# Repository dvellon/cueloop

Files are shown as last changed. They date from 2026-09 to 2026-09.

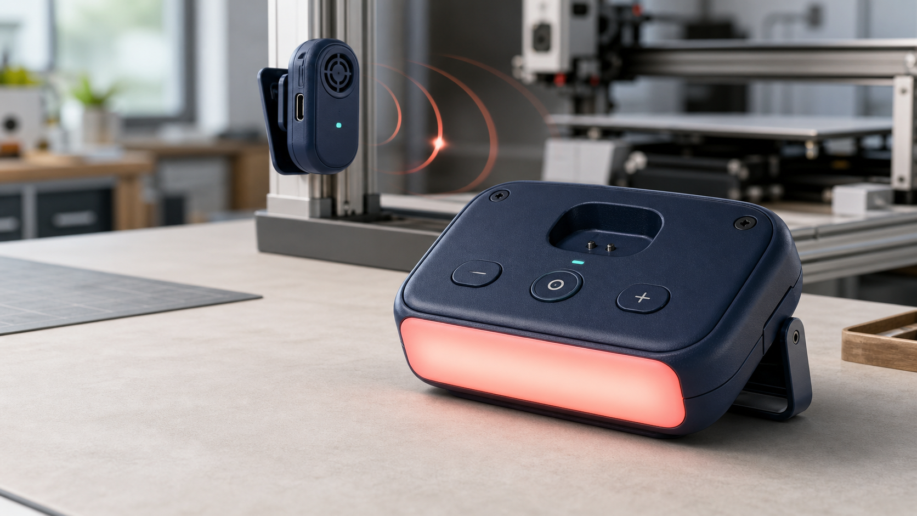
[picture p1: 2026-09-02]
assets/concepts/cueloop-bridge-cover-concept-v1.png

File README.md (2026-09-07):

# CueLoop

**Know what needs your attention without continuously listening, recording, or remaining in the same room.**

CueLoop is a private, local-first acoustic event bridge. A detachable Seeed Studio XIAO ESP32S3 Sense pod sends live microphone evidence over the local network to an Arduino UNO Q. The UNO Q performs edge inference, combines confidence across time, asks for more evidence when a result is ambiguous, and emits an accessible cue through its deterministic MCU and a local dashboard. Raw audio is discarded by default after inference.

This repository develops two related, deliberately distinct products:

- **CueLoop V1** — a reproducible social-impact prototype for the 2026 *Invent the Future with Arduino UNO Q and App Lab* competition.
- **CueLoop Bridge V2** — a portable, serviceable multi-space tool for Autodesk users, developed for *Build the Autodesk University 2027 Product*.

CueLoop is an awareness aid. It is not a safety-certified alarm, security system, or medical device, and it must not replace required alarms or supervision.

## Current state

Development began on September 1, 2026. Hardware-dependent results are intentionally separated from simulator and development-computer results. See [STATUS.md](STATUS.md), [PLAN.md](PLAN.md), [HARDWARE_TESTS.md](HARDWARE_TESTS.md), and [HARDWARE_RESULTS.md](HARDWARE_RESULTS.md) for the live record.

Both firmware targets and the exact isolated App Lab sketch profile compile on the documented Ubuntu toolchain. The complete CPython 3.13/Linux ARM64 LiteRT distribution set is version/hash audited without installation, including native AArch64 ELF inspection; target App Lab loading and inference remain physical gates. `./scripts/build_firmware.sh` performs clean, path-normalized, fixed-epoch builds; `./scripts/verify_clean_checkout.sh` reproduces the complete digital release path in a new local clone. The complete App Lab import archive can be generated locally with `python3 scripts/package_app_lab.py`; no claim is made that it has run on physical boards yet.

## Quick start

The simulator-first path runs without boards or third-party Python packages:

```bash
./scripts/demo.sh
```

The command starts a simulated CuePod, framed TCP receiver, bounded jitter/window buffer, uncertainty-aware event engine, metadata-only store, API, and accessible local dashboard at `http://127.0.0.1:8080`. Every synthetic result is visibly labeled `simulated`; it is pipeline evidence, not real sound-model evidence. Run `./scripts/test.sh` for the automated suite, `python3 scripts/audit_unoq_runtime.py --download` for the target-distribution audit, `./scripts/build_firmware.sh` for all three Arduino builds, and `./scripts/verify_clean_checkout.sh` for the release-grade fresh-checkout audit.

## Repository map

- `app_lab/` — Arduino App Lab package for the UNO Q Linux and MCU sides
- `firmware/` — standalone XIAO CuePod and UNO Q MCU firmware
- `linux/` — receiver, inference, decision engine, API, and dashboard
- `shared/` — protocol, event schema, and constants
- `simulator/` — synthetic sender, WAV replay, loss, jitter, and latency injection
- `models/` — model selection, preprocessing, conversion, provenance, and evaluation
- `experiments/` — predeclared experiment registry, schema, and result boundaries
- `benchmarks/` — evidence-labeled benchmark methods and curated summaries
- `tests/` — unit, protocol, integration, and evaluation tests
- `hardware/` — exact/estimated BOMs, wiring, schematics, power, and assembly
- `cad/` — native Fusion generator, OpenCascade reference exports/validation, parameters, DFM/provenance, and Windows evidence runbook
- `submissions/` — separate competition-ready packages and differentiation record
- `docs/` — product, architecture, privacy, safety, build, test, and demo guidance
- `user_checklists/` — short physical-action checklists and result capture locations

## Safety and privacy

- Never solder while a LiPo battery is connected.
- Never solder directly to a LiPo cell.
- Confirm polarity and continuity before first battery connection.
- Do not substitute a Qwiic cable for the battery pigtail.
- Keep Wi-Fi credentials in ignored local configuration only.
- Do not add private or copyrighted recordings to Git.

Read [docs/safety.md](docs/safety.md) before hardware work and [docs/privacy-model.md](docs/privacy-model.md) before changing audio retention behavior.

For physical work, begin with [the deadline-ordered next actions](user_checklists/NEXT_ACTIONS.md), then execute the authoritative [Windows flashing and hardware test record](HARDWARE_TESTS.md). The [short hardware bring-up checklist](user_checklists/HARDWARE_BRINGUP.md), [Windows quick guide](user_checklists/WINDOWS_FLASHING.md), and [physical validation matrix](user_checklists/PHYSICAL_VALIDATION.md) are compact views. The editable connectivity source and human schematic are under `hardware/schematics/`.

## License

Unless a file says otherwise, code, documentation, and original design source in this repository are licensed under the [MIT License](LICENSE). Third-party models, audio, code, and assets retain their own licenses and must be listed in the relevant provenance manifests.

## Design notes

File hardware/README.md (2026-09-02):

# CueLoop V1 hardware package

This folder is the source of truth for the physical V1 build. It deliberately separates confirmed manufacturer facts, development-computer build evidence, estimates, and observations that still require the received hardware.

- `BOM.md` defines the minimum working product, optional inventory-gated additions, tools, and the distinct V2 development BOM.
- `WIRING.md` defines every external V1 connection and pin assignment.
- `POWER.md` contains power paths, bandwidth arithmetic, runtime estimates, and the measurement plan.
- `ASSEMBLY.md` gives the battery-safe assembly sequence.
- `DIAGRAMS.md` contains the wireless/system, processor-responsibility, power, and protocol views.
- `schematics/cueloop_v1.netlist.json` is the machine-readable connectivity source.
- `schematics/cueloop_v1.svg` is the human-readable schematic export.

No Qwiic cable is used by the minimum CuePod. No wire connects the CuePod to the UNO Q during use. The only inter-device path is trusted-LAN Wi-Fi.

Official source facts checked September 2, 2026:

- [Arduino UNO Q 4 GB product page](https://store.arduino.cc/products/uno-q-4gb)
- [Arduino UNO Q datasheet](https://docs.arduino.cc/resources/datasheets/ABX00162-ABX00173-datasheet.pdf)
- [Seeed XIAO ESP32S3 Sense product page](https://www.seeedstudio.com/XIAO-ESP32S3-Sense-p-5639.html)
- [Seeed XIAO ESP32S3 getting-started and battery guide](https://wiki.seeedstudio.com/xiao_esp32s3_getting_started/)
- [Adafruit protected 500 mAh LiPo](https://www.adafruit.com/product/1578)
- [Adafruit JST-PH female pigtail](https://www.adafruit.com/product/261)

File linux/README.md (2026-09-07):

# UNO Q Linux application

`cueloop/` is the dependency-light core used by both the development-computer demo and the Arduino App Lab adapter. It contains strict framed-TCP packet decoding, a bounded jitter/window buffer, classifier interface, temporal event engine, metadata-only SQLite store, local API, dashboard, and simulator.

Run from the repository root with `./scripts/demo.sh`. The default classifier recognizes only synthetic test signatures and marks every result `simulated`; it is not evidence of real sound accuracy. A checksum-pinned YAMNet LiteRT adapter is available only through the explicit `--classifier yamnet --model ... --mapping ...` flags and the optional dependencies documented under `models/`.

The service has no cloud runtime dependency and no audio-file writer. V1 binds the dashboard to localhost for desktop development. The completed adapter under `app_lab/CueLoop` publishes declared TCP ports 8080 and 57321, receives length-framed CuePod audio on 57321, sends compact Bridge calls to the STM32, records MCU health notifications, and resynchronizes mute/current-cue state after an observed MCU restart. Its trusted-LAN limitation is explicit.

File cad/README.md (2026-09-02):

# CueLoop Bridge native CAD package

The contest-authoritative model is generated inside Autodesk Fusion by `fusion/CueLoopBridgeGenerator.py`. It creates native parametric components from sketches, dimensions, construction planes, extrudes, cuts, joins, fillets, named user parameters, occurrences, and captured timeline history. It does **not** import a completed mesh, STEP, BRep, or base feature.

The independent `reference/freecad_reference.py` implementation uses FreeCAD/OpenCascade on Ubuntu to generate and reopen real STEP solids. Its committed exports provide automated geometric evidence, but they are explicitly non-authoritative and must not be submitted in place of the Fusion `.f3d`.

## Source and evidence map

| Artifact | Purpose | Authority |
|---|---|---|
| `design_parameters.json` | Versioned millimeter dimensions, manufacturing values, placements, and hardware envelopes | Shared design source; measurement gates remain |
| `design_contract.json` | Required components, roles, provenance, minimum native counts, and output structure | Automated acceptance contract |
| `fusion/CueLoopBridgeGenerator.py` | Builds and exports native Fusion design | Authoritative contest generator |
| `reference/freecad_reference.py` | Independent OpenCascade solid implementation | Reference/validation only |
| `reference_exports/` | Editable FCStd reference, reopened STEP evidence, per-part STEP/STL, reports, and hashes | Development-computer CAD evidence only |
| `validate_cad.py` | Dependency-free parameter/output validator | Host acceptance tool |
| `FUSION_WINDOWS_RUNBOOK.md` | Exact Windows run, evidence, visual review, return, and hash workflow | Operator procedure |
| `PROVENANCE.md` | Original-versus-vendor/estimated geometry boundary | Submission claim control |
| `PCBWAY_DFM.md` | Production-process assumptions and outstanding DFM gates | Manufacturing handoff |
| `DIMENSION_VALIDATION.md` | Physical caliper, fit, cable, battery, and coupon checks | Required before manufacture |

## Native component hierarchy

The Fusion Browser should contain:

```text
CueLoop Bridge Native Parametric Assembly
├── CuePod_Microphone_Module
│   ├── CuePod_Bottom
│   ├── CuePod_Top                    (exploded upward)
│   ├── Reference_XIAO_Sense
│   ├── Reference_LiPo_500mAh
│   └── Reference_Microphone_Cartridge
└── Receiver_Assembly
    ├── Receiver_Bottom
    ├── Receiver_Top                  (exploded upward)
    ├── Receiver_Carry_Clip           (exploded behind)
    ├── Alert_Diffuser
    ├── Reference_UNO_Q
    ├── Reference_Support_Electronics
    └── Reference_Haptic_LED_Module
```

The six manufacturing components each finish as one closed solid. Their native feature histories include open-shell cavity cuts, M2 boss/pilot or clearance geometry, lid lips, an elevated battery-clearing XIAO bridge, UNO supports, dock tongue/pocket/rails, microphone ports, USB/power/cable/ventilation/LED/button openings, noncompressive battery restraint rails, and a connected carry clip.

## Automated Ubuntu reference run

The development run uses official FreeCAD 1.1.3 x86_64 AppImage release asset `FreeCAD_1.1.3-Linux-x86_64-py311.AppImage`:

```text
SHA-256: 3a853eb69ee595f779f2255dbf80a765926981d8ff68903cefee4dfb03a8f5ef
Source: https://github.com/FreeCAD/FreeCAD/releases/tag/1.1.3
```

The binary and extracted runtime live under ignored `.tools/`; they are not redistributed. A system `FreeCADCmd`, `freecadcmd`, or the extracted verified AppImage can run:

```bash
./scripts/run_cad_reference.sh
python3 cad/validate_cad.py --reference-output cad/reference_exports
```

The current reference run produced an editable `.FCStd`, 12 valid/closed/positive-volume solids, an assembly STEP that reopened as 12 solids, and zero overlap for all 12 forbidden enclosure/envelope and envelope/envelope pairs. The host validator verifies the parameter math, object set, exact bounds, vertical/electronics clearances, per-part STEP/STL structure, report boundary, and SHA-256 manifest. This proves CAD-program continuity and neutral-export integrity, not physical fit or Autodesk-native history.

## Fusion exports

On a successful Windows Fusion run, the script creates `exports/CueLoop_Bridge_Native_v2/` beside the script with:

```text
CueLoop_Bridge_Native.f3d
CueLoop_Bridge_Native.step
CueLoop_Bridge_parameters.json
CueLoop_Bridge_BOM.json
CueLoop_Bridge_BOM.csv
CueLoop_Bridge_validation.json
CueLoop_Bridge_source_manifest.json
README.txt
SHA256SUMS.txt
sources/
  CueLoopBridgeGenerator.py
  design_parameters.json
  design_contract.json
manufacturing/
  Alert_Diffuser.{step,stl,3mf}
  CuePod_Bottom.{step,stl,3mf}
  CuePod_Top.{step,stl,3mf}
  Receiver_Bottom.{step,stl,3mf}
  Receiver_Carry_Clip.{step,stl,3mf}
  Receiver_Top.{step,stl,3mf}
```

The `.f3d` and assembly STEP are self-contained exports through Fusion `ExportManager`. The six per-part STEP/STL/3MF sets are production candidates only after visual, dimensional, fit, material/process, and PCBWay DFM review.

## Official Fusion API basis

The implementation follows Autodesk's current APIs:

- [Fusion `Design.designType`](https://help.autodesk.com/cloudhelp/ENU/Fusion-360-API/files/Design_designType.htm) for parametric history;
- [`UserParameters.add`](https://help.autodesk.com/cloudhelp/ENU/Fusion-360-API/files/UserParameters_add.htm) and expression-backed `ValueInput` objects;
- [`DistanceExtentDefinition.create`](https://help.autodesk.com/cloudhelp/ENU/Fusion-360-API/files/DistanceExtentDefinition_create.htm) with `setOneSideExtent` rather than the retired `setDistanceExtent`;
- [`ExportManager`](https://help.autodesk.com/cloudhelp/ENU/Fusion-360-API/files/ExportManager.htm) and `execute` for F3D, STEP, STL, and 3MF;
- [`createFusionArchiveExportOptions`](https://help.autodesk.com/cloudhelp/ENU/Fusion-360-API/files/ExportManager_createFusionArchiveExportOptions.htm) for the self-contained archive;
- [`createC3MFExportOptions`](https://help.autodesk.com/cloudhelp/ENU/Fusion-360-API/files/ExportManager_createC3MFExportOptions.htm) for 3MF manufacturing output.

Proceed with [the exact Windows procedure](FUSION_WINDOWS_RUNBOOK.md). Do not manufacture from any output until [the dimension checklist](DIMENSION_VALIDATION.md) and [PCBWay DFM gates](PCBWAY_DFM.md) are complete.

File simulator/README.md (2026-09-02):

# CuePod simulator

The canonical simulator implementation is `linux/cueloop/simulator.py`; `cuepod_sim.py` is a source-tree wrapper. It uses the exact production packet encoder and supports:

- deterministic synthetic event signatures;
- mono PCM16 16 kHz WAV replay;
- random packet loss;
- bounded timing jitter and fixed initial latency;
- adjacent-packet reordering;
- periodic stream restart with sequence/sample-clock reset;
- finite runs for automated smoke tests.

Synthetic signatures are deliberately easy for the simulation classifier and are labeled `simulated`. They validate plumbing and uncertainty policy, not model accuracy.

```bash
PYTHONPATH=linux python3 simulator/cuepod_sim.py \
  --sequence 'background:2,door_knock:4,background:2,alarm_beep:4' \
  --loss 0.05 --jitter-ms 15 --reorder-rate 0.02
```

Recordings are ignored by Git. Only use self-recorded or legally reusable audio with a completed provenance manifest.

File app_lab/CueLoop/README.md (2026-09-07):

# CueLoop Arduino App

CueLoop turns selected nearby sounds into private, visible cues. A XIAO ESP32S3 Sense CuePod sends memory-only 16 kHz PCM over a trusted local network; the UNO Q Linux processor runs a checksum-pinned YAMNet baseline and a temporal confirmation engine; the UNO Q STM32 owns deterministic LED, optional haptic/buzzer, health, and acknowledgement timing.

## Before import

From the repository root, run `python3 scripts/sync_app_lab.py --include-model`. This copies the canonical tested Linux modules, dashboard, MCU sketch, class mapping, UNO Q runtime audit records, and the locally downloaded checksum-verified model into this self-contained folder. Model binaries are deliberately excluded from Git. The sync command fails if the source artifact is absent or its SHA-256 differs from the pinned manifest.

Import the `app_lab/CueLoop` folder in Arduino App Lab and deploy it to an UNO Q. App Lab installs the complete pinned Python dependency set and the pinned sketch profile. The Linux log begins with a runtime identity line containing Python, machine, libc, and resolved LiteRT version; retain it with the App Lab version. On the same trusted LAN, configure the CuePod receiver address to the UNO Q and TCP port 57321. Open port 8080 at the UNO Q address for the dashboard.

No Wi-Fi credentials or API keys belong in this App. Raw PCM remains in volatile memory and is discarded after inference; only bounded event/feedback metadata is stored under the visible `data` folder. V1 TCP and the dashboard are unencrypted and unauthenticated, so use an isolated or trusted LAN—not a public or hostile network.

The committed runtime audit proves that the required binary distributions exist for Arduino's documented CPython 3.13/Linux ARM64 runner tuple; it does not prove installation, dynamic loading, or inference on the received board. Compilation and host tests likewise do not prove physical Bridge transport, LED polarity/brightness, CuePod audio quality, model accuracy, Wi-Fi range, battery runtime, or end-to-end latency. Complete the repository hardware checklist before presenting any of those as measured results.

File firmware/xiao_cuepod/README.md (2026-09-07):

# XIAO ESP32S3 Sense CuePod firmware

This sketch captures the Sense expansion board's PDM microphone as 16 kHz mono PCM16, emits one checksummed 684-byte CueLoop packet every 20 ms over a persistent TCP connection, validates receiver heartbeats, reconnects Wi-Fi and the receiver with bounded backoff, and keeps diagnostic counters. It contains no filesystem or raw-audio recording path.

## Pinned build target

- Arduino CLI 1.5.1
- `esp32:esp32` 3.3.11
- FQBN `esp32:esp32:XIAO_ESP32S3`
- Core libraries only: `ESP_I2S`, `WiFi`, and `Preferences`
- Default board options shown by Arduino CLI; no PSRAM dependency

Build from the repository root:

```bash
./scripts/build_firmware.sh
```

The builder compiles both project targets and the App Lab profile so their shared release evidence cannot drift. For the ESP32 image it also cleans intermediates, fixes the reproducible build epoch, and normalizes checkout-root paths before hashing. Ad-hoc Arduino CLI builds remain valid compile checks but their embedded compile time/path digest may differ. The `build/` directory and binary products are ignored. No extra Arduino library install is required.

## Configure without source credentials

Flash over USB, open a 115200-baud serial terminal with line ending LF, and send tab-separated commands. Passwords are written directly to ESP32 NVS and never echoed. They do not enter this repository.

```text
SET_WIFI<TAB>your-ssid<TAB>your-password
SET_RECEIVER<TAB>192.168.1.50<TAB>57321
SET_POD_ID<TAB>0xC0E10001
POWER<TAB>USB
TEST<TAB>ON
STATUS
```

`<TAB>` means an actual tab character. `HELP` prints the command list. `STREAM OFF` pauses transmission without recording anything; `ERASE` removes all saved CuePod configuration and restarts. Switch `TEST OFF` before microphone evaluation. Set `POWER BATTERY` after disconnecting USB so packet metadata remains honest; the installed board variant cannot automatically distinguish USB from battery power.

The pod opens a persistent TCP connection to receiver port 57321. Each CueLoop protocol payload is preceded by a two-byte big-endian length, allowing complete packets and acknowledgements to be recovered from the TCP byte stream. The receiver returns a framed acknowledgement about once per second. Five seconds without a valid matching CRC heartbeat sets `reachable=no`, increments `receiver_timeouts`, reconnects with bounded backoff, and marks the next packets as a restarted stream. This is reachability diagnostics, not authentication or encryption.

`STREAM OFF` closes the receiver connection and suppresses reconnect attempts until streaming is enabled again. `STATUS` also reports the most recent 20 ms frame's integer RMS and peak plus a cumulative clipped-sample count. In test-tone mode RMS/peak should be approximately 8192 with zero clipping. In microphone mode, nonzero changing values confirm only that samples vary; they do not establish acoustic-model accuracy.

## Battery telemetry boundary

The installed `XIAO_ESP32S3` variant does not expose a verified battery ADC pin/divider for this exact hardware revision, so the default firmware sends battery voltage `0` with `BATTERY_VALID` clear. Do not manufacture a voltage from an unverified pin.

If the physical board schematic and multimeter confirm a battery divider, create ignored `cuepod_hardware.local.h`, override the ADC pin and rational scale, then compare reported millivolts against the meter at multiple voltages before accepting telemetry. Never connect or solder a LiPo while powered; follow the project safety checklist.

## Hardware test still required

Compilation proves APIs and types only. The real board must confirm microphone waveform/non-clipping, pin orientation, Wi-Fi association, TCP connection and heartbeat, receiver timeout/recovery, USB/battery metadata, and safe current/runtime. Append observations under the matching root `HARDWARE_TESTS.md` ID, then copy reviewed summaries to `HARDWARE_RESULTS.md`; do not reinterpret test-tone behavior as acoustic-model accuracy.

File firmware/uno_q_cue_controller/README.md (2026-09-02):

# UNO Q STM32 cue-controller firmware

This sketch gives the STM32U585 deterministic ownership of physical cue timing. Linux sends compact Bridge RPC commands; the MCU validates them, generates nonblocking LED/haptic/buzzer patterns, debounces an optional acknowledgement button, reports health, and stops outputs immediately on clear/mute.

## Pinned dependencies and compile

- Arduino CLI 1.5.1
- `arduino:zephyr` 0.90.0
- FQBN `arduino:zephyr:unoq`
- `Arduino_RouterBridge` 0.4.3
- `Arduino_RPClite` 0.3.0 (RouterBridge dependency)

```bash
./scripts/build_firmware.sh
```

The builder compiles this canonical sketch and the isolated App Lab profile from clean intermediates, then requires their `.bin` and `.bin-zsk.bin` files to be byte-identical. The ignored artifact folder is retained for later Windows flashing. Compilation does not prove LED polarity, brightness, button wiring, optional actuator current, or Bridge operation on a physical UNO Q.

## Bridge interface

| RPC / notification | Direction | Arguments / result |
|---|---|---|
| `cueloop/cue` | Linux → MCU call | `event_id`, class code 1–4, priority 1–3, confidence 0–1000; returns accepted boolean |
| `cueloop/clear` | Linux → MCU call | event ID (or empty for current); returns boolean |
| `cueloop/mute` | Linux → MCU call | boolean; returns actual muted state |
| `cueloop/heartbeat` | Linux → MCU call | Linux uptime milliseconds; returns MCU uptime milliseconds |
| `cueloop/status` | Linux → MCU call | no arguments; returns compact status string |
| `cueloop/ack` | MCU → Linux notification | acknowledged event ID |
| `cueloop/mcu_status` | MCU → Linux notification | uptime, health, active/muted state, counters |

Class codes are 1 door knock, 2 alarm/beep, 3 dog bark, and 4 attention call. LED3 carries event color and priority pulse cadence; LED4 is green for a healthy Linux heartbeat, blue when muted, and blinking red when Bridge/Linux health is unavailable. Both onboard MCU RGB LEDs are active low at the GPIO layer; the sketch follows Arduino's documented digital/PWM APIs.

## Optional hardware

The minimum build needs no external actuator: onboard LEDs provide the physical cue. A normally-open button from D4 to GND enables immediate acknowledgement; without it, the pull-up remains inactive and dashboard acknowledgement still works. Optional active-high haptic/buzzer pins can be set in ignored `cue_controller_hardware.local.h` only after the driver/transistor/current path is documented—do not drive a motor directly from an MCU GPIO.

Record physical Bridge, LED, debounce, cue-timing, and restart observations under H-005 through H-009/H-305 in root `HARDWARE_TESTS.md`, then copy reviewed summaries to `HARDWARE_RESULTS.md`.

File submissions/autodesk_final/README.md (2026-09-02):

# CueLoop Bridge Autodesk final-package workspace

This directory begins the December **Build the Autodesk University 2027 Product** package without conflating it with CueLoop V1 or destabilizing the September deadlines. It is a development contract, not a claim that the V2 product, PCBWay parts, Fusion Electronics, portability, or final evidence already exists.

## Artifact map

| Required V2 dimension | Working source | Evidence needed for completion |
|---|---|---|
| Shared V1 foundation | `../DIFFERENTIATION.md`, repository protocol/model/policy modules | exact shared commit/license attribution; no duplicate-winning-entry conflict |
| New hardware | `V2_DEVELOPMENT_PLAN.md`, future versioned BOM | received part identities, electrical verification, schematic/netlist, physical build |
| New interactions | `V2_DEVELOPMENT_PLAN.md` | tested portable visual/haptic/tactile cue language and user feedback |
| New CAD | `cad/` native Fusion generator and validated OpenCascade reference, future returned Fusion archive | measured parameters, genuine native `.f3d`, drawings, assembly, fit revisions |
| New manufacturing | `MANUFACTURING_PLAN.md` | PCBWay process/quote/order records, DFM revisions, inspection and assembly results |
| New testing | `EVIDENCE_MATRIX.md`, `HARDWARE_TESTS.md` | portable/dock/clip/drop/acoustic/thermal/runtime/recovery results |
| Autodesk-user workflow | `FINAL_ARTICLE_OUTLINE.md` | observed creator workflow with a machine/process and user-relevant outcome |
| Eligibility differentiation | `../DIFFERENTIATION.md`, final audit | visibly distinct story, enclosure, hardware, interaction, testing, and media |

## Current maturity

- Production-intent native Fusion automation, a 125-value design source, six manufacturing components, independent 12-solid OpenCascade validation/reference exports, DFM/provenance records, and an explicitly conceptual cover raster exist.
- The shared V1 protocol, receiver, model adapter, temporal engine, privacy boundary, and UNO Q split exist digitally.
- No V2 receiver portability subsystem, haptic hardware, dock/charge implementation, Fusion Electronics carrier, PCBWay part, manufactured enclosure, Fusion-generated `.f3d`, or physical V2 result has been observed. The reference STEP is not the authoritative contest model.
- The September Autodesk application still requires the entrant's public Hackster URL, truthful biography, Windows Fusion C-100 native run/inspection/export, and account submission.

## Package files

- `V2_DEVELOPMENT_PLAN.md` — scope, workstreams, milestones, decision gates, and schedule.
- `MANUFACTURING_PLAN.md` — process selection, DFM, assembly, quality, and approximately-750-unit thinking.
- `EVIDENCE_MATRIX.md` — claim-to-test traceability and evidence-tier rules.
- `FINAL_ARTICLE_OUTLINE.md` — polished final story structure and media assignments.
- `SUBMISSION_CHECKLIST.md` — December rubric/account preflight.

All future V2 artifacts must preserve the V1 safety/privacy claim boundaries and add a clear provenance/evidence label. A preliminary or rendered state never becomes a physical/manufacturing result by appearance alone.

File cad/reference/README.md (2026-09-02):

# Ubuntu OpenCascade reference pipeline

`freecad_reference.py` builds a second implementation of the CueLoop geometry from `cad/design_parameters.json` using FreeCAD's OpenCascade kernel. It saves and reopens an editable FCStd, exports and reopens the assembly STEP, exports per-part STEP/STL files, evaluates forbidden intersections, and records validity, closedness, solid count, volume, area, bounding boxes, provenance, and hashes.

This model is deliberately **not authoritative** for the Autodesk submission. It exists to detect parameter, boolean, solid, and export defects on Ubuntu before the native `adsk` script is run. The contest archive must be the `.f3d` created directly by `cad/fusion/CueLoopBridgeGenerator.py`, with a visible Fusion timeline, native sketches/features, named parameters, and component hierarchy.

The generator labels every vendor-derived or estimated hardware shape as a simple placement envelope. It neither contains nor claims original vendor board, connector, microphone-package, or battery geometry.

Run the pinned local tool path with:

```bash
./scripts/run_cad_reference.sh
python3 cad/validate_cad.py --reference-output cad/reference_exports
```

The runner expects the checksum-verified FreeCAD 1.1.3 AppImage in ignored `.tools/`, or a `FreeCADCmd`/`freecadcmd` command already installed. See `cad/README.md` for acquisition and checksum details.

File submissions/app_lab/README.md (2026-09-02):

# CueLoop App Lab submission package

This directory contains the judge-facing source copy for **Invent the Future with Arduino UNO Q and App Lab**. It is a publication workspace, not a record of results that have not happened.

## Publish from these files

| Hackster field or asset | Source |
|---|---|
| Title, subtitle, tags, category | `SUBMISSION_METADATA.md` |
| Full project story and build instructions | `PROJECT_ARTICLE.md` |
| Source-code orientation | `SOURCE_GUIDE.md` |
| Troubleshooting | `TROUBLESHOOTING.md` |
| Three-minute video and cutdowns | `VIDEO_PACKAGE.md` |
| Photos/screenshots to capture | `PHOTO_SHOT_LIST.md` |
| Truthful result table | `TEST_RESULTS.md` |
| Judging-criteria evidence audit | `RUBRIC_REVIEW.md` |
| Media/source credits | `LICENSES_AND_ATTRIBUTION.md` |
| Final account-controlled actions | `SUBMISSION_CHECKLIST.md` |

The authoritative detailed procedure/observation log is repository-root `HARDWARE_TESTS.md`; `HARDWARE_RESULTS.md` is its reviewed publication summary. Copy measured values into submission copy only after both preserve hardware revision, conditions, units, evidence tier, and pass/fail status.

## Release attachments

Attach these artifacts after checking their SHA-256 sidecars:

1. the self-contained Arduino App Lab import archive generated by `scripts/package_app_lab.py`;
2. the clean source release generated by `scripts/package_source_release.py`;
3. the readable SVG schematic from `hardware/schematics/cueloop_v1.svg`;
4. the final video or its stable public link.

Do not attach the downloaded model separately, raw evaluation audio, databases, credentials, build trees, or private working files. The App Lab archive contains the verified model only because it is required at runtime; its internal manifest records the digest and upstream license.

## Publication rule

Renderings, simulator screens, development-host measurements, UNO Q measurements, and physical CuePod measurements must remain explicitly labeled. If a physical gate fails before the deadline, publish the failure and narrow the claim or vocabulary; never replace it with a simulated success.

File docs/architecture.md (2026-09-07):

# System architecture

## Runtime view

```mermaid
flowchart LR
  MIC[PDM microphone<br/>16 kHz mono] --> POD[XIAO CuePod<br/>frame + CRC + telemetry]
  POD -->|framed TCP PCM<br/>local Wi-Fi| RX[UNO Q Linux<br/>receiver + bounded buffer]
  RX --> WIN[windowing + normalization]
  WIN --> MODEL[local model adapter]
  MODEL --> ENGINE[temporal evidence<br/>confirmation + cooldown]
  ENGINE --> STORE[(metadata + feedback<br/>no raw audio)]
  ENGINE --> API[local API + dashboard]
  ENGINE -->|Bridge RPC<br/>compact cue| MCU[STM32 cue controller]
  MCU --> OUT[LED / haptic / buzzer]
  MCU -->|acknowledge input| ENGINE
```

## Responsibility split

| Component | Owns | Must not own by default |
|---|---|---|
| XIAO ESP32S3 Sense | PDM capture, framing, CRC, pod identity, local configuration, Wi-Fi reconnect, basic telemetry, test tone | Classification, raw-audio files, cloud upload |
| UNO Q Linux MPU | TCP stream receive/framing, sequence-gap accounting, bounded audio buffer, preprocessing, model inference, temporal policy, metadata/feedback, API/dashboard | Unbounded raw audio, safety guarantees, precise actuator timing |
| UNO Q STM32 MCU | Buttons, acknowledgement, LED/haptic/buzzer patterns, health heartbeat/watchdog indication | Audio inference, history database, network configuration |
| Browser | Local presentation and user commands | Cloud analytics, raw-audio replay |

## Data lifecycle

1. The pod samples signed PCM and sends one 20 ms packet.
2. The receiver verifies magic/version/length/CRC, records arrival metadata, and orders frames in a bounded jitter buffer.
3. A missing frame becomes explicit zero fill plus a loss metric; it never blocks indefinitely.
4. Completed inference windows are converted to float32 in `[-1, 1]` and passed to the configured local model.
5. Broad model outputs map into the small CueLoop vocabulary.
6. The temporal engine updates state: `idle → observing → confirming → alerting → cooldown`, with class-specific evidence, hysteresis, and priority.
7. Only structured metadata is emitted and stored. The source samples are released once no active window needs them.
8. User feedback links to an event ID and policy context, never an audio blob.

## Failure behavior

- Bad magic/version/length/CRC: drop and count.
- Duplicate/late packet: drop and count.
- Gap: count missing sequence numbers, insert bounded silence, continue.
- Pod timeout: dashboard changes to disconnected; active unconfirmed evidence expires.
- Model failure: health becomes degraded; do not invent labels; physical cue switches to fault pattern only if configured.
- Bridge unavailable: Linux/dashboard remains operational and retries with a bounded backoff.
- Database unavailable: retain a bounded in-memory event list and flag degraded persistence.
- Process restart: reconstruct configuration and event metadata, never raw audio.

## Trust boundary

V1 TCP is designed for a trusted private LAN and provides ordered delivery plus corruption detection, not confidentiality or strong authentication. It must not be exposed to the public internet. Pairing uses an explicit locally configured receiver address and pod identifier. V2 should evaluate authenticated encryption after profiling and export review; V1 documentation makes the limitation prominent.

## Deployment shapes

- **Development computer:** same core pipeline, simulator sender, standard Python runtime, browser at localhost.
- **UNO Q standalone:** App Lab Python entry imports the core package, Bridge adapter is enabled, dashboard binds the declared local port, XIAO sends to the board's LAN address.
- **Fallback demo:** WAV replay or synthetic signatures, visibly labeled “SIMULATED INPUT”; never used as physical proof.

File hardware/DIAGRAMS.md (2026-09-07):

# System and protocol diagrams

## Wireless system block diagram

```mermaid
flowchart LR
  MIC[Integrated PDM mic] --> XIAO[XIAO ESP32S3 Sense\n16 kHz PCM + framing]
  BAT[Protected 1-cell LiPo] --> XIAO
  XIAO -->|Wi-Fi TCP 57321\ntrusted LAN| RX[UNO Q Linux receiver]
  RX --> MODEL[YAMNet + class map]
  MODEL --> POLICY[temporal confirmation\npriority + cooldown]
  POLICY --> UI[local dashboard :8080]
  POLICY -->|Bridge compact RPC| MCU[UNO Q STM32]
  MCU --> LED3[LED3 event cue]
  MCU --> LED4[LED4 health/mute]
  BTN[optional D4 button] --> MCU
  MCU -->|Bridge acknowledgement| POLICY
```

## Linux/MCU responsibility diagram

```mermaid
flowchart TB
  subgraph Linux[UNO Q Qualcomm / Debian]
    TCP[TCP stream framing\nsequence gaps + reconnects]
    AI[inference + temporal policy]
    DB[bounded event/feedback SQLite]
    WEB[REST + dashboard]
  end
  subgraph MCU[UNO Q STM32U585 / Zephyr]
    RPC[RPC validation + heartbeat]
    TIME[nonblocking cue timing]
    IO[LEDs + optional button/driver]
  end
  TCP --> AI
  AI --> DB
  AI --> WEB
  AI -->|cue / clear / mute / heartbeat| RPC
  RPC --> TIME --> IO
  IO -->|ack / status| AI
```

Linux owns uncertain/high-level work; the MCU owns bounded physical timing. If Bridge fails, inference/dashboard remain alive and report degradation. If the MCU restarts, a lower uptime status triggers mute/current-cue resynchronization.

## Power path diagram

```mermaid
flowchart LR
  USBX[XIAO USB-C 5 V\ndevelopment/charge] --> PMIC[XIAO onboard\npower management]
  LIPO[Adafruit 1578\n3.7 V protected LiPo] -->|JST-PH + verified pigtail\nBAT+ / BAT-| PMIC
  PMIC --> POD[XIAO + Sense microphone]

  USBQ[Approved UNO Q USB-C path\n5 V, supply capability up to 3 A] --> UNO[UNO Q MPU + MCU]

  POD -. Wi-Fi only; no shared power .-> UNO
```

## Battery connection diagram

```mermaid
flowchart LR
  B1P[B1 protected LiPo +] --> J1P[J1 measured + lead]
  J1P --> U1P[XIAO BAT+\nfarther from USB-C]
  B1N[B1 protected LiPo -] --> J1N[J1 measured - lead]
  J1N --> U1N[XIAO BAT-\nclosest to USB-C]
```

The battery is detached while J1 is soldered. Connector orientation and voltage—not red/black insulation—determine polarity.

## Network protocol sequence

```mermaid
sequenceDiagram
  participant Pod as XIAO CuePod TCP client
  participant Linux as UNO Q Linux :57321
  participant Model as Local model/policy
  participant MCU as UNO Q STM32
  participant UI as Browser :8080
  loop every 20 ms
    Pod->>Linux: 2-byte length + 684-byte PCM v1 packet
  end
  Linux-->>Pod: 2-byte length + 24-byte CRC ACK, at most once/s
  Linux->>Model: normalized bounded window
  Model-->>Linux: class scores + inference time
  Note over Linux: require temporal evidence; apply cooldown/mute
  Linux->>MCU: cueloop/cue(event, class, priority, permille)
  MCU-->>Linux: accepted boolean
  Linux-->>UI: event metadata/status JSON
  UI->>Linux: acknowledge / dismiss / mute
  Linux->>MCU: clear or mute
  MCU-->>Linux: button ack and periodic bounded status
```

CRC detects accidental corruption; it does not authenticate or encrypt. Do not deploy V1 on an untrusted network.

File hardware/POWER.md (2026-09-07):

# Power and bandwidth analysis

Every value below is labeled. Manufacturer figures are not measurements of CueLoop firmware.

## Power domains

CueLoop V1 has two independent power domains:

1. The UNO Q uses its documented USB-C power path. Arduino specifies a 5 V supply with up to 3 A capability; the exact ordered supply/hub must be inventoried before use. CueLoop does not power the CuePod or any actuator from the UNO Q.
2. The CuePod uses XIAO USB-C during development or one protected 3.7 V nominal LiPo on the XIAO battery pads. The XIAO's onboard management circuit owns power selection/charging. Never apply a battery to the 5 V pin.

The domains communicate only by Wi-Fi. There is no ground loop or cross-power cable.

## CuePod estimate

Known manufacturer data:

- Battery: 500 mAh at 3.7 V nominal, approximately 1.9 Wh; protected; 4.2 V full; Adafruit says CC/CV charge at 500 mA or less.
- Seeed's current XIAO ESP32S3 Series table reports representative Sense workloads around 64.5 mA average for microphone recording plus SD and 110 mA with Wi-Fi active on the expansion-board configuration. Those are separate manufacturer workloads, not additive CueLoop measurements.
- The implemented workload continuously captures PDM and transmits Wi-Fi; camera and SD are unused.

Planning range (**estimated**): 110–170 mA average. With an 80% usable-capacity planning factor:

| Assumed average current | Ideal `500 mAh / I` | 80%-capacity planning runtime |
|---:|---:|---:|
| 110 mA | 4.55 h | 3.64 h |
| 140 mA | 3.57 h | 2.86 h |
| 170 mA | 2.94 h | 2.35 h |

Use **about 2.4–3.6 hours estimated**, never “measured battery life,” until the physical CuePod runs a timed discharge test. Wi-Fi retries, cell age, protection cutoff, temperature, regulator efficiency, and signal strength can materially change it.

The current Seeed page clearly documents battery power management and pad polarity but its charge-current table formatting is ambiguous across the base, Sense, and Plus variants. Do not publish a CuePod charge-time claim until the received PCB revision is identified and charge current is measured or unambiguously traced from its matching schematic.

## Network bandwidth

Protocol v1 sends 50 framed audio packets per second over one persistent TCP connection:

| Layer | Arithmetic | Rate |
|---|---:|---:|
| PCM payload only | 640 B × 50 | 32,000 B/s = 256.0 kbit/s |
| CueLoop packet | 684 B × 50 | 34,200 B/s = 273.6 kbit/s |
| Two-byte stream framing | 2 B × 50 | 100 B/s = 0.8 kbit/s |
| IPv4 + TCP minimum | (686 + 20 + 20) B × 50 | 36,300 B/s = 290.4 kbit/s |
| Framed receiver ACK | 26 B once/s, plus TCP/IP acknowledgement traffic | negligible relative to audio |

TCP acknowledgements/segmentation, 802.11 framing, contention, retries, and link-layer security add overhead, so measured airtime and interface throughput will be higher. The application stays well below the nominal capacity of a healthy private 2.4 GHz Wi-Fi link, but physical reconnect, gap, and latency testing remains required.

## Measurement plan

### Safe first-pass power evidence

1. Run the XIAO from USB with the battery detached. Confirm test tone, microphone mode, Wi-Fi, and temperature before battery use.
2. For battery runtime, fully charge under supervision, disconnect USB, record start/end time and firmware counters, and stop at normal protected shutdown. This avoids opening the battery path with a meter.
3. If current is required, prefer a suitable inline USB power meter for USB mode. It is not in the confirmed inventory.

### Optional series-current test with the AstroAI meter

Only attempt this if the meter manual, fuse rating, and lead jacks are understood and a protected break-out/test harness exists. Do not improvise by holding loose probes against LiPo connector contacts.

1. Disconnect USB and battery first.
2. Put the black lead in COM and red lead in the meter's documented high-current jack; select DC current at the highest safe range.
3. Insert the meter **in series** in a protected positive-lead test harness: battery positive → meter → CuePod positive. Keep battery negative directly connected.
4. Check polarity and insulated connections before mating the battery, then power briefly and step down range only if the reading and fuse limit make that safe.
5. Disconnect battery before moving a lead or changing the circuit. Return the red lead to the voltage/ohms jack immediately afterward.

Never place an ammeter directly across battery positive and negative; that is a short circuit.

## Required result fields

Record average/peak method, meter/tool identity, cell voltage, firmware mode, Wi-Fi RSSI, duration, temperature observation, shutdown behavior, and evidence tier under H-307 through H-310 in root `HARDWARE_TESTS.md`; copy reviewed summaries to `HARDWARE_RESULTS.md`.

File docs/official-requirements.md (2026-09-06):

# Official requirements and source check

**Checked:** September 5, 2026 (America/New_York)
**Policy:** use primary organizer/manufacturer sources; recheck before submission because organizers reserve the right to change dates.

**September 5 recheck:** the live Hackster FAQ and organizer-authored application guide still show the September 7 hardware-application deadline and the same five application prompts. The visible rules-template placeholders remain.

## Competition 1: Invent the Future with Arduino UNO Q and App Lab

Official Hackster contest pages confirm:

- Submission closes **September 13, 2026 at 11:59 PM PDT**.
- The project must use Arduino UNO Q, address a real-world challenge with AI, be in English, and include a name, short description, cover image, BOM, complete instructions, images, and relevant source resources such as code, schematics, and CAD.
- Judging is documentation 30, BOM 20, schematics 15, code/contribution 15, creativity 20.
- Best Social Impact and Best in Show are active prize categories.
- The entry must be original and cannot already have been selected as a winner in another Hackster contest.
- Licensed third-party material must be properly permitted and attributed.

Primary sources:

- [Contest overview](https://www.hackster.io/contests/invent-the-future-with-arduino-uno-q-and-app-lab)
- [Specific rules](https://www.hackster.io/contests/invent-the-future-with-arduino-uno-q-and-app-lab/rules)
- [Official FAQ](https://www.hackster.io/contests/invent-the-future-with-arduino-uno-q-and-app-lab/faq)

## Competition 2: Build the Autodesk University 2027 Product

Official Hackster pages and the organizer-authored guide confirm:

- Hardware applications close **September 7, 2026 at 11:59 PM PDT**.
- Final entries close **December 20, 2026 at 11:59 PM PST**.
- The application must answer all five application prompts and link to a started Hackster project with a name, elevator pitch, cover render/image, beginning BOM, story, UNO Q, Autodesk Fusion, and a preliminary Fusion design/dataset `.f3d` attachment.
- The product must be a compact smart accessory that can be worn, attached, clipped, or carried; it should be handheld, legally carry-on safe, useful beyond the conference, and useful to Autodesk customers.
- The final entry must use UNO Q and Autodesk Fusion, include its `.f3d`, a PCBWay enclosure, video/photos of the prototype in action, BOM, schematics, code, and English documentation.
- Judging is creativity 30, documentation 20, BOM 20, schematics 10, Fusion 10, code/contribution 10.
- The Best AU 2027 Product Concept may be manufactured in approximately 750 units, making manufacturability and serviceability central.

Primary sources:

- [Contest overview](https://www.hackster.io/contests/autodesk-university-2027-product)
- [Specific rules](https://www.hackster.io/contests/autodesk-university-2027-product/rules)
- [Organizer project/application guide](https://www.hackster.io/jessalyn/project-guide-build-the-autodesk-university-2027-product-b9aa9f)

### Official-source discrepancy

The Autodesk specific-rules and FAQ pages contain visible, unfilled boilerplate such as `[sponsor name - platform]`, `[featured technology]`, and example categories unrelated to this contest. The dates, documentation requirements, and rubric are populated. CueLoop follows the more specific contest overview and organizer project guide: Arduino UNO Q, Autodesk Fusion, PCBWay, portable accessory, project link, preliminary `.f3d`, BOM, render, and full application answers. A screenshot/PDF of the live rules should be retained by the entrant near submission time if the placeholders remain.

## UNO Q and App Lab technical facts

Arduino's current product and App Lab documentation confirm:

- UNO Q combines a Qualcomm Dragonwing QRB2210 MPU running Debian Linux with an STM32U585 MCU running Arduino sketches over Zephyr OS.
- The specified 4 GB / 32 GB unit is SKU ABX00173; the brief's configuration is compatible with the 4 GB recommendation for SBC/App Lab workloads.
- App Lab Apps use a mandatory `app.yaml`, mandatory `python/main.py`, optional `python/requirements.txt`, and optional `sketch/sketch.ino` plus `sketch/sketch.yaml`.
- The official App Bricks Python source currently bases its runtime on Python 3.13 slim and publishes its application containers for Linux ARM64. App CLI documentation identifies `app-bricks/python-apps-base` as the runner image. CueLoop records the date-bounded package audit separately; the actual board image still must identify itself at run time.
- The official `arduino-app-cli` is designed to run on UNO Q and assumes its board user, groups, system directories, and services. It is not a valid hardware-free App Lab runner for this generic Ubuntu build machine; final App import/run validation remains a declared UNO Q gate.
- Optional Bricks run on Linux alongside the Python app.
- Linux and MCU communicate through Arduino Bridge RPC. Supported patterns include Python `Bridge.call()`/`Bridge.notify()` and MCU `Bridge.provide()`/`Bridge.provide_safe()` after `Bridge.begin()`.
- Arduino documents the advanced router socket as `/var/run/arduino-router.sock`; CueLoop uses the supported App Lab helper instead of binding directly for V1.

Primary sources:

- [UNO Q product documentation](https://docs.arduino.cc/hardware/uno-q)
- [Arduino App Lab documentation](https://docs.arduino.cc/software/app-lab/)
- [Official App specification](https://github.com/arduino/arduino-app-cli/blob/main/docs/app-specification.md)
- [Official App CLI user documentation](https://github.com/arduino/arduino-app-cli/blob/main/docs/user-documentation.md)
- [Official UNO Q user manual source](https://github.com/arduino/docs-content/blob/main/content/hardware/02.uno/boards/uno-q/tutorials/01.user-manual/content.md)
- [Official App Lab examples](https://github.com/arduino/app-bricks-examples)
- [Official App Bricks Python runtime source](https://github.com/arduino/app-bricks-py)

## XIAO microphone facts

Seeed's official microphone guide documents the Sense expansion board microphone as PDM input at 16 kHz mono/16-bit, with PDM clock on GPIO42 and data on GPIO41. For current Arduino-ESP32 3.x the documented API is `ESP_I2S.h`, `I2S.setPinsPdmRx(42, 41)`, and `I2S.begin(I2S_MODE_PDM_RX, 16000, I2S_DATA_BIT_WIDTH_16BIT, I2S_SLOT_MODE_MONO)`. This must still be compiled and verified on the received hardware.

Primary source: [Seeed XIAO ESP32S3 Sense microphone guide](https://wiki.seeedstudio.com/xiao_esp32s3_sense_mic/)

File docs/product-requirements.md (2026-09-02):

# Product requirements

## Shared user promise

CueLoop helps a person notice a user-selected acoustic event across an acoustically separated space without cloud microphones, default audio recording, or a continuously listening human. It is useful to people who are deaf or hard of hearing and also to headphone users, workers using hearing protection, caregivers, neurodivergent users, makers, and anyone moving between rooms.

The product is an awareness aid. It does not guarantee detection, is not safety-certified, and cannot replace smoke/CO alarms, machine guarding, supervision, or medical care.

## V1: CueLoop

### Primary demonstration

A detached CuePod sits behind a closed door and hears one controlled target event. The UNO Q in the other room receives live evidence, performs local inference, combines multiple windows, confirms the event, drives a physical cue through the STM32, and shows a large dashboard alert. A confusable/background sound is then suppressed or held for confirmation. The user acknowledges the alert. Diagnostics show loss and latency; the privacy indicator shows that no raw recording is retained.

### Functional requirements

| ID | Requirement | Acceptance evidence |
|---|---|---|
| V1-F01 | Capture 16 kHz mono audio from the XIAO Sense PDM microphone. | Target compile plus observed mic smoke test. |
| V1-F02 | Send versioned, sequence-numbered audio frames over local Wi-Fi and reconnect after receiver/network interruption. | Protocol tests, simulated recovery, physical recovery test. |
| V1-F03 | Bound all audio buffering and discard consumed audio by default. | Unit test and code review; memory observation on target. |
| V1-F04 | Normalize model windows and classify through a replaceable local model adapter. | Unit/integration tests and target inference benchmark. |
| V1-F05 | Combine temporal evidence with per-class threshold, confirmation, cooldown, priority, and mute policy. | Deterministic state-machine tests. |
| V1-F06 | Represent uncertain outcomes as `observing` or `confirming`, never an immediate definitive alert. | Engine/API tests and dashboard demo. |
| V1-F07 | Let the user acknowledge, dismiss, or mute; persist event metadata/feedback locally without raw audio. | API tests and database inspection. |
| V1-F08 | Show pod health, event, confidence, time, confirmation, priority, privacy, loss, jitter, and latency locally. | Accessible desktop and UNO Q browser review. |
| V1-F09 | Send compact cue commands to the STM32; STM32 owns physical timing and acknowledgement input. | Bridge integration plus physical cue test. |
| V1-F10 | Provide test-tone, synthetic, WAV replay, loss/jitter/latency, and restart paths without hardware. | One-command demo and automated tests. |

### Quality targets

Targets are goals, not results:

- Median end-to-end alert latency: at most 2.5 seconds for confirmed events; p95 at most 4 seconds.
- Packet loss: demonstration remains understandable at 5% random loss; diagnostics remain accurate at 20%.
- False alerts: fewer than 1 per hour in the defined quiet/background test mix.
- Selected-class precision: at least 0.80; selected-class recall: at least 0.75 on the documented evaluation set.
- Dashboard: WCAG-oriented color contrast, keyboard-operable controls, non-color-only cue language, primary alert legible in a 1080p competition video.
- Startup/recovery: services recover without unbounded files or manual database repair.

### Initial vocabulary

`door_knock`, `alarm_beep`, `dog_bark`, and `attention_call`; `background` and `unknown` are suppression outcomes. Safety-alarm sounds may be evaluated as acoustic patterns, but the UI always retains the awareness-aid limitation.

## V2: CueLoop Bridge

CueLoop Bridge is not V1 in a prettier box. It evolves the shared acoustic/uncertainty core into a manufacturable portable system for multi-space creative and technical work.

### V2-specific requirements

- Dockable, separately placeable CuePod with protected microphone labyrinth, USB access, charging/power-state affordance, battery service strategy, and repeatable orientation.
- Portable receiver with a purposeful belt/bag clip, desk stand, lanyard points, tactile controls, haptic motor, high-visibility cue, and dock/transport relationship.
- Compact, carry-on-safe construction with no loose exposed LiPo, sharp tools, high-power laser, prohibited radio, or hazardous material.
- Multi-context modes for printer/CNC/test-rig completion, door/collaborator attention, and travel/conference awareness.
- Multi-pod identity and location cues, while preserving local-only processing and raw-audio deletion.
- Fusion master assembly, named parameters, electronics clearances, acoustic path, fastening/service plan, PCBWay-ready DFM, and potential carrier PCB.
- A credible path to roughly 750 manufactured units: assembly time, fastener count, molded/printed alternatives, test points, labeling, firmware provisioning, and end-of-line test.
- New Autodesk-user testing, interactions, CAD, manufacturing work, and submission story tracked separately from V1.

## Non-goals for the September V1

- Certification, guaranteed emergency detection, speech transcription, speaker identification, cloud accounts, remote internet monitoring, long-term raw audio recording, multi-pod production management, or a custom PCB.
- Audio compression unless benchmarks show raw PCM fails the demonstration requirements.
- More event labels solely to increase a feature count.

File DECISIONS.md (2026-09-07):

# Engineering decisions

| ID | Date | Decision | Rationale | Revisit trigger |
|---|---|---|---|---|
| D-001 | 2026-09-01 | Name V1 **CueLoop** and Autodesk V2 **CueLoop Bridge**. | “Bridge” communicates detachable multi-space utility beyond studios while preserving the technical lineage. | Trademark/confusion check or application feedback. |
| D-002 | 2026-09-01 | Target Best Social Impact for V1; treat Best in Show as upside. | The private, accessible awareness use case maps directly to the official category while the uncertainty pipeline supports broad usefulness. | Official category/rules change. |
| D-003 | 2026-09-01 | Start with 16 kHz, mono, signed 16-bit PCM over UDP on a trusted local network. | It is simple, inspectable, about 256 kbit/s before overhead, and sufficient for the target demonstration. | Measured loss, latency, runtime, or network contention is unacceptable. |
| D-004 | 2026-09-01 | Version packets, include pod/sequence/sample-clock metadata and CRC32, and keep payload at 20 ms (320 samples/640 bytes). | Packets fit comfortably below common MTUs, make loss visible, and align with streaming audio cadence. | Hardware profiling shows a different frame size is materially better. |
| D-005 | 2026-09-01 | Keep raw audio memory-only and bounded; persist only event metadata and explicit user feedback. | This makes the privacy promise technically enforceable and limits impact of device compromise. | A user explicitly enables a documented diagnostic capture session. |
| D-006 | 2026-09-01 | Use a model adapter: deterministic simulation classifier for tests and optional TFLite/YAMNet-compatible inference for real evaluation. | The event engine remains fully testable before weights/hardware while simulated outputs cannot be confused with measured model quality. | A better-supported official App Lab audio model is benchmarked. |
| D-007 | 2026-09-01 | UNO Q Linux owns networking, inference, policy, API, and event history; STM32 owns button handling and physical cue timing. | It makes meaningful use of both processors and keeps timing/recovery deterministic. | Official APIs or target profiling contradict the split. |
| D-008 | 2026-09-01 | V1 supports a focused initial vocabulary: door knock, alarm/beep, dog bark, and attention call, plus unknown/background. | Four interpretable classes permit honest per-class testing and a clear demo. | Evaluation shows a class is unreliable or another is substantially stronger. |
| D-009 | 2026-09-01 | Treat CueLoop as an awareness aid, never a certified alarm, security, or medical device. | Avoids unsafe substitution and unsupported regulatory claims. | Never relax without formal certification work. |
| D-010 | 2026-09-01 | Use official App Lab folder structure and Bridge APIs; keep the core Python package runnable outside App Lab. | This supports official integration and fast desktop simulation with one code path. | App Lab packaging constraints require a thin adapter change. |
| D-011 | 2026-09-01 | Keep the simulator, service, API, dashboard server, and metadata store on the Python standard library. | The core demo works offline with no dependency install; target inference can remain an optional model adapter. | App Lab runtime profiling or required WebUI integration shows a material disadvantage. |
| D-012 | 2026-09-02 | Select checksum-pinned Google YAMNet classification LiteRT v1 as the first real-model baseline, with an explicit optional adapter and provenance-gated evaluation. | It is official, Apache-2.0, small, interpretable, and has direct AudioSet labels for the four V1 concepts; the fixed 0.975 s input matches the existing window pipeline. | Licensed held-out evaluation fails a class, UNO Q runtime is unsuitable, or the official App Lab audio Brick materially outperforms it on identical clips. |
| D-013 | 2026-09-02 | Use explicit receiver IP configuration and a rate-limited CRC heartbeat for V1 instead of discovery or bidirectional reliability. | It is deterministic, debuggable, and sufficient for one trusted-LAN demo while keeping audio delivery latency low; the heartbeat makes receiver loss visible without pretending UDP is reliable. | Physical setup friction or address churn makes a documented discovery method necessary. |
| D-014 | 2026-09-02 | Package the pinned model directly with the self-contained App Lab folder at export time and fail closed if it is missing or modified. | A physical app must never silently substitute synthetic inference, while Git should not carry a 4.1 MB downloaded binary whose authoritative source and checksum are already recorded. | App Lab provides a versioned official audio Brick/model with equal mapping control and measured superior target performance. |
| D-015 | 2026-09-02 | Make UNO Q onboard LED3/LED4 the complete V1 physical-output baseline; leave external button, haptic, buzzer, and Modulino parts optional and disabled. | The minimum build is already meaningful and compiled without assuming the unknown Arduino accessory packing list or unsafe direct actuator drive. | Inventory and measured accessibility testing identify a supported output that materially improves the demo without destabilizing it. |
| D-016 | 2026-09-02 | Produce two audited releases: a self-contained App Lab archive with the verified runtime model and an exact-commit source archive without model/audio/runtime data or the internal project brief. | Judges need both a deployable App and accessible reusable source, while a private development repository and ignored binary must not cause access or leakage failures. | The contest platform imposes a different archive/import structure or public repository policy. |
| D-017 | 2026-09-02 | Make root `HARDWARE_TESTS.md` the authoritative physical procedure and raw observation log; keep `HARDWARE_RESULTS.md` as the reviewed publication summary. | One canonical Windows/safety/test record prevents divergent checklists while preserving a concise claim boundary. | The physical operator needs a generated form/app that retains identical IDs and fields. |
| D-018 | 2026-09-02 | Report both production temporal policy and a one-window baseline, condition slices, and optional annotated audio-to-decision latency in evaluation schema v2. | The brief requires measured temporal benefit and condition effects; reporting both strategies on identical clips is more honest than asserting confirmation is better. | Event-stream datasets require multi-event matching/cooldown metrics beyond one interval per class/clip. |
| D-019 | 2026-09-02 | Begin the Autodesk final package as an evidence-gated product/manufacturing workspace now, without implementing speculative V2 hardware before inventory and measurements. | December scope must be concrete and differentiated, but optional power/haptic/carrier choices materially depend on received parts and physical evidence. | Hardware inventory, application selection, or organizer feedback closes those decision gates. |
| D-020 | 2026-09-02 | Make the native Autodesk Fusion API generator and its returned `.f3d` the authoritative mechanical model; use a separately implemented FreeCAD/OpenCascade assembly only for Ubuntu geometric validation. | The contest artifact must contain genuine editable Fusion sketches, parameters, components, features, and history, while an independent kernel can catch invalid solids, dimensional drift, and placement interference before Fusion Desktop is available. | A Fusion runtime incompatibility or visual/physical finding requires a reviewed source/parameter revision and regeneration, never substitution of the reference STEP. |
| D-021 | 2026-09-02 | Produce release firmware only through a clean-intermediate builder with fixed epoch and checkout-root path normalization, then verify it in a separate local clone. | ESP32 core compile-time strings and the image's embedded ELF digest otherwise vary with build time/path even when program behavior is unchanged; deterministic inputs make artifact hashes meaningful. | A platform/toolchain change makes the flags unsupported or introduces another documented nondeterministic field. |
| D-022 | 2026-09-02 | Pin and hash-audit the complete inference dependency set for Arduino's documented CPython 3.13/Linux ARM64 runner, while keeping actual App Lab import/loading/inference as a target gate. | A host-only package pin does not establish target architecture availability. Exact target wheels, metadata, hashes, and native ELF identity can be proven safely on Ubuntu; dynamic loader and board-image behavior cannot. | The received App Lab image reports a different Python/architecture/libc tuple, target loading fails, or Arduino changes its runner base. |
| D-023 | 2026-09-06 | Supersede D-003/D-013 transport details with two-byte length-framed PCM and ACK packets over persistent TCP 57321. | Physical App Lab 0.10.0 / app CLI 0.13.0 publishes declared ports as TCP-only; the original UDP listener remained reachable only inside its container. TCP uses the supported published-port path while preserving Protocol v1 packet CRCs, sequence metrics, bounded reconnect, and trusted-LAN limits. | App Lab adds an explicitly supported UDP mapping or physical TCP latency/reconnect evidence fails the V1 targets. |

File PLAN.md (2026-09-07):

# Master plan

This plan is deadline-driven. A task is complete only when its artifact exists, its claims are evidence-labeled, and proportionate verification has run.

## Critical path: September 1–7

1. **September 1 — foundations:** verify official requirements; create project controls, product requirements, architecture, privacy/safety policy, source log, decision log, and risk register.
2. **September 1–2 — Autodesk application:** finish polished responses, separate V2 story, starting BOM, system diagrams, feasibility/risk narrative, schedule, and Hackster opening copy.
3. **September 1–3 — native Fusion package:** complete the production-intent `adsk` generator, named parameter/component/output contracts, pod/receiver/clip/dock/electronics-envelope geometry, independent OpenCascade reference exports and interference validation, DFM/provenance records, original cover concept, and exact `.f3d` execution/evidence/return instructions. Only the Windows Fusion run and review remain external.
4. **September 3 — application freeze candidate:** adversarially review every required field and attachment. Leave only the user-controlled Hackster/Fusion submission actions.
5. **September 4–6 — buffer and evidence:** incorporate real inventory/dimensions if hardware arrives; otherwise improve CAD, code credibility, and render package without destabilizing the application.
6. **September 7 — user submission:** execute the short application checklist before 23:59 PDT.

## App Lab V1: September 1–13

1. Define and test the versioned length-framed TCP PCM protocol and typed event records.
2. Build a simulator with synthetic event signatures, WAV replay, jitter, latency, loss, and reconnect scenarios.
3. Implement a bounded receiver/jitter buffer, window normalization, model interface, temporal confirmation engine, priority/cooldown policy, local feedback log, and health metrics.
4. Implement a local REST/dashboard experience and one-command simulated demonstration.
5. Evaluate candidate lightweight audio models and commit scripts/provenance—not downloaded weights or audio.
6. Implement XIAO microphone/Wi-Fi firmware with sequence/timestamp packets, discovery/configuration, reconnect, battery telemetry capability, test tone, and diagnostic counters.
7. Implement UNO Q MCU cue ownership and compact Bridge RPC commands; package the Linux and sketch components as an official App Lab App.
8. Create BOMs, real reproducible schematics, wiring/power diagrams, assembly order, troubleshooting, and safe bring-up checklists.
9. Validate on hardware when available using root `HARDWARE_TESTS.md`; label every number by evidence tier and publish only reviewed summaries from `HARDWARE_RESULTS.md`.
10. Complete Hackster copy, build guide, source guide, privacy/limitations, demo storyboards, narration, shot list, on-screen text, and submission checklist.
11. Run an adversarial rubric review, verify a clean clone, archive a release candidate, and submit before the official deadline.

## Autodesk V2: protected development path

After the September application, preserve V1 stability while evolving CueLoop Bridge into a portable product: dockable CuePod, clip/stand/lanyard receiver, haptic/visual language, charging and battery architecture, acoustic path, serviceable DFM enclosure, Fusion Electronics design, optional carrier PCB, PCBWay process, multi-pod interactions, and Autodesk-workflow evaluation. Shared and V2-only work are tracked explicitly in `submissions/DIFFERENTIATION.md`; the evidence-gated execution/manufacturing/final-story workspace is under `submissions/autodesk_final/`.

## Completion gates

- **Digital gate:** all software, firmware, native Fusion CAD automation, independent reference geometry/exports, tests, docs, submission copy, and checklists that do not require hardware or Fusion Desktop are complete.
- **Hardware gate:** target builds, polarity/continuity, flash, microphone, network, cue, thermal, current, runtime, distance, door, noise, and recovery results are recorded.
- **Submission gate:** all official fields/assets are attached, public claims match evidence, links work without private-repository access where required, and the user performs the final account-controlled submission.

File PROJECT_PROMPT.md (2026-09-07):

You are the lead engineer, AI developer, embedded developer, product designer, test engineer, and competition-submission writer for CueLoop. Treat this as a long-running goal, not a one-turn consultation.

Create an active goal whose objective is:

“Design, implement, test, document, and package CueLoop as a highly competitive Arduino UNO Q project for the 2026 Invent the Future with Arduino UNO Q and App Lab competition, while creating a materially differentiated Autodesk University 2027 product application and development path based on the same technical foundation.”

Continue working until every task that can be completed digitally is complete. Do not stop after producing a plan or skeleton repository. Write the code, tests, documentation, diagrams, CAD automation, submission drafts, scripts, and user instructions. Make reasonable engineering decisions independently. Ask me questions only when a missing choice would materially change the product or when a physical action or observation is genuinely required.

## Dates and competitions

Current starting date is approximately September 1, 2026. Check the actual date when beginning.

Competition 1:

- Invent the Future with Arduino UNO Q and App Lab
- Final deadline: September 13, 2026 at 11:59 PM Pacific
- Target category: Best Social Impact, with Best in Show as secondary upside
- Judging emphasis:
  - Project documentation: 30
  - BOM: 20
  - Schematics: 15
  - Code and contribution: 15
  - Creativity: 20

Competition 2:

- Build the Autodesk University 2027 Product
- Hardware application deadline: September 7, 2026 at 11:59 PM Pacific
- Final project deadline: December 20, 2026 at 11:59 PM Pacific
- The September application requires a credible product concept, Hackster project beginning, preliminary Fusion design, starting BOM, cover image/render, and project story.
- The December product must be portable, wearable, attachable, clipped, or carried; useful beyond Autodesk University; and suitable for Autodesk customers.
- Judging emphasis:
  - Creativity: 30
  - Documentation: 20
  - BOM: 20
  - Schematics: 10
  - Fusion: 10
  - Code: 10

Before relying on these details, verify the latest official competition rules and official Arduino UNO Q/App Lab documentation. Use official primary sources. If current official information conflicts with this prompt, follow the official information and document the discrepancy.

## Confirmed hardware

The following hardware has been ordered:

- Arduino UNO Q 4 GB / 32 GB, SKU ABX00173
- The accompanying Arduino order and its Modulino/Qwiic accessories; inventory the exact modules when the packing list or hardware is available
- Seeed Studio XIAO ESP32S3 Sense, manufacturer part 113991115
- Adafruit protected 3.7 V 500 mAh LiPo battery, product 1578
- Adafruit JST-PH female pigtail, product 261
- YIHUA 926 III temperature-controlled soldering-station kit
- AstroAI AM33D multimeter
- Appropriate UNO Q power, USB-C connectivity, and Qwiic infrastructure from the Arduino order

Do not assume optional modules are essential. Build the minimum reliable product around the UNO Q, XIAO Sense, and available human-output hardware. Provide graceful software fallbacks when hardware is still in transit.

Never instruct me to solder with the battery connected. Require polarity and continuity checks before first battery connection. Never solder directly to a LiPo cell.

## Product thesis

CueLoop is a private, local-first acoustic event bridge.

A detachable, battery-powered wireless microphone pod can be placed in another room, workspace, doorway, machine area, studio, or other acoustically separated location. The pod streams or transmits acoustic evidence to the UNO Q. Edge AI recognizes important environmental events and converts them into discreet, understandable visual, audible, and/or haptic cues.

Examples include:

- Door knocks
- Timers and appliance beeps
- Smoke or safety alarms
- Running water
- Glass breaking
- A crying baby
- A dog barking
- Someone calling for attention
- A machine completing a cycle
- Workshop or fabrication alerts

The initial social-impact use case includes people who are deaf or hard of hearing, but the product must not be framed as exclusively for that population. Additional users include:

- People wearing headphones
- Workers wearing hearing protection
- Caregivers
- Neurodivergent users who want controlled rather than startling alerts
- People moving between rooms
- Makers monitoring a machine or process from another space
- People who want awareness without cloud microphones or constant audio recording

The central promise is:

“Know what needs your attention without continuously listening, recording, or remaining in the same room.”

Avoid claiming CueLoop is a safety-certified alarm or medical device.

## What makes this more than a sound classifier

A winning project cannot merely run an audio model and display a label.

Develop a confidence-aware event pipeline:

1. The remote pod observes audio.
2. The UNO Q estimates the likely event and confidence.
3. Temporal evidence is combined across multiple windows.
4. Ambiguous events trigger a deliberate confirmation window or adjusted measurement instead of an immediate false alert.
5. The system reports the event only when the evidence and user-configured importance justify it.
6. The user can confirm, dismiss, or mute the cue.
7. Feedback is stored locally as evaluation data and, if feasible, used for lightweight personalization.
8. Raw audio is discarded by default after inference.

This “uncertainty-aware acoustic bridge” is the technical and creative core.

## Two related but distinct products

Do not submit one identical project twice.

### App Lab V1: CueLoop

CueLoop V1 is a working, highly reproducible social-impact prototype completed by September 13.

It should demonstrate:

- A detachable XIAO Sense microphone
- Wireless room-to-room audio or acoustic-feature transmission
- UNO Q edge-AI event recognition
- Confidence and temporal confirmation
- Local-first privacy
- A clear App Lab workflow
- Meaningful use of both the UNO Q Linux/Qualcomm side and STM32 MCU side
- At least one physical output such as LEDs, haptics, buzzer, or another available Modulino
- A polished local dashboard
- Complete BOM, schematics, code, build instructions, and quantitative testing

Target one excellent, repeatable demonstration rather than many unreliable features.

### Autodesk V2: CueLoop Studio / CueLoop Bridge

Develop a materially evolved portable product for Autodesk users and multi-space work.

Possible use cases include:

- A designer wearing hearing protection while a printer, CNC machine, laser cutter, test rig, or curing process runs elsewhere
- A creator working in a studio while monitoring a door, timer, machine, or collaborator
- A portable conference or hotel-room awareness accessory
- A clip-on receiver paired with detachable acoustic pods
- A privacy-preserving alternative to placing smart speakers throughout a space

V2 must add product depth, not merely a prettier enclosure:

- A detachable or dockable CuePod
- A portable receiver or main unit
- Purposeful clip, stand, lanyard, magnetic dock, or attachment system
- Designed microphone port and acoustic path
- Haptic and visual cue language
- Serviceable enclosure
- Battery and charging strategy
- Improved controls and ergonomics
- Manufacturable Fusion design
- PCBWay-appropriate enclosure
- Potential custom PCB or carrier
- Clear Autodesk-workflow relevance
- Materially expanded reliability, portability, and interaction design

Maintain separate Hackster submission content and a clear shared-work/differentiation record.

## Required repository

Create and maintain a clean repository resembling:

- `README.md`
- `LICENSE`
- `CONTRIBUTING.md`
- `CHANGELOG.md`
- `docs/`
  - product requirements
  - architecture
  - privacy model
  - safety
  - build instructions
  - testing
  - troubleshooting
  - photo shot list
  - demo instructions
- `firmware/`
  - `xiao_cuepod/`
  - `uno_q_mcu/`
- `linux/`
  - audio receiver
  - inference service
  - event engine
  - API
  - local dashboard
- `app_lab/`
- `models/`
  - model-selection notes
  - class mappings
  - preprocessing
  - conversion scripts
  - evaluation tools
- `shared/`
  - protocol definitions
  - schemas
  - constants
- `simulator/`
  - simulated wireless microphone
  - prerecorded-event replay
  - packet-loss and latency injection
- `tests/`
  - unit
  - integration
  - protocol
  - recorded-audio evaluation
- `hardware/`
  - BOM
  - wiring tables
  - pin assignments
  - schematics
  - power calculations
- `cad/`
  - Fusion scripts
  - dimension parameters
  - generated reference exports
  - assembly instructions
- `submissions/`
  - `app_lab/`
  - `autodesk_application/`
  - `autodesk_final/`
- `experiments/`
- `benchmarks/`
- `scripts/`
- `assets/`
- `user_checklists/`

Use a structure appropriate to the actual tools and languages after examining the official UNO Q development workflow.

## Technical architecture to validate and implement

Treat this as a starting architecture, not unquestionable truth. Validate each assumption against official documentation and actual benchmarks.

### CuePod: XIAO ESP32S3 Sense

Implement firmware that:

- Captures the onboard digital microphone
- Begins with 16 kHz mono audio suitable for event classification
- Uses Wi-Fi for V1 unless testing proves another transport superior
- Sends sequence-numbered, timestamped packets
- Reports battery state when supported
- Supports a simple pairing/configuration mechanism
- Detects receiver loss and reconnects cleanly
- Exposes diagnostic counters
- Avoids persistent raw-audio storage
- Includes a USB-powered development mode
- Includes a simulated or test-tone mode
- Keeps credentials out of source control
- Documents exactly how to flash and configure the board

Use persistent length-framed TCP for raw PCM and ACK traffic because Arduino App Lab publishes declared ports as TCP. Add compression only if measurements justify the complexity.

Design and document:

- Packet format
- Discovery or receiver configuration
- Buffering
- Lost-packet behavior
- Clock/timestamp handling
- Reconnection
- Security and privacy limitations
- Expected bandwidth
- Expected battery runtime

### UNO Q Linux side

Implement services that:

- Receive the CuePod stream
- Maintain a bounded jitter/ring buffer
- Produce correctly normalized model windows
- Run a lightweight audio-event model locally
- Map broad model outputs into a small, understandable CueLoop vocabulary
- Combine evidence temporally
- Apply per-class thresholds, cooldowns, and user priorities
- Perform confirmation passes for uncertain events
- Generate structured event records
- Avoid saving raw audio by default
- Expose health, latency, packet-loss, and model-performance information
- Serve a polished local web interface
- Run through the official App Lab workflow where practical
- Include reproducible environment and dependency setup
- Recover after component restart

Investigate suitable pretrained models, beginning with lightweight TFLite audio-event models such as YAMNet or a better supported equivalent. Benchmark before committing. Do not claim the model works well merely because inference runs.

### UNO Q STM32 side

Use the MCU for responsibilities that genuinely benefit from deterministic hardware behavior, such as:

- Button/knob input
- Haptic patterns
- LED patterns
- Buzzer timing
- Watchdog/health indication
- Fast acknowledgement input
- Sensor sampling if an available Modulino adds meaningful value

Use the supported UNO Q Bridge/RPC mechanism. The Linux side should send compact event commands; the MCU should own reliable physical cue timing.

If the actual UNO Q/App Lab architecture differs, adapt cleanly and explain why.

### Local interface

Create a visually polished, accessible dashboard that shows:

- Connection state
- Current monitored location/pod
- Recognized event
- Confidence
- Time detected
- Confirmation state
- User priority
- Mute/acknowledge controls
- Recent event history without raw audio
- Packet loss and latency in a diagnostics view
- Privacy state
- Simple event-class configuration

Design for a competition video: important information must be legible immediately.

## Simulator-first requirement

Do not wait idly for hardware.

Before hardware arrives, implement:

- A simulated CuePod sender
- WAV-file replay
- Artificial packet loss
- Artificial jitter and latency
- Receiver reconnection tests
- Event-engine unit tests
- Dashboard mock data
- Model evaluation scripts
- A one-command local demonstration

Keep hardware-specific code behind clear interfaces so simulated and physical sources use the same processing pipeline.

Never present simulated results as physical validation.

## Model and data evaluation

Create an honest evaluation framework.

Use legally reusable or self-recorded test audio. Record provenance and licensing. Avoid committing copyrighted or sensitive recordings.

Measure:

- Per-class precision and recall
- Confusion matrix
- False alerts per hour
- Missed-event rate
- End-to-end latency
- Inference latency
- Packet-loss tolerance
- Effect of distance and closed doors
- Effect of background speech, television, music, and fans
- Confidence calibration
- Benefit of temporal confirmation versus a single-window classifier

Select a limited set of classes that can be demonstrated reliably. It is better to support four classes convincingly than twenty poorly.

Mark every number as one of:

- Simulated
- Benchmarked on development computer
- Measured on UNO Q
- Measured with physical CuePod
- Estimated

Never fabricate test results.

## Schematics and BOM

Create:

- Exact BOM with manufacturer numbers, quantities, purpose, source, and price
- Minimum V1 BOM
- Optional V1 parts
- V2 development BOM
- Wiring tables
- Power-path diagram
- Battery connection diagram
- Wireless/system block diagram
- MCU/Linux responsibility diagram
- Network protocol diagram
- A real schematic using an appropriate reproducible format where possible
- Human-readable SVG/PNG exports
- Pin assignments
- Assembly order
- Polarity checks
- Multimeter procedures
- Safe first-power checklist

Do not confuse Qwiic cables with the battery pigtail. The CuePod does not need a Qwiic cable unless a later sensor is deliberately added.

## Fusion and Autodesk work

Create a preliminary but credible Fusion 360 design workflow before the September 7 application deadline.

Because direct Fusion manipulation may require user interaction, do as much as possible through generated files and automation:

- Write a Fusion 360 Python script or add-in that generates the preliminary parametric parts
- Clearly document how I run the script inside Fusion
- Define all critical dimensions in one parameter section
- Create at least:
  - CuePod enclosure
  - Microphone acoustic opening
  - USB access
  - Battery cavity
  - Internal board supports
  - Lid/fastening strategy
  - Clip/dock/stand concept
  - Main receiver enclosure concept
  - Basic assembly
- Use realistic wall thicknesses, clearances, fillets, draft/printing constraints, fastener sizes, and service access
- Generate any reference renders or diagrams possible outside Fusion
- Give me exact instructions for saving the resulting design as `.f3d`
- Produce an application-ready cover render or a detailed render-generation workflow
- Maintain a dimensional validation checklist against the physical parts when they arrive

For December, evolve the CAD toward a manufacturable PCBWay enclosure and document DFM decisions.

## Competition deliverables

### Autodesk application package — first priority

Complete as early as possible:

- Final product name recommendation
- One-sentence pitch
- Short elevator pitch
- Long project story
- Problem and user definition
- Product differentiation
- Why UNO Q is necessary
- Why Fusion is necessary
- Why Autodesk users would carry it
- Starting BOM
- System architecture
- Preliminary CAD
- Cover image/render
- Hackster project opening
- Application responses
- Credible execution timeline
- Risk management
- Explicit explanation of how V2 differs from the App Lab prototype

Write polished, submission-ready copy—not bullet fragments.

### App Lab package

Create:

- Competition-ready title and subtitle
- Cover-image plan
- Complete Hackster project article
- Problem statement
- User stories
- Architecture explanation
- AI explanation
- App Lab explanation
- Linux/MCU split explanation
- Full BOM
- Complete schematics
- Reproducible build instructions
- Setup instructions
- Usage instructions
- Troubleshooting
- Privacy explanation
- Limitations
- Test results
- Source-code guide
- Contribution/reuse value
- Photo shot list
- Three-minute demo storyboard
- Short and long narration scripts
- On-screen text plan
- Final submission checklist

Optimize explicitly for the published judging rubric.

### Autodesk final package

Begin the structure now but do not let December work endanger the September deadlines. Track:

- V1 shared work
- V2-specific work
- New hardware
- New interactions
- New CAD
- New manufacturing work
- New testing
- New Autodesk-user workflow
- Eligibility differentiation

## Demo design

Design a demonstration that is understandable without explanation:

1. Place the CuePod in another room or behind a closed door.
2. Show the UNO Q receiver and dashboard in the primary room.
3. Trigger a selected sound event.
4. Show wireless reception, edge inference, confirmation, and a physical cue.
5. Show the event label and confidence.
6. Demonstrate acknowledgement or mute.
7. Trigger a confusing/background sound and show that the system avoids or delays a false alert.
8. Show that processing remains local and no raw recording is retained.
9. Show diagnostic latency and packet-loss measurements.

Create a fallback demo using recorded WAV files, but the final competition video should prioritize a real detached microphone.

## Milestones and ordering

Work in this order unless official requirements force a change:

1. Verify official rules and technical documentation.
2. Create the repository, goal, decision log, risk register, and master plan.
3. Draft the Autodesk application and product requirements.
4. Generate preliminary Fusion automation and cover-render assets.
5. Build the simulator and common protocol.
6. Implement the UNO Q receiver, event engine, API, and dashboard.
7. Implement model evaluation and select reliable event classes.
8. Implement XIAO firmware.
9. Implement UNO Q MCU physical cues and Bridge/RPC integration.
10. Integrate through App Lab.
11. Execute hardware bring-up using exact user checklists.
12. Measure performance and replace simulated results with physical results.
13. Finish App Lab documentation, schematics, BOM, and video package.
14. Perform a rubric-based adversarial review.
15. Package and archive the submission.
16. Continue the Autodesk V2 development plan without conflating the two entries.

## Working behavior

- Begin immediately; do not ask me to approve the plan.
- Maintain `STATUS.md`, `PLAN.md`, `DECISIONS.md`, `RISKS.md`, and `HARDWARE_RESULTS.md`.
- Provide concise progress updates during long work.
- Use version control carefully and make logical commits when appropriate.
- Preserve user changes.
- Run tests after meaningful changes.
- Prefer primary documentation and reproducible dependencies.
- Do not leave large placeholder sections when implementation is possible.
- Do not claim hardware behavior that has not been observed.
- Do not silently abandon a difficult component; investigate alternatives and document the decision.
- When blocked on hardware, continue all unrelated work.
- When my physical input is required, give me one short numbered checklist with expected observations and a precise place to record the results.
- Keep secrets and Wi-Fi credentials out of the repository.
- Avoid unnecessary cloud dependencies.
- Avoid adding hardware simply because it is available.
- Keep V1 small enough to finish reliably.
- Treat documentation, schematics, BOM, and the demo as first-class engineering outputs.

## Definition of done

Do not mark the long-running goal complete merely because a prototype skeleton exists.

The digitally complete project should contain:

- Buildable XIAO firmware
- Buildable UNO Q MCU code
- Runnable UNO Q Linux services
- App Lab integration
- Functional simulator
- Automated tests
- Model-selection and evaluation tools
- Local dashboard
- Protocol documentation
- Complete BOM
- Wiring and schematics
- Safe hardware bring-up instructions
- Fusion automation and preliminary product design
- Autodesk application copy
- App Lab Hackster submission copy
- Video scripts and shot lists
- Quantitative test framework
- Clear placeholders only for measurements or photos that require physical hardware
- A prioritized list of remaining user actions
- A rubric-by-rubric final review

At the start, report the verified deadlines, the first concrete files you will create, and any official-rule discrepancy. Then begin creating the project immediately.

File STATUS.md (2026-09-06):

# Project status

**Updated:** 2026-09-05 EDT
**Goal:** active
**Phase:** Autodesk application packaging; physical and account-controlled handoff

## Deadline clock

| Deliverable | Official deadline | Eastern equivalent | Status |
|---|---:|---:|---|
| Autodesk hardware application | 2026-09-07 23:59 PDT | 2026-09-08 02:59 EDT | Submission kit in progress; highest priority |
| App Lab final submission | 2026-09-13 23:59 PDT | 2026-09-14 02:59 EDT | In progress |
| Autodesk final submission | 2026-12-20 23:59 PST | 2026-12-21 02:59 EST | Structure started; protected from V1 schedule |

## Completed digitally

- Read the complete authoritative project brief and created the required active goal.
- Created and pushed the repository safety baseline before configuration or generated artifacts.
- Verified deadlines, rubrics, entry requirements, UNO Q architecture, App Lab structure, and Bridge RPC pattern from primary sources.
- Identified and documented the Autodesk official-rules template-placeholder defect.
- Fixed the product split: CueLoop V1 and materially evolved CueLoop Bridge V2.
- Wrote the Autodesk application responses, Hackster opening story, starting BOM, differentiation ledger, and submission checklist.
- Created the production-intent native Autodesk Fusion generator, 125-value parameter source, component/output contract, PCBWay DFM notes, provenance boundary, and exact Windows execution/evidence/return runbook for the CuePod/receiver/dock/clip assembly.
- Generated the independent editable FreeCAD/OpenCascade reference assembly and six manufacturing part sets on Ubuntu; 12 solids are valid and positive-volume, the assembly STEP reopens as 12 solids, all 12 forbidden placement intersections have zero overlap, and 17 exported files verify against SHA-256.
- Ran the reviewed native generator in Windows Fusion 2705.1.11, inspected the hierarchy, timeline, parameters, sections, measurements, manufacturing parts, hardware envelopes, and interference results, then reopened the genuine `.f3d` cleanly.
- Returned and verified the complete Fusion export, final screenshot/render sets, run record, manifests, and SHA-256 archives on Ubuntu; C-101 through C-109 are recorded as passed for the digital scope.
- Generated and provenance-labeled an original Autodesk cover concept; it is explicitly not physical evidence.
- Implemented and documented the 684-byte CueLoop Protocol v1 with strict CRC/length/flag validation and matching C++ constants.
- Implemented the simulated CuePod, WAV replay, loss/jitter/latency/reorder/restart injection, bounded receiver/windowing, simulation classifier, temporal confirmation engine, metadata-only SQLite store, local API, and accessible dashboard.
- Added a one-command local demo and broad protocol, buffering, model, engine, privacy, pipeline, API, and simulator coverage.
- Verified Arduino CLI 1.5.1, ESP32 core 3.3.11, UNO Q Zephyr core 0.90.0, and both target FQBNs.
- Selected and checksum-pinned the official YAMNet LiteRT v1 baseline; added an optional validated adapter, exact AudioSet class mapping, safe fetcher, locked inference dependencies, and provenance-gated evaluation tooling.
- Measured a clearly bounded development-computer/synthetic-workload inference baseline: 100 runs, 1.834 ms mean, 1.919 ms p95, 1.997 ms maximum. No accuracy or target-hardware claim is attached.
- Implemented the XIAO CuePod PDM/Wi-Fi firmware with NVS serial configuration, strict Protocol v1 packets, receiver heartbeats, bounded reconnect, test tone, and diagnostics.
- Implemented the UNO Q STM32 cue controller with validated Bridge RPC inputs, deterministic onboard RGB patterns, heartbeat health, optional acknowledgement button/actuators, and restart-safe Linux resynchronization.
- Added the official self-contained App Lab folder, checksum-verified sync tool, fail-closed YAMNet startup, LAN dashboard/receiver, Bridge adapter, metadata persistence, pinned dependencies, and package drift tests.
- Compiled XIAO firmware at 26% flash/14% RAM and both the canonical and isolated App Lab UNO Q sketches at 11% flash/12% RAM. These are build-machine results, not physical validation.
- Created the complete minimum/optional/V2 BOM split, machine-readable connectivity netlist, accessible SVG schematic, wiring/pin tables, power/bandwidth/runtime analysis, and battery-safe assembly procedure.
- Added Windows UNO Q App Lab/XIAO flashing instructions and predeclared physical test gates for transport, microphone, model quality, latency, recovery, battery, thermal, mechanical, accessibility, and video evidence.
- Added integer RMS/peak/clipping diagnostics to CuePod firmware and recompiled it at 26% flash/14% RAM.
- Added a deterministic, secret-resistant App Lab release packager that records the exact Git commit, refuses dirty packaging inputs, and emits a SHA-256 sidecar. Release archives are ignored and regenerated from the final committed checkpoint so status text cannot make their identity stale.
- Completed the App Lab title/metadata, full Hackster article, source guide, troubleshooting, three-minute/short video scripts, photo list, evidence table, media attribution, final checklist, and adversarial 30/20/15/15/20 rubric audit.
- Added a deterministic committed-tree source-release packager with a per-file manifest, exact commit identity, excluded internal brief, secret/audio/model/database guards, and SHA-256 sidecar.
- Added dependency-free Fusion/reference output validation for critical dimensions, positive walls/floors/webs, vertical/electronics/dock clearances, body/component/timeline/parameter minima, exact reference bounds, provenance, source snapshots, expected export structure, and hashes.
- Added one deadline-ordered operator sheet covering the Autodesk application, hardware bring-up, measurement/media, and App Lab submission.
- Consolidated all Windows flashing, safety, physical validation, expected observations, and append-only execution records in root `HARDWARE_TESTS.md`, while keeping `HARDWARE_RESULTS.md` as the reviewed publication boundary.
- Extended real-audio evaluation with per-class confusion matrices/support, environment/distance/door/background slices, interval-based audio-to-decision latency, and temporal-versus-single-window comparisons.
- Added and ran a 60-trial simulated transport benchmark across clean, 5% loss/moderate jitter, and 20% loss/severe jitter profiles; its results remain explicitly software-only.
- Added the predeclared experiment registry and complete Autodesk December workspace for V2 hardware, interaction, CAD, manufacturing, evidence, article, and submission planning.
- Added a requirement-by-requirement completion audit and automated checks for the authoritative hardware record, experiment contract, and Autodesk V2 structure.
- Added a clean-intermediate firmware builder with fixed epoch and checkout-root path normalization; independently reproduced the XIAO images across two local clones and retained byte-identical canonical/App-profile UNO Q containers.
- Added a release-grade fresh-checkout verifier covering the pinned model, tests, Python 3.11 static analysis, all firmware/profile builds, clean manifests, and both archives without mutating tracked source.
- Audited Arduino's documented Python 3.13/Linux ARM64 runner distribution tuple: the complete eight-wheel inference set is exact-version/SHA-256 locked, archive-checked, and the 16 LiteRT native objects verify as AArch64. The App logs target Python/machine/libc/package identity; actual App Lab loading/inference remains unobserved.
- Expanded the automated suite to 67 passing tests and retained zero Pyright errors.

## In progress

- Assemble the Autodesk hardware-application kit from the verified Fusion output, final render/evidence archives, application copy, starting BOM, and architecture material; entrant biography, public Hackster URL, account preview, and submission confirmation remain user-controlled.
- Hardware-dependent, media-capture, identity/account, logged-out publication, and final submission actions are listed in `user_checklists/NEXT_ACTIONS.md`.

## Not yet claimed

- No licensed real-audio accuracy, UNO Q inference, end-to-end, physical packet-loss/latency, distance, closed-door, or battery measurement has been made.
- No physical board, battery, microphone, physical output, or App Lab run has been observed. The native Fusion `.f3d` is digitally validated but has not been physically fit-tested.
- No simulated result may be described as physical validation.

## Next checkpoint

The Autodesk application kit is generated and reviewed, the entrant biography and public Hackster project URL are supplied, and the account-controlled application is previewed and submitted. Hardware inventory and bring-up follow as separate evidence gates.

## External gates

Hardware inventory, measurements, assembly, flash verification, wireless testing, physical cue verification, enclosure fit, photography, and final real-device video require user-accessible hardware. Entrant biography, Hackster project creation, logged-out review, and final submission require the user's account. The Windows Fusion digital gate is complete. Remaining physical methods, safe stops, expected observations, and result blocks are recorded in `HARDWARE_TESTS.md`.

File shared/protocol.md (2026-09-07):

# CueLoop Protocol v1

CueLoop V1 uses one length-framed packet per 20 ms of 16 kHz mono signed 16-bit PCM over a persistent TCP connection. At 320 samples/frame the PCM payload is 640 bytes, the CueLoop packet is 684 bytes, and the two-byte stream prefix makes each TCP application frame 686 bytes. The stream consumes approximately 274.4 kbit/s before TCP/IP/link overhead.

V1 is intended only for a trusted private LAN. TCP supplies ordered reliable bytes but no application identity or confidentiality. CRCs detect accidental corruption; they do not provide authentication or integrity against an attacker. Never expose TCP port 57321 to the internet or use the prototype on public Wi-Fi.

## Stream framing

Every CueLoop packet is prefixed by a two-byte unsigned big-endian payload length. The length excludes the prefix and must be from 1 through 1324 bytes. A normal audio frame has prefix value 684; a receiver acknowledgement has prefix value 24. Invalid lengths terminate the connection. The next connection begins at a new frame boundary.

## Header

All multi-byte header integers are unsigned network byte order unless noted. PCM payload samples are signed little-endian int16.

| Offset | Size | Field | Meaning |
|---:|---:|---|---|
| 0 | 4 | magic | ASCII `CLP1` |
| 4 | 1 | version | `1` |
| 5 | 1 | message type | `1` = PCM16 audio |
| 6 | 2 | flags | Bit field below |
| 8 | 4 | pod ID | Locally assigned stable identifier; not a MAC address |
| 12 | 4 | sequence | Increments per frame modulo 2^32 |
| 16 | 8 | sample clock | Count of captured samples since pod stream start |
| 24 | 4 | capture ms | Pod uptime milliseconds, modulo 2^32 |
| 28 | 2 | sample rate | V1 requires 16000 |
| 30 | 2 | sample count | Nominal 320; protocol maximum 640 |
| 32 | 2 | battery mV | Zero when unavailable; valid only with flag |
| 34 | 1 | RSSI dBm | Signed int8; zero when unavailable |
| 35 | 1 | reserved | Must be zero |
| 36 | 4 | payload CRC32 | IEEE/zlib CRC32 over PCM bytes |
| 40 | 4 | header CRC32 | CRC32 over bytes 0–39 |
| 44 | N | PCM payload | `sample_count × 2` bytes |

Flags: bit 0 simulated source, bit 1 test tone, bit 2 USB powered, bit 3 battery value valid, bit 4 stream restart. Unknown bits cause a strict decoder rejection.

## Receiver heartbeat acknowledgement

Once per second, after validating an audio packet, the receiver returns a framed 24-byte acknowledgement on the same TCP connection. This lets the pod distinguish “Wi-Fi associated” from “CueLoop receiver reachable” without cloud state.

| Offset | Size | Field | Meaning |
|---:|---:|---|---|
| 0 | 4 | magic | ASCII `CLP1` |
| 4 | 1 | version | `1` |
| 5 | 1 | message type | `2` = receiver acknowledgement |
| 6 | 2 | flags | Must be zero |
| 8 | 4 | pod ID | Must match the active pod |
| 12 | 4 | last sequence | Most recent audio sequence observed for this reply |
| 16 | 4 | receiver uptime ms | Receiver-process uptime modulo 2^32 |
| 20 | 4 | CRC32 | IEEE/zlib CRC32 over bytes 0–19 |

The pod treats a valid matching acknowledgement as reachability evidence. After five seconds of enabled streaming without one it raises a diagnostic receiver timeout, closes the connection, reconnects with bounded backoff, and marks the next successfully delivered stream as restarted. The acknowledgement does not prove identity and is not a cryptographic authentication tag.

## Ordering, restart, and clock behavior

- TCP preserves byte order within a connection. The receiver still keys state by pod ID and releases frames through a bounded sequence buffer so simulator-injected faults, sender-side drops, and reconnect boundaries remain explicit.
- Duplicates and packets older than the current release point are discarded and counted.
- A sequence gap is held only to the configured bounded depth, then emitted as the expected number of zero samples and counted. TCP retransmission can increase latency, so the pod uses bounded connect/write timeouts instead of waiting indefinitely at the application layer.
- The first packet after a firmware/network stream reset sets `STREAM_RESTART`; the receiver clears pending reorder/audio state and accepts the new sequence/sample clock.
- `capture_ms` is pod uptime, not synchronized wall time. V1 estimates interarrival jitter and decision-pipeline delay; it does not claim one-way network latency without a measured clock-offset exchange.
- A sample-rate or nominal-frame-size change resets the stream and reports a diagnostic mismatch in V1.

## Privacy consequence

The payload exists only in pod/receiver memory and on the trusted LAN. It has no filename, storage command, or replay endpoint in the production receiver. Structured event metadata is a separate schema.

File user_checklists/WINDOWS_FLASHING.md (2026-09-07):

# Windows flashing and App Lab deployment

This quick checklist uses source and package artifacts already validated on the Ubuntu builder. It does not assume either board is attached to Ubuntu. Root `HARDWARE_TESTS.md` is authoritative and contains the complete steps, expected observations, and append-only execution record; copy only reviewed summaries to `HARDWARE_RESULTS.md`.

## Prepare transfer artifacts on Ubuntu

From the repository root:

```bash
python3 scripts/sync_app_lab.py --include-model
python3 scripts/package_app_lab.py --version 0.1.0
```

Transfer these to Windows through a trusted method:

- `packages/CueLoop-App-Lab-v0.1.0.zip`
- `packages/CueLoop-App-Lab-v0.1.0.zip.sha256`
- the repository working tree or at least `firmware/xiao_cuepod/`
- optionally `firmware/xiao_cuepod/build/artifacts/` for comparison/recovery

On Windows PowerShell, verify the archive before import:

```powershell
Get-FileHash .\CueLoop-App-Lab-v0.1.0.zip -Algorithm SHA256
Get-Content .\CueLoop-App-Lab-v0.1.0.zip.sha256
```

The two digests must match. Do not put Wi-Fi credentials into the transferred source/archive.

## A. UNO Q first connection and App Lab smoke test

1. Install the current Arduino App Lab for Windows 10/11 64-bit from Arduino's official software page.
2. Keep the CuePod LiPo detached. Connect UNO Q using the known Arduino-order USB-C data/power path. Follow the exact product manual for PC-hosted vs powered-hub/SBC mode; do not assume a charge-only cable is sufficient.
3. Launch App Lab. If Windows Defender asks about `mdns-discovery.exe`, allow private-network access only as appropriate for the trusted LAN. Network mode discovery uses mDNS/UDP 5353; guest, corporate/IoT isolation, VPNs, and firewalls may block it.
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

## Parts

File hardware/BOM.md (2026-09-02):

# Bill of materials

**Price check:** September 2, 2026. Manufacturer list prices exclude shipping and may vary by region, tax, promotion, and the actual invoice. EUR and USD are intentionally not combined using a transient exchange rate.

## Minimum working V1

This is the complete electrical BOM for the implemented minimum demo. It uses the UNO Q's onboard MCU RGB LEDs as the physical cue and dashboard controls for acknowledge/mute, so it does not require a Modulino, external buzzer, motor, button, Qwiic cable, or custom PCB.

| Ref | Qty | Item | Manufacturer / part | Purpose | Status | Reference price |
|---|---:|---|---|---|---|---:|
| U1 | 1 | Arduino UNO Q 4 GB RAM / 32 GB eMMC | Arduino ABX00173 | Linux inference/dashboard plus STM32 deterministic visual output | Ordered; markings pending | €82.90 incl. VAT, Arduino EU store |
| U2/MIC1 | 1 | XIAO ESP32S3 Sense, unsoldered | Seeed Studio 113991115 | ESP32-S3, Sense expansion PDM microphone, antenna, USB-C, Wi-Fi, battery management | Ordered; revision pending | US$13.90 |
| B1 | 1 | Protected LiPo, 3.7 V nominal, 500 mAh, JST-PH lead | Adafruit product 1578 | Detachable CuePod power; 29 × 36 × 4.75 mm, 10.5 g | Ordered; inspect before use | US$7.95 |
| J1 | 1 | JST-PH 2-pin female pigtail, 100 mm, 26 AWG | Adafruit product 261 | Replaceable battery interconnect soldered only at the board end, with battery detached | Ordered; mating/polarity pending | US$0.75 |
| PS1 | 1 | USB-C power/data path for UNO Q | Exact Arduino-order cable/supply or PD hub: packing list pending | Development power, App Lab deployment, board connectivity | Ordered infrastructure; exact MPN/price pending invoice | Inventory gate |
| C1 | 1 | USB-C data cable for XIAO | Existing known-good data cable | Initial flash, serial configuration, USB development power | Existing infrastructure | Not costed |
| LAN1 | 1 | Private 2.4 GHz Wi-Fi LAN | Existing router/access point | Local CuePod-to-UNO Q transport; no internet runtime dependency | Existing infrastructure | Not costed |

Core electronics subtotal: **€82.90 plus US$22.60**, before the already ordered/inventory-pending power path, tax differences, and shipping.

The Sense kit normally includes its antenna and microphone expansion board; inventory them as separate line items if the received packaging does. The camera is not used. Do not add headers simply because they are available.

## Mechanical completion items

The preliminary CAD produces a CuePod and receiver enclosure, but exact printable material, fasteners, and quantities cannot truthfully be frozen until the physical boards are measured and the models are sliced. Record the selected spool manufacturer/material/color, sliced grams, support grams, fastener MPN, and actual cost here before the competition's final BOM is published.

| Ref | Planned item | Current specification | Freeze gate |
|---|---|---|---|
| M1 | CuePod base/lid | 2.0 mm nominal wall, protected mic opening, USB access, battery restraint | Caliper validation and fit print |
| M2 | UNO Q receiver base/lid | UNO outline plus measured connector/cable envelope and visible LED path | Accessory inventory and fit print |
| F1 | Service fasteners | M2 strategy, 2.4 mm clearance and 5.5 mm bosses in CAD | Choose thread-forming screw or insert after print-process test |
| I1 | Battery insulation/restraint | Nonconductive, noncompressive, removable; no adhesive on damaged cell | Select after cell/pigtail placement test |

These are not hidden omissions: the electrical bench prototype remains complete without an enclosure, but battery operation is allowed only when the cell and leads are safely restrained away from sharp or conductive parts.

## Optional V1 additions—not required by firmware

| Ref | Item | Connection | Selection rule |
|---|---|---|---|
| S1 | Normally-open momentary acknowledgement button | UNO Q D4 to GND; `INPUT_PULLUP` | Use only after inventory identifies a rated, mountable part; dashboard acknowledgement is the fallback |
| H1 | Haptic motor plus transistor/driver, flyback/suppression as required | Disabled by default in `cue_controller_hardware.local.h` | Never drive a motor from a GPIO; select from measured voltage/current and driver datasheet |
| BZ1 | Active buzzer plus appropriate driver | Disabled by default | Select only if accessible cue testing justifies sound; keep level conservative |
| MOD1 | Arduino Modulino output | Qwiic/I2C only if deliberately supported in a later firmware change | Inventory first; a Qwiic cable is never a battery cable |

## Tools and development infrastructure—not product BOM

| Qty | Item | Identity | Use |
|---:|---|---|---|
| 1 | Temperature-controlled soldering station kit | YIHUA 926 III | Pigtail-to-board work with USB and battery disconnected |
| 1 | Digital multimeter | AstroAI AM33D | Voltage, polarity, continuity/resistance, optional guarded current test |
| 1 | Windows 10/11 64-bit laptop | User equipment | Arduino App Lab, flashing, serial terminal, browser |
| 1 | Ubuntu build machine | User equipment | Reproducible host tests and Arduino CLI builds |

## V2 CueLoop Bridge development BOM

V2 is intentionally not an identical contest resubmission. Its BOM is a gated product-development set, not a claim that unselected parts were built.

| Subsystem | Required V2 selection | Gate/evidence before freezing |
|---|---|---|
| Portable receiver power | USB-PD battery/charge/power-path sized for UNO Q load | Measure UNO Q app idle/peak/current and thermal behavior first |
| Haptic output | Coin/LRA actuator, protected driver, connector | Measure cue detectability, current, mounting noise, and skin-contact comfort |
| Visual output | Diffused high-visibility RGB/light pipe | Test daylight visibility without color-only semantics |
| Tactile controls | Acknowledge, mute, priority controls | Glove/eyes-free usability and debounce testing |
| Dock | Mechanical latch or qualified magnets/keeper | Retention, interference, carry-on and assembly-cycle tests |
| Interconnect | Fusion Electronics carrier PCB if justified | Only after prototype wiring and assembly-time study |
| Enclosure | PCBWay-compatible serviceable process/material | Fit, thermal, drop, clip, dock, draft and fastening validation |
| Fasteners | Production-intent screws/inserts | Torque, boss, repeated-service, and supplier availability tests |

## Source notes

- Arduino lists ABX00173 at €82.90 on the checked regional store page and specifies USB-C 5 V up to 3 A / VIN 7–24 V in current UNO Q documentation.
- Seeed lists 113991115 at US$13.90 and documents the integrated digital microphone, Wi-Fi, battery management, and 21 × 17.8 × 15 mm Sense envelope.
- Adafruit lists product 1578 at US$7.95 and product 261 at US$0.75. Product 1578 is protected but still requires correct CC/CV charging, inspection, and supervision.
- The actual order invoice—not a web price—wins when the final submission cost table is frozen.

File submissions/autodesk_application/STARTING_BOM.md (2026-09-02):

# CueLoop Bridge starting BOM

Prices are manufacturer list prices rechecked September 2, 2026 and may differ by region, tax, shipping, or the entrant's invoice. “TBD after inventory/test” is deliberate; optional output hardware is not treated as essential until the Arduino packing list and power tests are available.

## Confirmed core and application items

| Qty | Item | Manufacturer / part | Purpose | Status | Reference price |
|---:|---|---|---|---|---:|
| 1 | Arduino UNO Q 4 GB / 32 GB | Arduino ABX00173 | Linux edge AI, local UI, STM32 physical control | Ordered | €82.90, Arduino EU store |
| 1 | XIAO ESP32S3 Sense | Seeed Studio 113991115 | Detachable Wi-Fi PDM microphone pod | Ordered | US$13.90, Seeed list price |
| 1 | Protected 3.7 V 500 mAh LiPo | Adafruit 1578 | CuePod battery; 29 × 36 × 4.75 mm | Ordered | US$7.95 |
| 1 | JST-PH 2-pin female pigtail, 100 mm | Adafruit 261 | Replaceable battery interconnect only after polarity checks | Ordered | US$0.75 |
| 1 | Autodesk Fusion | Autodesk | Mechanical assembly, Electronics, drawings, DFM | Application software | Competition license / trial |
| 1 | PCBWay rapid prototyping allocation | PCBWay | V2 enclosure and possible carrier fabrication | Application resource | Up to US$300 for selected recipients |

## Confirmed development infrastructure

| Qty | Item | Manufacturer / part | Purpose | Product BOM? |
|---:|---|---|---|---|
| 1 | Temperature-controlled soldering station kit | YIHUA 926 III | Assembly; never used with LiPo connected | No; tool |
| 1 | Digital multimeter | AstroAI AM33D | Polarity, continuity, voltage, and current procedures | No; tool |
| 1 | UNO Q USB-C power/connectivity | Exact item from Arduino order pending inventory | Development power, flashing, SBC use | No; infrastructure |
| TBD | Arduino Modulino/Qwiic accessories | Exact packing list pending | Evaluate available human output; none assumed essential | Optional |

## V2 development candidates—not yet purchased or frozen

| Item | Selection gate | Reason |
|---|---|---|
| Low-profile haptic motor plus protected driver | Select after voltage/current and cue testing | Eyes-free portable alerts |
| Diffused RGB light/light-pipe source | Prefer confirmed Arduino accessory if suitable | High-visibility, non-color-only cue language |
| Receiver portable power and charge/power-path subsystem | Select only after UNO Q load and form-factor measurement | Required for fully portable V2; must follow board power rules |
| M2 heat-set inserts/screws or thread-forming alternatives | Decide from PCBWay process and assembly-cycle test | Serviceable enclosure fastening |
| Magnet pair plus steel keeper, or mechanical latch | Confirm carry-on safety, retention, interference, and assembly | Pod dock retention; magnets are not assumed final |
| Custom interconnect/carrier PCB | Build only if wiring/integration test justifies it | Reduce assembly time and improve reliability |
| PCBWay printed enclosure | Material/process selected after fit prototype | Required final contest deliverable |

## Manufacturer geometry used for preliminary CAD

- UNO Q board outline: 68.85 × 53.34 mm; height/connector envelopes require physical confirmation.
- XIAO ESP32S3 Sense with expansion board: 21 × 17.8 × 15 mm; camera is not used and the received stack must be inspected.
- LiPo: 29 × 36 × 4.75 mm, 102 mm lead, 10.5 g; protection/cable placement needs physical confirmation.

Sources: official Arduino store/product documentation, Seeed product sheet 113991115, Adafruit product pages 1578 and 261, and the official Autodesk contest overview.

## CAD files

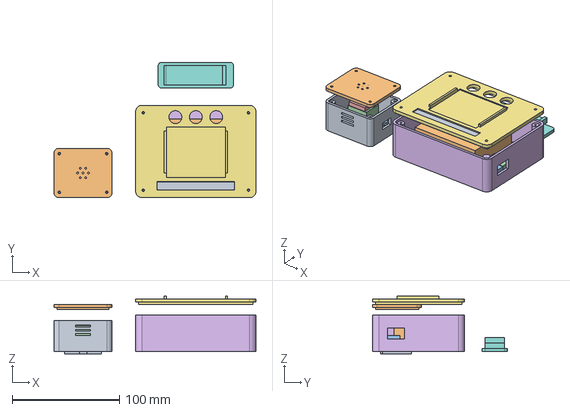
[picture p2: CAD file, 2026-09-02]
cad/reference_exports/CueLoop_Reference_Assembly.step
188.0 x 126.0 x 53.6 mm

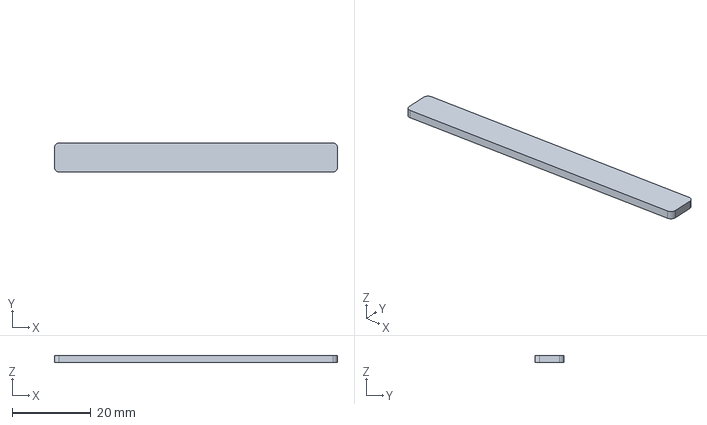
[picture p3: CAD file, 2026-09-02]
cad/reference_exports/manufacturing/Alert_Diffuser.step
72.0 x 7.40 x 1.80 mm

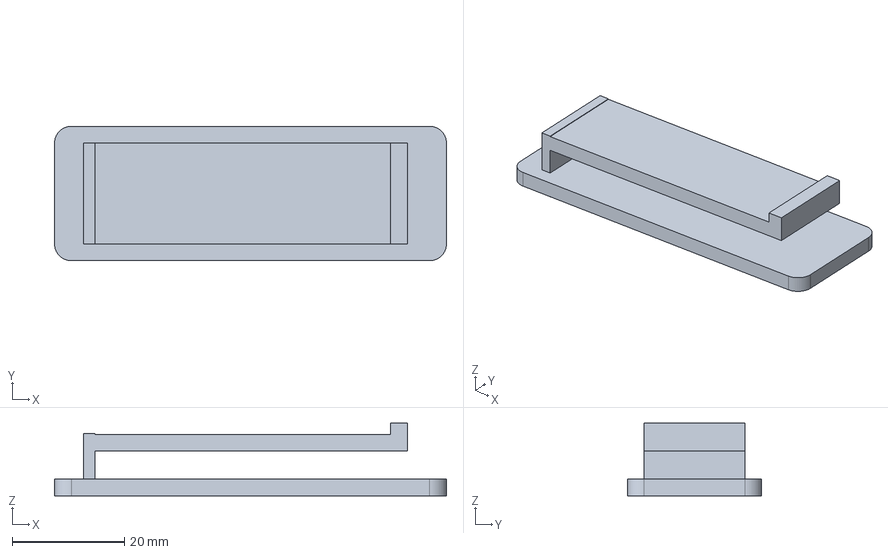
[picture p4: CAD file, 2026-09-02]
cad/reference_exports/manufacturing/Receiver_Carry_Clip.step
70.0 x 24.0 x 13.0 mm

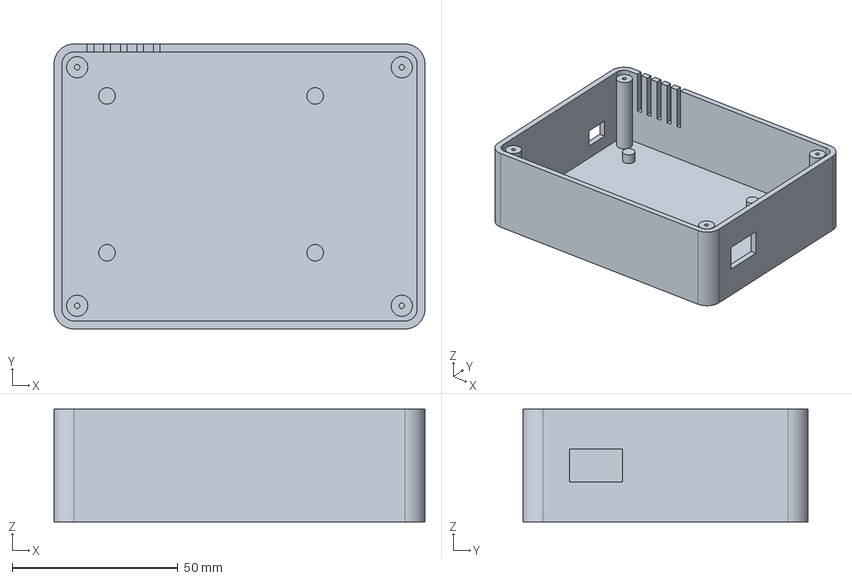
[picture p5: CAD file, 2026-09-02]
cad/reference_exports/manufacturing/Receiver_Bottom.step
112.0 x 86.0 x 34.0 mm

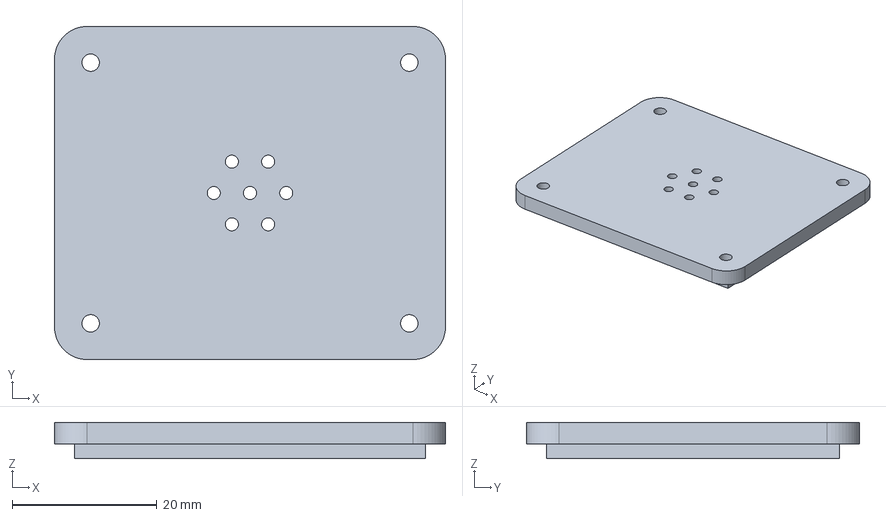
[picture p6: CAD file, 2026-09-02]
cad/reference_exports/manufacturing/CuePod_Top.step
54.0 x 46.0 x 5.00 mm

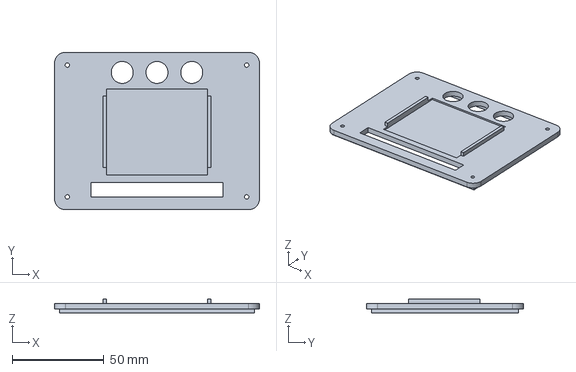
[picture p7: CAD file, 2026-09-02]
cad/reference_exports/manufacturing/Receiver_Top.step
112.0 x 86.0 x 7.80 mm

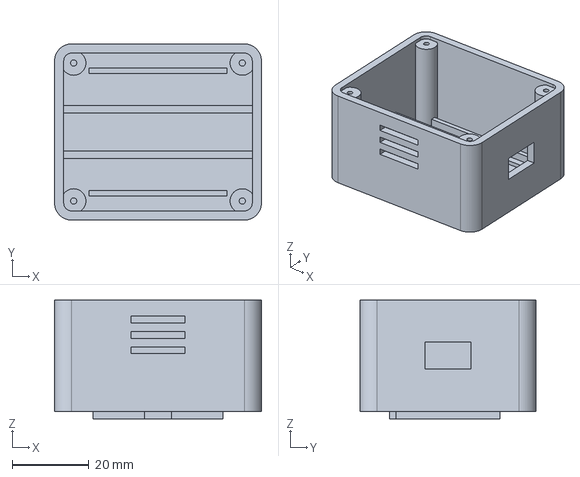
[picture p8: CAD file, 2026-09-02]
cad/reference_exports/manufacturing/CuePod_Bottom.step
54.0 x 46.0 x 31.0 mm

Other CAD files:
cad/reference_exports/CueLoop_Reference.FCStd
cad/reference_exports/manufacturing/Alert_Diffuser.stl
cad/reference_exports/manufacturing/CuePod_Bottom.stl
cad/reference_exports/manufacturing/CuePod_Top.stl
cad/reference_exports/manufacturing/Receiver_Bottom.stl
cad/reference_exports/manufacturing/Receiver_Carry_Clip.stl
cad/reference_exports/manufacturing/Receiver_Top.stl

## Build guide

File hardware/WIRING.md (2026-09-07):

# Wiring and pin assignments

## Minimum V1 external wiring

| From | To | Signal/purpose | Required verification |
|---|---|---|---|
| Adafruit 1578 battery JST-PH | Adafruit 261 mating pigtail | Detachable 1-cell LiPo connection | Connector mating and measured polarity; never trust wire color |
| Pigtail verified positive lead | XIAO `BAT+` pad | 3.7 V nominal battery positive | Seeed identifies the positive pad as the side farther from USB-C |
| Pigtail verified negative lead | XIAO `BAT-` pad | Battery return | Seeed identifies the negative pad as the side closest to USB-C |
| XIAO USB-C | Windows laptop USB-C data cable | Flash, serial configuration, USB development power/charge | Battery disconnected during soldering; known-good data cable |
| UNO Q USB-C | Approved Arduino-order supply/data/PD path | UNO Q power and App Lab connection | Exact accessory and mode confirmed from packing list/manual |
| CuePod Wi-Fi | UNO Q Wi-Fi on same trusted LAN | TCP 57321 length-framed PCM/ACK transport | 2.4 GHz support, IP address, firewall, no guest isolation |

There is no wired signal or shared ground between CuePod and UNO Q during normal use. There is no Qwiic cable in the minimum build.

## Integrated CuePod signals

These connections are already present on the Seeed Sense expansion board and must not be re-wired externally.

| Function | ESP32-S3 GPIO | Firmware API |
|---|---:|---|
| PDM microphone clock | GPIO42 | `I2S.setPinsPdmRx(42, 41)` clock argument |
| PDM microphone data | GPIO41 | `I2S.setPinsPdmRx(42, 41)` data argument |
| Audio format | — | 16 kHz, mono, signed 16-bit, 320 samples/20 ms |

The XIAO hardware does not expose a verified software battery-voltage divider for this build; battery telemetry remains invalid/zero by default.

## UNO Q minimum and optional connections

| Ref/function | UNO Q pin | Other terminal | Firmware state |
|---|---|---|---|
| Event RGB | MCU LED3 R/G/B (`PH10/PH11/PH12`) | Onboard | Required fallback; class color and priority cadence |
| Health RGB | MCU LED4 R/G/B (`PH13/PH14/PH15`) | Onboard | Green healthy, blue muted, blinking red unhealthy |
| Optional acknowledgement | D4 | Normally-open S1 to GND | `INPUT_PULLUP`; safely inactive when absent |
| Optional haptic | Unassigned | Qualified driver input only | `CUELOOP_HAPTIC_PIN=-1`; disabled |
| Optional buzzer | Unassigned | Qualified driver/input only | `CUELOOP_BUZZER_PIN=-1`; disabled |

All UNO Q MCU GPIO is 3.3 V logic. The current Arduino pinout states MCU GPIO is 5 V tolerant except A0/A1, but CueLoop V1 does not rely on 5 V signaling. Do not connect an actuator until its driver, supply, grounding, and suppression are documented.

## Battery pigtail solder mapping

The authoritative mapping is measured polarity, not insulation color:

```text
Battery positive connector contact ── measured pigtail lead ── XIAO BAT+
Battery negative connector contact ── measured pigtail lead ── XIAO BAT-
                                                             (closest to USB-C)
```

Record connector-face orientation, meter reading, and lead mapping under H-307 in root `HARDWARE_TESTS.md` before tinning. The battery stays physically unplugged for every soldering, inspection, and continuity step.

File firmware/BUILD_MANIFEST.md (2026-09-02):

# Firmware build manifest

**Build date:** 2026-09-02 EDT

**Evidence tier:** development-computer compilation only

**Arduino CLI:** 1.5.1 (`01f3d4f2b`)

**Reproducible builder:** `scripts/build_firmware.sh`; clean intermediates, fixed `SOURCE_DATE_EPOCH=1788307200`, and checkout-root prefix mapping for ESP32

Compilation validates preprocessing, C++ APIs, linking, board/core compatibility, and resource accounting. It does not validate flashing, microphone data, Wi-Fi, Bridge transport, LEDs, optional actuators, power, timing, or physical behavior.

## XIAO ESP32S3 Sense CuePod

- FQBN: `esp32:esp32:XIAO_ESP32S3`
- Platform: `esp32:esp32` 3.3.11
- Result: 888,480 bytes program reported (26% of 3,342,336); 47,632 bytes global RAM (14% of 327,680), 280,048 bytes remaining
- Flash image: `firmware/xiao_cuepod/build/artifacts/xiao_cuepod.ino.bin`
- Image size: 888,624 bytes
- Image SHA-256: `651efe0835a6a934b4dbe5615920a4094d8ee476581b43468fe5f7dea30fed10`
- Merged flash image SHA-256: `2d80291b2a8e362b93a662d0d24d9f8aff087787fdea9fb97f931bbcd93d68d3`

## UNO Q STM32U585 cue controller

- FQBN: `arduino:zephyr:unoq`
- Platform: `arduino:zephyr` 0.90.0
- Direct library: `Arduino_RouterBridge` 0.4.3; complete pinned dependency set is in the App Lab `sketch.yaml`
- Result: 93,304 bytes program reported (11% of 786,432); 34,018 bytes global RAM (12% of 262,144), 228,126 bytes remaining
- Binary: `firmware/uno_q_cue_controller/build/artifacts/uno_q_cue_controller.ino.bin`
- Binary size: 32,464 bytes
- Binary SHA-256: `06af97d5714d0fe2caa8ac5c4d37c55a7f5b2fe895c4ba1b18f597e0be30e459`
- Signed-container candidate: `uno_q_cue_controller.ino.bin-zsk.bin`, 32,480 bytes, SHA-256 `657c39742a0a9ebf512a1198bd30282f8501e24b80a17e98817a81d417b214c5`

## Exact App Lab sketch profile

The self-contained `app_lab/CueLoop/sketch` was also compiled using its isolated `uno_q` profile. It reported the same 93,304-byte program and 34,018-byte RAM use. Its `.bin` and `.bin-zsk.bin` hashes exactly match the canonical UNO Q outputs above, demonstrating that the synchronized App Lab MCU source and pinned profile reproduce the canonical binaries on this builder.

The XIAO application and merged images were independently rebuilt in a second local clone with the same relative work paths and matched byte-for-byte. Without the fixed epoch, ESP32 core compile-time strings change; without prefix mapping, the image's embedded ELF digest changes with the checkout path even when loadable program bytes are otherwise identical. Only artifacts produced by the documented builder should be compared to the hashes above.

Build products remain ignored but are retained in the working copy for later Windows flashing. Run the builder and compare hashes after any firmware, platform, library, or build-policy change.

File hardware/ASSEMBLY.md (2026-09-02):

# Battery-safe assembly order

This procedure stops at every point where a wrong assumption could damage the cell or boards. Keep the CuePod enclosure open and the LiPo outside it during first power and charging checks.

## 1. Inventory and inspect

1. Photograph both sides and record exact markings/revisions for UNO Q, XIAO main board, Sense expansion, battery, pigtail, cables, power supply/hub, and any Modulinos.
2. Reject/stop for a swollen, dented, punctured, hot, odorous, corroded, or abraded cell; damaged connector; loose component; cracked board; or exposed conductor.
3. Confirm the Sense expansion board and antenna are present and properly seated. The camera is unused; do not remove parts until the exact received stack is documented.
4. Confirm the USB cables carry data, not only power.

## 2. Bring up boards on USB before soldering

1. Leave the LiPo and pigtail disconnected.
2. Flash/test the XIAO from USB using the Windows checklist, first in `TEST ON`, then `TEST OFF` microphone mode.
3. Run Arduino's Blink/App Lab smoke test on UNO Q, then deploy CueLoop and verify LED3/LED4 behavior.
4. Stop for resets, unexpected heat, odor, unstable power, or damaged connectors.

## 3. Identify battery and pigtail polarity

1. Prove the multimeter on a known low-voltage source; black lead COM, red lead voltage/ohms jack, DC volts selected.
2. With pigtail **not attached to the board**, carefully measure the protected battery connector contacts without bridging them. A positive display means the red probe is on battery positive. Photograph/record the connector face orientation.
3. Mate battery and pigtail away from metal, measure at the stripped pigtail ends, and label the actual positive/negative leads. Disconnect the battery immediately afterward.
4. Seeed states XIAO BAT- is closest to USB-C and BAT+ is farther away. Verify the received board markings/revision before proceeding.

## 4. Solder only the detached pigtail

1. Confirm both USB and battery are physically disconnected. Move the LiPo away from the soldering area.
2. Trim only as needed, slide on insulation/strain-relief material before soldering, tin quickly, and solder measured pigtail positive to `BAT+` and negative to `BAT-`.
3. Never solder a battery lead while its cell is attached and never solder directly to the cell tabs/pouch.
4. Inspect under good light/magnification. Confirm no splash, whisker, cold joint, exposed conductor, or strain on the pads.

## 5. Unpowered electrical checks

1. With battery and USB still disconnected, continuity-check each connector contact to its intended BAT pad.
2. Check BAT+ to BAT-. A momentary changing resistance from capacitance can be normal; a persistent near-zero/continuity indication is a stop condition.
3. Confirm neither battery lead contacts shields, fasteners, antenna, microphone opening, or conductive enclosure features.

## 6. USB validation of the finished pigtail

1. Keep the LiPo detached; power XIAO by USB on a nonflammable surface.
2. Re-run firmware status/test tone. Inspect temperature and stability for at least five minutes.
3. If safely accessible, measure DC voltage/polarity at the empty battery connector. Stop for reverse polarity or any value inconsistent with a one-cell charging path; do not short the contacts.
4. Disconnect USB and wait before moving the assembly.

## 7. First battery power

1. Place the cell on a nonflammable surface outside the enclosure. Reconfirm there is no USB power.
2. Mate the verified connector while observing the board/cell. Do not force it.
3. Run `POWER BATTERY`, `TEST ON`, and `STATUS`; verify boot, Wi-Fi, packet counters, and no unexpected heat for five minutes.
4. Switch `TEST OFF` only after the deterministic transport test passes.
5. Disconnect the cell before installing/removing any enclosure, fastener, restraint, or wire routing.

## 8. Enclosure and strain relief

1. Complete CAD dimension/fit validation. Remove sharp support scars and debris.
2. Restrain the battery without bending, crushing, puncturing, or placing screw tips/board edges against the pouch. The lead must have strain relief and the connector must remain serviceable.
3. Keep microphone and antenna paths clear. Do not make a sealed heat trap.
4. Close the enclosure only after a powered open-air run passes. Initial charging remains supervised with the enclosure open.

Record every observation against the current Git commit in root `HARDWARE_TESTS.md`; copy only reviewed summaries to `HARDWARE_RESULTS.md`. The short execution order is in `user_checklists/HARDWARE_BRINGUP.md`.

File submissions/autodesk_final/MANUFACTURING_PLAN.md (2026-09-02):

# CueLoop Bridge manufacturing and DFM plan

The Autodesk competition describes a concept that could be produced in approximately 750 units. This plan does not claim that quantity has been quoted, manufactured, certified, or economically validated. It identifies the evidence needed to move from a PCBWay prototype to a repeatable product.

## Manufacturing inputs under revision control

- Native Fusion `.f3d` assembly and, if built, Electronics schematic/board linkage.
- Released STEP/3MF or process-specific geometry with units, orientation, material, finish, color, and quantity.
- Dimensioned drawings for critical interfaces, datums, tolerances, fasteners/inserts, diffuser/acoustic features, connector access, and inspection points.
- Versioned BOM with approved manufacturer parts, alternates policy, supply status, price/currency/date, and consumables.
- Assembly work instruction, torque/adhesive/ESD notes, firmware provisioning, serial/label policy, and end-of-line test.
- License/attribution and export/safety/regulatory review appropriate to the final design and markets; no certification is implied by this project.

## Process-selection matrix

| Attribute | SLS/MJF-style nylon candidate | Resin candidate | FDM prototype | Later molded split |
|---|---|---|---|---|
| Early complex geometry | strong candidate | fine detail but material/impact/UV questions | fast local iteration | tooling not justified before geometry freeze |
| Clip fatigue/impact | coupon and cycle test required | likely higher risk; datasheet/test required | anisotropy/orientation critical | material/flow/hinge redesign required |
| Surface/labels | finish/dye and text coupon | strong detail | limited without post-process | texture/marking built into tool |
| Dimensional control | supplier/process tolerance evidence | cure/shrink evidence | printer-specific | tolerance stack/tool qualification |
| Quantity ~750 | quote and nesting required | quote/post-cure labor required | assembly/finish labor likely high | compare tooling plus unit economics only after stable demand |

No process wins from this table alone. Select after coupon, supplier feedback, functional load, acoustic, thermal, finish, lead-time, cost, and repair evidence.

## DFM checklist

- Maintain consistent printable walls and intentional transitions; avoid unexplained thick heat/shrink masses.
- Use radii/fillets at clip, boss, latch, and dock stress concentrations; measure load/fatigue instead of relying on appearance.
- Define mating gaps with a process/material coupon, not a universal printer assumption.
- Keep fastener pilot/clearance/insert geometries process-specific and away from thin edges.
- Use accessible, nonhidden fasteners where possible; minimize unique screw types and assembly direction changes.
- Provide hard stops so screws or closures cannot compress a pouch cell, board, diffuser, or actuator.
- Isolate haptic energy from microphone/board where required and characterize self-noise/coupling.
- Keep microphone openings protected from direct contact while avoiding a water/debris claim without ingress testing.
- Keep antenna volumes free of metal, dense wiring, cells, magnets, and coatings until RF behavior is measured.
- Keep UNO Q connectors, recovery controls, indicators, and ventilation/thermal paths accessible.
- Make battery/power connectors keyed, strain-relieved, inspectable, and serviceable under a documented power-off order.
- Add physical orientation, privacy/local-processing, pod-location, and serial/revision marks that remain readable after finish.
- Check carry-on/product safety with actual cell documentation and destination rules; “portable” is not automatic regulatory approval.

## Prototype inspection plan

1. Quarantine and identify each received part by order/revision/process/material/finish.
2. Photograph all faces before assembly and record warp, cracks, uncured material, sharp edges, occluded holes, weak features, or finish defects.
3. Measure datums, overall envelopes, mating gaps, boss/hole/insert/test-coupon features, acoustic ports, diffuser, dock, and clip geometry using the declared instrument/resolution.
4. Dry-fit inert/uncharged parts first; never force the cell, board, connector, or fastener.
5. Record nonconformances against drawing requirements and disposition them as use-as-is for a named prototype, rework with method, or redesign/reorder. Do not silently sand/drill away traceability.

## Assembly concept

Target one-direction serviceable assembly: install protected/insulated power and any carrier/harness; install UNO Q on verified supports; install light/haptic/control components; route/strain-relieve cables; perform electrical baseline; install diffuser/controls; close lid with controlled fasteners; provision firmware; run end-of-line test; add traceable label. CuePod follows the battery-safe order in `hardware/ASSEMBLY.md` and `HARDWARE_TESTS.md`.

## End-of-line test concept

Each unit/revision record should cover:

1. visual identity/assembly/fastener/label inspection;
2. power-off continuity/short checks at designated test points;
3. current-limited first power and rail/current sanity;
4. board identity, firmware/App/model/protocol version and checksum;
5. self-test of LEDs, haptic, buttons, health/fault patterns, and dock/pod presence if implemented;
6. controlled network/audio signature path with event/acknowledge/mute;
7. privacy audit showing no raw-audio artifact and clearable metadata;
8. short thermal/current observation and charge/power-path function where present;
9. final enclosure, clip/stand/dock, connector, microphone, and antenna access inspection.

Pass limits must be frozen from measured engineering builds before they become production criteria. Store only nonpersonal unit metadata; never provision customer Wi-Fi credentials at manufacturing test.

## Approximately-750-unit review

Before claiming manufacturability at that scale, obtain process-specific quotes and analyze yield/scrap, setup/tooling, inspection labor, assembly time, programming fixture, packaging, logistics, spares/repair, component lifecycle, traceability, warranty, certifications, and regional tax/shipping. The contest prototype can demonstrate a credible path without pretending these commercial gates have passed.

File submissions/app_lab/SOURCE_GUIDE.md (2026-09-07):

# CueLoop source and reproduction guide

This map is written for a reviewer or contributor starting from a clean checkout. The authoritative runtime code lives once under `linux/cueloop`; `scripts/sync_app_lab.py` copies a controlled subset byte-for-byte into the self-contained App Lab folder and tests reject drift.

## Start here by role

| Goal | Entry point | Supporting contract/tests |
|---|---|---|
| See the system locally | `./scripts/demo.sh` | `linux/cueloop/simulator.py`, dashboard under `linux/cueloop/dashboard/` |
| Run all standard-library tests | `./scripts/test.sh` | `tests/` |
| Understand framed TCP bytes | `shared/protocol.md` | `linux/cueloop/protocol.py`, `shared/cueloop_protocol.h`, `tests/test_protocol.py` |
| Flash the CuePod | `firmware/xiao_cuepod/xiao_cuepod.ino` | local hardware/protocol headers and firmware README |
| Understand inference/policy | `linux/cueloop/yamnet.py`, `engine.py` | class mapping, model/evaluation tests |
| Deploy UNO Q App | `app_lab/CueLoop/python/main.py` | `app.yaml`, pinned `sketch/sketch.yaml`, App README |
| Understand physical cues | `firmware/uno_q_cue_controller/uno_q_cue_controller.ino` | `linux/cueloop/bridge.py`, Bridge tests |
| Reproduce the model | `scripts/fetch_yamnet.py` | `models/model_manifest.json`, `requirements-model.txt` |
| Audit UNO Q Python distributions | `scripts/audit_unoq_runtime.py` | target hash lock, runtime manifest, ELF/metadata tests |
| Evaluate licensed audio | `models/evaluate.py` | manifest/schema, `linux/cueloop/evaluation.py` |
| Build a release ZIP | `scripts/package_app_lab.py` | package tests and generated internal manifest |
| Build a source release | `scripts/package_source_release.py` | committed-tree manifest, privacy guards, deterministic ZIP |
| Verify a fresh checkout | `scripts/verify_clean_checkout.sh` | tests, Pyright, deterministic firmware, model gate, both release types |
| Build safely | `user_checklists/HARDWARE_BRINGUP.md` | `hardware/`, `docs/safety.md`, physical matrix |
| Generate authoritative CAD | `cad/fusion/CueLoopBridgeGenerator.py` | native Fusion contract/runbook; independent OpenCascade reference and host validator |

## Runtime modules

| Module | Responsibility | Boundary |
|---|---|---|
| `constants.py` | sample/frame/window dimensions and vocabulary | no board-specific state |
| `protocol.py` | strict encode/decode, flags, CRC, receiver ACK | rejects unknown flags and malformed lengths |
| `buffering.py` | bounded packet reorder/gap representation and overlapping windows | huge jumps do bounded work |
| `model.py` | classifier protocol and deterministic synthetic signatures | simulated outputs always labeled simulated |
| `yamnet.py` | checksum/tensor/embedded-label validation and LiteRT inference | optional third-party import; no fallback |
| `engine.py` | observe/confirm/alert/cooldown/mute policy | at least two qualifying windows |
| `storage.py` | bounded SQLite event/feedback records | fixed metadata schema; no audio column |
| `pipeline.py` | decode → buffer → model → policy → store/output orchestration | shares one path for simulated/physical packets |
| `bridge.py` | bounded compact Arduino Router Bridge calls and MCU status | exceptions become diagnostics, not receiver crashes |
| `api.py` | local REST/static dashboard server | trusted-LAN/localhost only; no authentication in V1 |
| `service.py` | CLI, framed TCP receive/ACK, HTTP lifecycle | real YAMNet selected explicitly |
| `simulator.py` | signatures/WAV replay and loss/jitter/reorder/restart injection | WAV provenance remains operator responsibility |
| `evaluation.py` | manifest gate and dataset-scoped metrics | refuses missing license/consent/checksum |

## Exact packet and event boundaries

The two-byte stream prefix, 684-byte audio packet, and 24-byte heartbeat are documented byte-for-byte in `shared/protocol.md`. Python is the host reference encoder/decoder; the XIAO manually builds network-order headers and little-endian PCM with the same CRC algorithm. The event database accepts only the fields in `shared/event.schema.json`/`EVENT_COLUMNS`. That explicit schema is the privacy control: an audio blob cannot be accidentally added as an extra dictionary key.

## App Lab synchronization

Run:

```bash
python3 scripts/sync_app_lab.py --include-model
python3 scripts/sync_app_lab.py --check --include-model
```

The first operation copies approved core files, dashboard assets, UNO Q sketch/header, mapping, model/runtime manifests, target dependency lock, and the ignored verified model. The second compares bytes and checksum without writing. Tests run the no-model drift check so clean clones remain testable.

`scripts/package_app_lab.py` repeats the model/source gate, refuses a release archive when any packaging input differs from `HEAD`, excludes build/cache/database/audio/secret-like files, writes an empty `data/` directory, adds a per-file `PACKAGE_MANIFEST.json` with the exact source commit and clean-tree result, fixes ZIP timestamps/permissions for deterministic output, and produces a SHA-256 sidecar. The release archive and model remain ignored. `--allow-dirty` exists only for development tests; never use it for a submission archive.

`scripts/package_source_release.py` packages blobs from exact committed `HEAD`, not arbitrary working-copy bytes. It omits the internal `PROJECT_PROMPT.md`, rejects credential/audio/model/database/build artifact paths, adds the commit plus per-file SHA-256 values to `SOURCE_MANIFEST.json`, and writes an ignored digest sidecar. It refuses a dirty tracked worktree by default; `--allow-dirty` exists for automated testing and still packages committed `HEAD` only.

## Reproducible dependency boundary

- Desktop simulator/service: Python 3.11+ standard library.
- Model path: the complete `ai-edge-litert==2.2.0` dependency set is pinned. `models/requirements-unoq-cp313.lock` and `unoq_runtime_manifest.json` hash-audit the documented CPython 3.13/Linux ARM64 distributions; actual App Lab resolution/import/inference remains a target record.
- XIAO: Arduino CLI 1.5.1, `esp32:esp32` 3.3.11, core libraries only.
- UNO Q: `arduino:zephyr` 0.90.0 plus every library/version in App Lab `sketch.yaml`.
- Downloaded YAMNet: exact URL, byte count, SHA-256, input/output contract, license, and limitations in `models/model_manifest.json`.

## Test organization

- `test_protocol.py`: round trip and corruption rejection for audio/ACK.
- `test_buffering.py`: reorder, loss fill, wraparound, restart, huge jump, bounds.
- `test_model_engine_storage.py`: synthetic mapping, temporal policy, cooldown/mute, storage privacy.
- `test_pipeline_api.py`: end-to-end simulated packets, malformed input, REST controls/dashboard.
- `test_bridge.py`: exact RPC translation, failure containment, status/restart logic.
- `test_yamnet_mapping.py` and `test_evaluation.py`: mapping labels/aggregation and provenance gates/metrics.
- `test_app_lab_package.py`: mandatory structure, pinned dependencies, source/model/archive integrity.
- `test_unoq_runtime_audit.py`: target lock/manifest/App-copy integrity and downloaded wheel metadata/hash/AArch64 ELF audit.
- `test_hardware_docs.py`: safe net connectivity and valid accessible schematic source.
- `test_cad_application.py`: native Fusion API/export/provenance contract, critical clearances, OpenCascade STEP/STL output integrity/interference, and Autodesk answer/evidence gates.
- `test_simulated_transport_benchmark.py`: deterministic clean/moderate/severe fault profiles and software-only claim boundary.
- `test_project_completion_docs.py`: canonical hardware workflow, V2 final structure, and experiment registry contract.
- `test_submission_release.py`: required publication assets, video evidence labels, and deterministic sanitized source release.
- `test_reproducibility.py`: fixed-time/path-normalized firmware builder, minimum-Python static-analysis target, and fresh-checkout release surface.

Compilation results are not tests of attached hardware. Physical observations enter through root `HARDWARE_TESTS.md`; only reviewed summaries enter `HARDWARE_RESULTS.md` and submission copy.

## Safe contribution rules

1. Run `./scripts/test.sh`, Pyright, and `./scripts/build_firmware.sh` in proportion to the changed surface; use `./scripts/verify_clean_checkout.sh` at release checkpoints.
2. Sync the App Lab vendor tree after changing an approved core or UNO Q sketch file.
3. Do not relax the model checksum, evidence-tier labeling, minimum temporal evidence, raw-audio boundary, or safety language merely to make a demo pass.
4. Add/modify packet fields only with a versioned shared protocol change and cross-language tests.
5. Store credentials in XIAO NVS through serial or ignored local configuration—not source.
6. Keep recordings, model weights, build products, databases, caches, and archives ignored.
7. Cite licenses/provenance for any reusable model, audio, code, UI, image, font, or video asset.
8. Report failed physical targets honestly and narrow the supported vocabulary when evidence demands it.

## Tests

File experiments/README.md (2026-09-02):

# CueLoop experiment registry

Use this directory for predeclared methods and curated, nonprivate summaries. Machine output belongs under ignored `experiments/results/`; audio belongs under ignored private data paths. Hardware observations are executed and logged in root `HARDWARE_TESTS.md`, then summarized in `HARDWARE_RESULTS.md`.

## Experiment lifecycle

1. Copy `experiment.example.json`, assign a stable `EXP-###` ID, and state the question before collecting data.
2. Declare independent/dependent variables, controls, sample/repetition plan, acceptance target, evidence tier, safety/privacy constraints, and artifact paths.
3. Freeze calibration/validation/test boundaries before evaluating a model; preserve seed/source groupings.
4. Run without changing the target after seeing results. Record deviations explicitly.
5. Keep raw/private/generated artifacts ignored. Commit only a curated summary with method, counts, units/distribution, commit, limitations, and the manifest/result digest.
6. A failure remains a result. A simulated run never closes a physical experiment.

## Planned registry

| ID | Question | Evidence tier required | Execution record | Status |
|---|---|---|---|---|
| EXP-001 | How does packet loss/jitter/reordering affect the complete software path? | simulated | `benchmarks/simulated-transport-2026-09-02.md` | Complete; software-only |
| EXP-101 | Which V1 classes meet held-out precision/recall/false-trigger targets? | licensed/self-recorded development-host then UNO Q | H-200 in `HARDWARE_TESTS.md` | Pending data/target |
| EXP-102 | What benefit/cost does temporal confirmation have versus one-window decisions? | same held-out records/policies | evaluator comparison + H-200 | Framework complete; data pending |
| EXP-103 | What is physical acoustic-to-cue latency? | physical CuePod + UNO Q | H-302 | Pending hardware |
| EXP-104 | How do distance, door, background, and LAN path change quality? | physical CuePod + UNO Q | H-101–H-108 | Pending hardware |
| EXP-105 | What are CuePod runtime, charge, and thermal behaviors? | physical CuePod | H-307–H-310 | Pending hardware |
| EXP-201 | Does the V2 acoustic labyrinth improve robustness without harmful attenuation? | physical V2 revisions | Autodesk `EVIDENCE_MATRIX.md` | Pending CAD/hardware |
| EXP-202 | Which portable cue/attachment design is understood and comfortable? | consented physical V2 evaluation | Autodesk `EVIDENCE_MATRIX.md` | Pending interaction hardware |

Do not create experiments merely to inflate a test count; every experiment must change a real product decision or substantiate a bounded claim.

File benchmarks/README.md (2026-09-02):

# Benchmark evidence

Committed summaries in this directory must state the execution host, workload provenance, model/artifact identity, measurement method, and claim boundary. Machine-readable run output goes under ignored `benchmarks/results/` so repeated runs do not pollute source control.

The deterministic transport benchmark exercises the encoded packet → bounded receiver → window → synthetic classifier → temporal-policy path across clean, 5% loss/moderate jitter, and 20% loss/severe jitter profiles:

```bash
PYTHONPATH=linux python3 benchmarks/simulated_transport.py \
  --output benchmarks/results/simulated-transport.json --quiet
```

Its synthetic signatures were authored to test plumbing. Detection rate from this benchmark is not a real-audio model metric or a wireless/RF result.

Evidence tiers are not interchangeable:

- **simulated workload / development computer:** software integration and host latency only;
- **licensed real audio / development computer:** dataset-scoped model metrics, not device performance;
- **UNO Q replay:** target inference performance from provenance-complete prerecorded clips;
- **physical CuePod end to end:** microphone, wireless, target, and cue measurements from the actual assembly.

Never promote a result to a stronger tier without running that setup and retaining its protocol in `HARDWARE_TESTS.md` plus its reviewed summary in `HARDWARE_RESULTS.md`.

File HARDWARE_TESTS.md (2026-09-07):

# CueLoop Windows flashing and hardware test record

This is the authoritative executable workflow for every board-dependent CueLoop V1 gate. It combines Windows deployment, safe electrical bring-up, model/network testing, and the observation log so hardware unavailability does not stop digital preparation. `HARDWARE_RESULTS.md` is the short publication boundary; measured summaries move there only after the corresponding record in this file is complete.

**Current state:** no physical board, cell, cable, accessory, App Lab run, or Fusion-generated file has been observed. Every hardware row below is pending.

## Evidence and record rules

Use exactly one evidence tier for every number:

- **simulated** — generated packets/audio/faults with no attached board;
- **development-computer** — measured on the Ubuntu or Windows build computer;
- **UNO Q** — measured on the identified physical UNO Q Linux/MCU target;
- **physical CuePod** — measured through the identified XIAO Sense microphone/transport;
- **estimated** — derived from a datasheet or arithmetic, not observed.

For each executed test, copy this block into the execution log at the end of this file:

```text
Test ID:
Date/time/timezone:
Git commit:
Operator:
Hardware identities/revisions/markings:
Windows version:
Arduino App Lab / IDE / CLI / core / library versions:
Firmware/App version and archive SHA-256:
Power source and connection path:
Network/AP/band/client-isolation conditions (no credentials):
Audio source/provenance/consent, distance, door, background, repetitions:
Expected observation or predeclared target:
Observed values with units/distribution:
Evidence tier:
Pass / fail / blocked / not run:
Error text and safe artifact paths:
Notes/limitations:
```

Never record Wi-Fi credentials, private audio, personal data, or an unredacted SSID/IP screenshot in Git. A failed target is evidence and must remain visible.

## Immediate stop conditions

Stop, disconnect external power if safe, and record the condition for heat, odor, swelling, puncture, damaged insulation, reverse/ambiguous polarity, a suspected battery short, smoke, unstable voltage, unexpected reset loops, or a board/cell marking that contradicts the procedure.

- Never solder with USB or the LiPo connected.
- Never solder directly to a LiPo cell.
- Never put an ammeter or resistance/continuity mode directly across a battery.
- Never trust wire color as polarity evidence.
- Never substitute a Qwiic cable for the JST-PH battery pigtail.
- Keep the LiPo detached for every flash and initial USB-only test.
- Do not drive a motor, haptic, buzzer, or other load directly from an MCU GPIO.

Read `docs/safety.md` and `hardware/ASSEMBLY.md` completely before tests H-300 through H-307.

## Release inputs to transfer to Windows

Generate from a clean tested commit on Ubuntu:

```bash
python3 scripts/sync_app_lab.py --include-model
python3 scripts/package_app_lab.py --version 0.1.0
python3 scripts/package_source_release.py --version 0.1.0
```

Transfer through a trusted path:

- `packages/CueLoop-App-Lab-v0.1.0.zip` and its `.sha256` sidecar;
- `packages/CueLoop-Source-v0.1.0.zip` and its `.sha256` sidecar;
- the XIAO sketch under `firmware/xiao_cuepod/`;
- optionally the ignored Ubuntu artifact folders for hash comparison, not guessed-address flashing.

Release ZIP identities are intentionally not hard-coded in this tracked file: the
source ZIP contains this file, so editing its digest here would immediately create
a different source archive. Generate both archives only from the final clean commit,
then retain their adjacent `.sha256` sidecars and verify the embedded commit fields:

| Artifact | SHA-256 / identity |
|---|---|
| App Lab ZIP | Adjacent `.sha256`; `PACKAGE_MANIFEST.json` must say `source_tree_clean: true` and its `source_commit` must equal `git rev-parse HEAD` |
| Source ZIP | Adjacent `.sha256`; `SOURCE_MANIFEST.json` `commit` must equal `git rev-parse HEAD` |
| YAMNet inside App | `10c95ea3eb9a7bb4cb8bddf6feb023250381008177ac162ce169694d05c317de` |
| XIAO platform/FQBN | `esp32:esp32` 3.3.11 / `esp32:esp32:XIAO_ESP32S3` |
| UNO Q platform/FQBN | `arduino:zephyr` 0.90.0 / `arduino:zephyr:unoq` |

In PowerShell, compare the calculated values to the sidecars:

```powershell
Get-FileHash .\CueLoop-App-Lab-v0.1.0.zip -Algorithm SHA256
Get-Content .\CueLoop-App-Lab-v0.1.0.zip.sha256
Get-FileHash .\CueLoop-Source-v0.1.0.zip -Algorithm SHA256
Get-Content .\CueLoop-Source-v0.1.0.zip.sha256
```

Do not proceed if either digest differs.

Also open both embedded manifests and compare their full 40-character commit to
the clean release commit. A matching sidecar alone does not prove that the archive
was generated from the intended source revision.

## Gate W-000 — inventory and Windows preparation

| ID | Action | Expected observation / record |
|---|---|---|
| W-001 | Photograph and record every delivered item/packing-list row. | UNO Q identity/configuration, XIAO/Sense/antenna, protected cell and pigtail, exact USB/power path, tools, accessories, markings, quantities, and visible condition are known. |
| W-002 | Install current official Arduino App Lab for 64-bit Windows 10/11. | App Lab version and installer source recorded; no unofficial package used. |
| W-003 | Install Arduino IDE 2 and Espressif Boards Manager URL `https://raw.githubusercontent.com/espressif/arduino-esp32/gh-pages/package_esp32_index.json`. | IDE version recorded; **esp32 by Espressif Systems 3.3.11** installed. |
| W-004 | Verify known USB-C cables/path carry data before connecting the product. | Cable/path identity recorded; Windows Device Manager changes on attach. |
| W-005 | Confirm a trusted 2.4 GHz-capable LAN permits client-to-client TCP. | No guest/IoT isolation; public/hostile Wi-Fi is not used; VPN/firewall constraints recorded without credentials. |

If Windows prompts for `mdns-discovery.exe`, allow private-network access only as appropriate for this trusted LAN. Network discovery uses mDNS/UDP 5353 and may fail on isolated networks even when internet access works.

## Gate W-100 — UNO Q baseline and App Lab deployment

Keep the CuePod cell detached throughout this gate.

| ID | Procedure | Expected observation / decision |
|---|---|---|
| W-101 | Connect UNO Q with the identified Arduino-order data/power path following the official host/SBC connection mode. | Board identity, 4 GB/32 GB configuration, connection mode, Linux image/update state, LAN address, and App Lab version recorded. |
| W-102 | Run Arduino App Lab’s built-in Blink example. | Documented MCU RGB LED blinks and App Lab reports success. Stop if this board baseline fails. |
| W-103 | Import the verified CueLoop ZIP, or extracted top-level `CueLoop` folder only if this App Lab version requests a directory. | `app.yaml`, `python/main.py`, requirements, sketch/profile, mapping, 4,126,810-byte model, and empty `data/` are present. |
| W-104 | Select UNO Q and press **Run**. | App Lab resolves the complete pinned runtime set, deploys Linux, compiles/flashes STM32, and starts both. Full resolver/monitor output and App Lab/image versions recorded. |
| W-105 | Observe health before and after Linux heartbeats. | LED4 may blink red while unhealthy, then becomes green; LED3 remains off until a confirmed cue. |
| W-106 | Inspect monitor/model startup. | Retain `CueLoop runtime: Python ...; machine=...; libc=...; ai-edge-litert=...`; expected audited family is Python 3.13, ARM64/AArch64, LiteRT 2.2.0. Dashboard and TCP startup appear; no native-import, checksum, tensor, embedded-label, database, socket, or Bridge error. |
| W-107 | Browse to `http://<UNO-Q-IP>:8080/` and `/api/status`. | Dashboard loads; local/no-recordings and model/input/connection states are visible; pod initially disconnected; Bridge status becomes connected. |
| W-108 | Inspect App `data/` before activity. | Empty except App-managed placeholders; no previous database or audio. |
| W-109 | Enable **Run at startup** only after the manual run and restart test pass. | Optional setting and resulting reboot behavior recorded. |

The Ubuntu distribution audit proves a complete exact-hash wheel set headed by `ai-edge-litert==2.2.0` exists for Arduino's documented CPython 3.13/Linux ARM64 runner and verifies 16 LiteRT shared objects as AArch64. It does not prove the received image's loader or model inference. If the set cannot resolve/import on the actual UNO Q image, preserve the complete Python/machine/libc/resolver/traceback output. Do not switch to synthetic inference or an unpinned runtime; that requires an evidence-backed implementation decision. Reflash the UNO Q Linux image only through the official recovery flow after diagnosing a corrupt/unresponsive OS and recording the erase impact.

## Gate W-200 — XIAO source flash and secret-safe configuration

1. Keep the LiPo detached and open `firmware\xiao_cuepod\xiao_cuepod.ino`; confirm both companion headers remain in that folder.
2. Select **XIAO_ESP32S3** and the newly appeared COM port. Keep default options; PSRAM is not required.
3. Click **Verify**, then **Upload**. Record IDE/core versions, COM port, memory report, and upload result.
4. If no port appears, use Seeed’s bootloader sequence: hold BOOT while connecting USB and release after enumeration, or hold BOOT and tap RESET. Do not press tools into nearby parts.
5. Open Serial Monitor at 115200 baud with LF endings. Expected: `CUELOOP_CUEPOD_READY`, a microphone-ready/error line, and a response to `STATUS`.

Optional PowerShell CLI path, after installing the pinned CLI/core on Windows:

```powershell
arduino-cli compile --fqbn esp32:esp32:XIAO_ESP32S3 firmware\xiao_cuepod
arduino-cli board list
arduino-cli upload --fqbn esp32:esp32:XIAO_ESP32S3 --port COM5 firmware\xiao_cuepod
```

Replace `COM5` with the observed port. Compile/upload source or use a complete tool-generated flash bundle. Never flash a standalone application `.bin` at a guessed ESP32 address.

Send these commands with actual Tab characters where `<TAB>` appears:

```text
SET_WIFI<TAB>private-ssid<TAB>password
SET_RECEIVER<TAB>UNO-Q-IP<TAB>57321
SET_POD_ID<TAB>0xC0E10001
POWER<TAB>USB
TEST<TAB>ON
STATUS
```

Expected: the password is never echoed; Wi-Fi connects; capture/sent counters increase; valid ACKs increase and `reachable=yes` after the receiver responds. Do not capture the credential command in evidence. Begin in `TEST ON`; do not claim acoustic accuracy from the generated tone.

## Gate C-100 — Windows Fusion native-model execution and return

All Ubuntu-executable CAD work is complete before this gate: the native `adsk` generator, shared parameter/contract sources, independent FreeCAD/OpenCascade implementation, committed neutral reference exports, and host validators. Read and execute `cad/FUSION_WINDOWS_RUNBOOK.md` exactly. The OpenCascade STEP is validation/reference geometry only and must never be imported as the authoritative contest model.

| ID | Procedure | Expected observation / required record |
|---|---|---|
| C-101 | Record Git commit, Windows/Fusion versions, operator/date/timezone, and SHA-256 of the Fusion script plus both JSON sources. | Inputs match the reviewed commit; any change is explained before execution. |
| C-102 | Install the three source files as one Fusion Python script and click **Run** once. | A new parametric design is created without requesting/importing STEP, mesh, BRep, or base geometry. |
| C-103 | Preserve the final message and `CueLoop_Bridge_validation.json`. | `Validation: PASS`; component/body/sketch/feature/timeline/parameter counts meet `design_contract.json`. |
| C-104 | Inspect Browser, timeline, Change Parameters, manufacturing bodies, and empty Mesh Bodies. | Hierarchy matches `cad/README.md`; six manufacturing components each finish as one solid; native sketches/features and at least 70 named parameters are visible. |
| C-105 | Change `pod_mic_hole_diameter` from 1.8 to 2.0 mm, observe all seven ports, then Undo to 1.8 mm. | Geometry updates without error, proving the native parameter/feature relationship; final retained output is restored to 1.8 mm. |
| C-106 | Complete section, measure, and interference review for shells, hardware envelopes, dock, clip, fasteners, openings, and service paths. | No unexplained collision, zero-thickness/sliver feature, floating body, blocked required opening, or impossible assembly; limitations/adjustments recorded. |
| C-107 | Close Fusion and reopen exported `CueLoop_Bridge_Native.f3d` in a clean session. | Component hierarchy, non-empty native timeline, parameters, six manufacturing solids, and reference-only names persist. |
| C-108 | Capture the ten screenshots and four native Fusion renders listed in the runbook. | Images prove native history/parameters/geometry and retain the caption `Fusion native concept render—physical enclosure and fit validation pending.` |
| C-109 | Return the complete export directory, CSV/ZIP hashes, screenshots/renders, and run record. | F3D, assembly STEP, six STEP/STL/3MF sets, exact source snapshots/manifest, BOM/parameters/validation, and checksums are non-empty and verify on Ubuntu with `cad/validate_cad.py --fusion-output`. |

If a visual defect requires adjustment, preserve the failure, update `design_parameters.json` or the generator in Git, rerun Ubuntu validation, then execute a fresh Fusion document. Do not repair a generated body manually and present it as script-generated. The completed record below closes only the Windows/Fusion digital gate; physical fit and hardware-performance claims remain pending under the applicable hardware gates.

### C-100 execution record — 2026-09-05 (PASS)

This record covers native Fusion generation and digital inspection only. It does not
claim physical enclosure fit, latch force, acoustic performance, thermal performance,
RF performance, or manufacturing readiness.

| ID | Result | Recorded observation / evidence |
|---|---|---|
| C-101 | PASS | Generation commit `bad2be99b5f221b4e65e5cc0efc6b8d50b988b4f`; validation commit `26544ed0f3f2343a16c5373ed0fb9854330304dd`; Fusion `2705.1.11 x86_64`; Windows 11 Home 25H2 (`26200.9168`). Operator, timestamp, timezone, and exact source hashes are preserved in `FUSION_RUN_RECORD.txt`. |
| C-102 | PASS | The Fusion Python generator created a new native parametric design without importing STEP, mesh, BRep, or base geometry. The immutable Fusion root-name condition was handled by the committed generator fix rather than by manually repairing generated geometry. |
| C-103 | PASS | `CueLoop_Bridge_validation.json` reports `status: pass`. The returned design contains 15 components including the root, 12 solid bodies, 269 timeline entries, and 125 user parameters; contract-required counts passed validation. |
| C-104 | PASS | Browser, timeline, parameters, manufacturing bodies, and reference components were inspected. Six manufacturing components finish as one solid each, native history is present, and the manufacturing-only view contains the expected six components. |
| C-105 | PASS | `pod_mic_hole_diameter` was changed from 1.8 mm to 2.0 mm; all seven microphone ports updated without warnings. Undo restored the retained design and all seven driven dimensions to 1.8 mm. |
| C-106 | PASS (digital scope) | CuePod and receiver sections were reviewed. Recorded dock pocket is 55 x 47 mm; CuePod outer size is 54 x 46 mm; dock tongue is 34 x 27 x 2 mm; latch depth is 1.8 mm. Manufacturing-component and hardware-envelope interference studies reported no interferences. Physical fit, latch force, acoustics, thermal/RF behavior, and DFM remain pending. |
| C-107 | PASS | The exported `CueLoop_Bridge_Native.f3d` was closed and reopened in a clean Fusion session. Compute All completed without warnings; hierarchy, timeline, parameters, manufacturing solids, and reference-only component names persisted. |
| C-108 | PASS | Final evidence contains 21 laptop PNG files plus 10 desktop images. It includes the required orthographic, hierarchy, parameter, section, measurement, interference, manufacturing, clip, reopen, render, and export/hash views. Five native Fusion concept renders carry the exact required caption. |
| C-109 | PASS | The complete Windows return archive was copied to Ubuntu and validated. The final laptop and desktop evidence archives were independently checked for byte counts, SHA-256 identities, internal file counts, manifest rows, and per-file hashes with zero issues. |

Authoritative returned-artifact identities:

- `CueLoop_Bridge_Native.f3d`: `AD85F87B2108F35DBF9DFC957B1D4231192909AE949B7276D2C08B920DEEABC2`
- `CueLoop_Bridge_Native.step`: `2F63338C7C9CB303AC1A6AED0C561A93881CA46C305807792AD561F79A2F6170`
- `CueLoop_Bridge_Native_v2_Windows_Return.zip`: 52,880,550 bytes; `D6643B17DAB3CC22308B39AC5BB0BEC495248554D7DB25B262AC4CFB3D4D2482`
- `CueLoop-Fusion-Evidence-Laptop-v3.zip`: 9,752,048 bytes; `6B37C517F26E5D7498FA5FC96043C2EEDD5F4B101C602613DA66F91781639676`
- `CueLoop-Fusion-Evidence-Desktop.zip`: 5,848,995 bytes; `80966830523A0D2C99FC632632EA2D9B33BFCAB30E4B6246208642BC57ECE605`
- Ubuntu evidence location: `cad/exports/fusion_return/2026-09-05-bad2be9/evidence/`

The validator continues to enforce the source manifest's exact raw hashes. Commit
`26544ed0f3f2343a16c5373ed0fb9854330304dd` permits only CRLF-versus-LF
normalization when comparing the Windows generator snapshot with the checked-out
Linux file.

## Gate H-000 — deterministic integrated bring-up

| ID | Test | Exact method | Expected observation / target |
|---|---|---|---|
| H-001 | XIAO USB boot | Reconnect on USB, capture serial banner/status. | Ready/mic status, no reset loop, stable/cool board. |
| H-002 | Test-tone framing | `TEST ON`; collect two `STATUS` samples at least 10 s apart. | About 50 captured/s; RMS and peak about 8192; clipped samples 0; counters rise. |
| H-003 | Wi-Fi/receiver ACK | Run CueLoop App and configured private-LAN destination. | Sent and valid ACK counters rise; `reachable=yes`; bad ACK/send-failure counters remain explainable. |
| H-004 | Receiver loss/recovery | Stop App for at least 7 s, observe, restart. | Within about 5 s reachability becomes false/timeout increments; valid ACKs resume; receiver restart visible without CuePod reboot. |
| H-005 | App/Bridge health | Observe LED4 and `/api/status` across startup. | Red unhealthy indication before heartbeat, green healthy after heartbeat; Bridge failures do not terminate Linux service. |
| H-006 | Cue language | Exercise one controlled confirmed path for each enabled class. | LED3 class family/priority cadence matches firmware; event/dashboard agree; clear/mute immediate. Test-tone/simulator paths stay labeled. |
| H-007 | Dashboard controls | Keyboard and pointer acknowledge, dismiss, mute/unmute. | Metadata action changes; MCU clears/mutes; LED4 blue while muted; no raw audio appears. |
| H-008 | Optional D4 button | Only if a normally-open D4-to-GND button is actually installed; press/release 20 times. | Exactly one acknowledgement per press, no idle phantom action. Otherwise mark not installed. |
| H-009 | MCU restart recovery | Restart/redeploy sketch during mute, then with an active pending cue. | Restart count rises; Linux stays alive and restores mute/current cue state. |
| H-010 | Privacy file audit | List App `data/` and inspect SQLite schema before/after a 15 min run. | Only bounded metadata/feedback database; no WAV/audio/blob column or audio file. |

Do not continue to battery testing or publish performance claims until H-001 through H-005 pass.

## Gate H-100 — microphone, network, and controlled loss

Use gentle, consented, provenance-recorded sources. Never strike the MEMS microphone or use a real emergency alarm at unsafe volume. Capture serial/dashboard counters before and after.

| ID | Condition | Repetitions / duration | Required measurements |
|---|---|---:|---|
| H-101 | Quiet room, `TEST OFF` microphone mode | 5 min | RMS/peak range, clipped samples, capture errors, packet loss, jitter, RSSI, disconnects |
| H-102 | Controlled event at 0.5 m line-of-sight | 10 per retained class | triggers, misses, confidence, evidence count, end-to-end latency |
| H-103 | Same source at 1 m and 3 m | 10/class/distance | precision/recall/confidence/latency by distance |
| H-104 | CuePod behind one closed interior door | 10/class | precision/recall/confidence/latency/loss and door description |
| H-105 | Background speech, television, music, fan | 15 min each | false triggers/audio-hour by condition/class; consent/source |
| H-106 | Confusable nontarget knocks, beeps, shouts | at least 10/type | suppression/confirmation behavior and false triggers |
| H-107 | Exact LAN path planned for video | 15 min | packet loss, duplicates/late, jitter, RSSI, disconnects |
| H-108 | Artificial 5% then 20% packet-loss replay | fixed licensed clips and same seed | output comparison and diagnostic accuracy; evidence remains simulated loss unless RF impairment itself is measured |

Nonconstant microphone values prove capture activity, not classifier accuracy.

## Gate H-200 — model evidence and temporal-policy comparison

1. Use self-recorded or legally reusable PCM16 mono 16 kHz WAV files under ignored storage and a complete manifest. Obtain consent for identifiable voices.
2. Keep calibration, validation, and held-out test sources separate. Never tune on the held-out test split.
3. Aim for at least 30 positive held-out examples per retained class across multiple sources/rooms and at least one hour of explicitly defined background. If unavailable, publish the actual smaller count and uncertainty.
4. Run `models/evaluate.py` and retain the generated JSON under an ignored path.
5. Report support, per-class TP/FP/FN/TN and confusion matrices, precision/recall/F1, missed-event rate, false triggers/audio-hour, calibration/Brier error, inference latency, annotated event latency where present, condition slices, and temporal versus single-window differences.
6. Retain a demo class only if held-out precision is at least 0.80 and recall at least 0.75, or disclose the miss and narrow/disable it.
7. Quiet/background goal: fewer than 1 false alert/hour on the specifically documented mixture. Never extrapolate beyond the recorded sources/environments.
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

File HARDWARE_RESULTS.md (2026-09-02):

# Hardware results

No physical results have been recorded. This file is the authoritative publication boundary between digitally verified work and reviewed observations made with real hardware.

Detailed procedures and raw observation blocks are authoritative in `HARDWARE_TESTS.md`. This file contains only reviewed inventory/result summaries suitable for publication.

## Evidence vocabulary

- **Simulated:** generated packet/audio conditions with no hardware in the loop.
- **Development-computer:** measured on the development host; record CPU/OS/version.
- **UNO Q:** measured on the physical UNO Q Linux/MCU system.
- **Physical CuePod:** measured with the XIAO Sense microphone and wireless transport.
- **Estimated:** derived from datasheets, arithmetic, or unverified assumptions.

## Inventory

| Item | Expected identity | Received / markings / quantity | Status |
|---|---|---|---|
| Arduino UNO Q | 4 GB / 32 GB, SKU ABX00173 | Not observed | Pending |
| Arduino order accessories | Exact packing list unknown | Not observed | Pending |
| Seeed XIAO ESP32S3 Sense | MPN 113991115 | Not observed | Pending |
| Protected LiPo | Adafruit 3.7 V 500 mAh, product 1578 | Not observed | Pending |
| JST-PH female pigtail | Adafruit product 261 | Not observed | Pending |
| Soldering station | YIHUA 926 III kit | Not observed | Pending |
| Multimeter | AstroAI AM33D | Not observed | Pending |

## Result records

Use one block per checklist run:

```text
Checklist ID:
Date/time/timezone:
Git commit:
Operator:
Hardware revisions/markings:
Firmware/App Lab versions:
Power source:
Test conditions:
Expected observation:
Observed value and unit:
Evidence tier:
Pass/fail/blocked:
Notes and artifact path:
```

Do not paste Wi-Fi credentials, personal data, or sensitive audio here.

## Prepared digital evidence (not a hardware result)

- Development-computer Arduino CLI compilation is recorded in `firmware/BUILD_MANIFEST.md`.
- Complete Windows flashing, bring-up, validation methods, expected observations, and the execution log are in root `HARDWARE_TESTS.md`.
- Short operator views remain in `user_checklists/WINDOWS_FLASHING.md`, `HARDWARE_BRINGUP.md`, and `PHYSICAL_VALIDATION.md`.
- No row above may change from “Not observed” until a physical operator records the observation using the result block.

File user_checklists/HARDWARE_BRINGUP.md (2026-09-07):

# Short hardware bring-up checklist

Perform this only when the hardware is present. Expected observations are explicit; stop at the first unsafe or contradictory result and append the full record to root `HARDWARE_TESTS.md`. Copy only reviewed summaries to `HARDWARE_RESULTS.md`.

1. **Inventory:** photograph and record all board/cell/accessory markings and quantities. Expected: UNO Q ABX00173 4 GB/32 GB, XIAO Sense 113991115 with antenna/Sense expansion, undamaged protected Adafruit 1578, product 261 pigtail, and exact power/data accessories.
2. **USB-only baseline:** with LiPo detached and no soldering, run UNO Q App Lab Blink and XIAO USB firmware/`TEST ON`. Expected: both enumerate, flash, remain cool/stable, and match the Windows checklist.
3. **Integrated USB test:** deploy CueLoop, configure private-LAN receiver, and run test tone. Expected: dashboard port 8080 loads; TCP frames/ACKs advance; LED4 becomes green; Bridge cue/mute/ack work; no raw-audio file appears.
4. **Microphone smoke test:** switch `TEST OFF` and inspect counters/response to quiet, close speech, and gentle tapping near—not on—the enclosure. Expected: capture continues and samples are nonconstant/nonclipped; no accuracy claim yet.
5. **Battery polarity:** with all power removed, measure battery contact polarity, mate pigtail away from the board, measure/label lead polarity, then disconnect battery. Expected: mapping agrees with XIAO `BAT+` farther from USB and `BAT-` closest to USB. Do not proceed on any ambiguity.
6. **Solder:** move LiPo away; with USB and battery detached, solder only the pigtail to verified BAT pads, insulate/strain-relieve, inspect, then continuity/resistance-check. Expected: correct end-to-end mapping and no persistent low-resistance BAT+↔BAT- short.
7. **First battery run:** after a final USB-only test, disconnect USB, place cell outside enclosure on a nonflammable surface, mate connector, set `POWER BATTERY`, and run test tone for five minutes. Expected: stable boot/network/ACKs and no heat, odor, swelling, resets, or lead movement.
8. **Mechanical fit:** disconnect battery before assembly. Validate CAD dimensions, mic/antenna/USB openings, cell restraint, screw clearance, and service access. Expected: no cell compression/sharp contact, no pinched wire, no blocked mic/antenna, and enclosure closes without force.
9. **Validation matrix:** run recovery, distance/door/noise, model, latency/loss, current/runtime, and accessibility gates H-100 through H-400 in root `HARDWARE_TESTS.md`; `PHYSICAL_VALIDATION.md` remains a compact matrix. Expected: every result has units, conditions, commit, and evidence tier; failures remain visible.

Record each stop/pass as:

```text
Checklist ID:
Date/time/timezone:
Git commit:
Operator:
Hardware revisions/markings:
Firmware/App Lab versions:
Power source:
Test conditions:
Expected observation:
Observed value and unit:
Evidence tier:
Pass/fail/blocked:
Notes and artifact path:
```

Never solder with the battery connected, never solder the LiPo cell, never put the ammeter across the battery, and never substitute a Qwiic cable for the battery pigtail.

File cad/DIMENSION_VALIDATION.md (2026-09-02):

# Physical dimension validation

Record caliper measurements in millimeters. Update `design_parameters.json`, rerun the generator, and preserve the original measurement record.

## CuePod

- [ ] XIAO main board length, width, and PCB thickness.
- [ ] Sense expansion board length, width, assembled height, microphone center, and any removable camera interference.
- [ ] USB-C plug shell and common cable overmold insertion envelope.
- [ ] Battery pouch length, width, thickness at center and protection end, taped cable exit, bend radius, and connector orientation.
- [ ] Clearance between microphone face and inner acoustic wall.
- [ ] Pigtail/connector strain-relief route with no pressure on cell pouch.
- [ ] Standoff positions do not contact components or antenna keepout.
- [ ] Elevated XIAO bridge clears the cell, supports the board without component contact, and leaves the declared 0.35 mm XIAO-to-microphone keepout in the measured stack.
- [ ] Lid closes without compressing the battery.

## Receiver

- [ ] UNO Q PCB length/width and maximum component/header/connector height.
- [ ] Mount-hole center coordinates and usable screw diameter.
- [ ] USB-C insertion/removal envelope and hub/power-cable overmolds.
- [ ] Wi-Fi antenna, LED matrix, status LED, user-button, Qwiic, and ventilation keepouts.
- [ ] Any selected haptic, diffuser/LED, buzzer, and accessory dimensions.
- [ ] Stand angle remains stable under cable load and button force.
- [ ] Clip gap/force works on the intended belt, pocket, and bag strap without sharp stress risers.
- [ ] Dock retains the pod under a carry/drop test without damaging connectors.

## Print/DFM coupon

- [ ] Measure 0.25/0.35/0.45/0.55 mm mating gaps in the chosen PCBWay process.
- [ ] Measure M2 clearance holes, boss pilot holes, and insert pockets.
- [ ] Check minimum readable embossed/debossed privacy and orientation marks.
- [ ] Inspect wall warp, diffuser fit, microphone openings, unsupported spans, and surface finish.

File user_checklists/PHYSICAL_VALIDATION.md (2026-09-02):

# CueLoop physical validation matrix

Run only completed rows; leave the rest pending. Root `HARDWARE_TESTS.md` is the authoritative complete method and execution log; this file is the compact matrix. Every result must identify Git commit, firmware/App Lab versions, board revisions, date/timezone, operator, power mode, network conditions, evidence tier, units, and artifact path. Targets are predeclared goals, not results.

## Gate 1 — deterministic bring-up

| ID | Test | Method | Target / expected observation | Current evidence |
|---|---|---|---|---|
| P-001 | XIAO USB flash/boot | Windows source upload, 115200 serial | Ready banner, mic-ready banner, no reset loop | Pending physical |
| P-002 | Test-tone framing | `TEST ON`; record two `STATUS` samples | 50 captured/s nominal; RMS/peak ≈8192; clipped=0 | Pending physical |
| P-003 | Wi-Fi/receiver ACK | Configure private LAN + UNO Q IP | sent and valid ACK counters increase; reachable=yes | Pending physical |
| P-004 | Receiver loss/recovery | Stop App for ≥7 s, then restart | timeout once; reachability false then true; stream restart observed | Pending physical |
| P-005 | App/Bridge health | Deploy exact App Lab package | LED4 red while unhealthy, green after heartbeat; dashboard cue output connected | Pending physical |
| P-006 | Cue language | Trigger one confirmed test path per class through controlled replay/test harness | LED3 class color and priority cadence match firmware; clear/mute immediate | Pending physical |
| P-007 | Dashboard controls | Keyboard and pointer acknowledge/dismiss/mute | metadata changes; MCU clears/mutes; LED4 blue while muted | Pending physical |
| P-008 | Optional D4 button | Only if S1 is actually installed; press/release 20 times | exactly one ack per press, no idle phantom ack | Pending inventory/physical |
| P-009 | MCU restart recovery | Restart/redeploy sketch during mute and active pending cue | restart count rises; Linux restores mute/current pending cue | Pending physical |
| P-010 | Privacy file audit | Before/after 15-min run, list App `data/` and inspect DB schema | only bounded metadata/feedback database; no audio files | Pending physical |

Do not continue to battery or claims testing until P-001 through P-005 pass.

## Gate 2 — microphone and network characterization

For each test capture serial/dashboard counters before and after. Use gentle, consented sources; never strike the board or use a real emergency alarm at unsafe volume.

| ID | Condition | Repetitions/duration | Measurements |
|---|---|---:|---|
| P-101 | Quiet room, microphone mode | 5 min | audio RMS/peak range, clipped samples, capture errors, packet loss, RSSI |
| P-102 | Controlled event at 0.5 m line-of-sight | 10/class | detections, misses, confidence, latency |
| P-103 | Same event at 1 m and 3 m | 10/class/distance | recall/confidence vs distance |
| P-104 | CuePod behind one closed interior door | 10/class | recall/confidence/latency/loss |
| P-105 | Background speech/TV/music/fan | 15 min each | false alerts/hour by condition and class |
| P-106 | Confusable nontarget knocks/beeps/shouts | ≥10/type | suppression/confirmation behavior and false alerts |
| P-107 | LAN distance path used in video | 15 min | packet loss, duplicates/late, jitter, RSSI, disconnects |
| P-108 | 5% and 20% artificial packet loss replay | fixed licensed clips, same seed | understandable demo at 5%; diagnostics accurate at 20% |

P-108 is a target-integrated controlled fault test but remains “simulated loss” unless the loss occurs in a documented physical network impairment. Do not relabel it physical RF performance.

## Gate 3 — model evidence

Use owned or permissively licensed PCM16 mono WAV files and a complete ignored manifest. Obtain consent for any identifiable recording. Keep calibration, validation, and held-out test splits separate.

1. Aim for at least 30 positive test examples per retained class across multiple sources/rooms and at least one hour total defined background audio. If the deadline forces a smaller set, publish the actual count and wide uncertainty—not the target.
2. Tune only on calibration, choose policies on validation once, and publish the held-out test output from `models/evaluate.py`.
3. Report per-class precision, recall, F1, support, confusion matrix, missed-event rate, false alerts/audio-hour, Brier/calibration error, model inference latency, and temporal-confirmation comparison.
4. Retain a class for the polished demo only if held-out precision ≥0.80 and recall ≥0.75 **or** clearly disclose that the target was missed and narrow the claim/demo.
5. The quiet/background target is fewer than 1 false alert/hour on the explicitly defined mix. Never extrapolate beyond it.

The checked-in evaluator accepts one onset/end interval per labeled class and reports onset-to-first-temporally-qualifying-window latency plus explicit temporal-versus-single-window metrics. This remains an audio-file decision metric, not full CuePod-to-physical-cue latency; use synchronized H-302 measurement for the latter.

## Gate 4 — latency and resilience

| ID | Measurement | Method | Goal |
|---|---|---|---|
| P-201 | Warm model inference | ≥100 UNO Q invocations after 10 warmups | report mean/median/p95/max and memory; no fixed pass gate until observed |
| P-202 | End-to-end alert latency | 20 events; 60/120 fps video showing source action and LED3 or synchronized electronic marker | median ≤2.5 s, p95 ≤4.0 s |
| P-203 | App restart | 10 restarts | receiver/dashboard recover without DB repair or audio files |
| P-204 | Wi-Fi interruption | 10 AP/client interruptions | bounded reconnect, no reboot required, counters explain gaps |
| P-205 | Bridge interruption/MCU reset | 10 trials | Linux remains alive; visible degraded health; state resynchronizes |
| P-206 | 30-minute soak | physical microphone + normal LAN | no crash/unbounded growth; capture and packet counters plausible |

Video-frame latency includes uncertainty of ±1 frame plus ambiguity in source onset; record frame rate and exact frame indices. Dashboard `pipeline_latency_ms` is processing delay after a complete window, not full acoustic-to-human latency.
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

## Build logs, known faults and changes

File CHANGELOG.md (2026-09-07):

# Changelog

All notable changes are recorded here. This project uses semantic versioning once the first integrated release is tagged.

## Unreleased

### Added

- Authoritative competition project brief.
- Safe ignore policy for secrets, private audio, datasets, models, build products, local databases, and generated CAD/media.
- Project control, requirements, architecture, privacy, safety, and official-requirements documentation.
- Submission-ready Autodesk application copy apart from account URL and truthful entrant biography.
- Production-intent native Autodesk Fusion API generator with 125 named parameters, constrained sketches, native features/components/history, six manufacturing components, six explicit reference envelopes, exploded placement, and F3D/STEP/STL/3MF/BOM/source-provenance exports.
- Independent FreeCAD/OpenCascade reference generator with committed editable FCStd and assembly/per-part STEP/STL files, STEP-reopen validation, exact-bounds checks, 12 zero-volume interference checks, and SHA-256 manifests.
- Dependency-free CAD source/output validator, PCBWay DFM gates, complete design provenance, and exact Windows Fusion native-history/visual-review/render/return runbook.
- Parametric CAD dimension/physical-validation checklist and provenance-labeled cover concept.
- CueLoop Protocol v1, bounded receiver/windowing, simulated CuePod with fault injection, temporal confirmation engine, metadata-only storage, local REST API, accessible dashboard, and one-command demo.
- Automated tests for protocol integrity, loss/reordering/restart, buffer bounds, simulated signatures, uncertainty policy, privacy, API controls, and end-to-end event generation.
- Checksum-pinned optional YAMNet LiteRT v1 adapter with explicit service selection, exact class mappings, a size/digest-verifying fetcher, and pinned inference dependencies.
- Provenance-gated evaluation manifests and dataset-scoped precision, recall, false-trigger, missed-event, calibration, and latency reporting.
- Honestly bounded development-computer latency baseline on a synthetic workload; no accuracy or UNO Q claim is attached.
- XIAO ESP32S3 Sense CuePod firmware with PDM capture, memory-only length-framed TCP streaming, serial/NVS configuration, bounded reconnect, test tone, receiver heartbeat, and diagnostics.
- UNO Q STM32 cue-controller firmware with compact Bridge RPCs, deterministic LED/optional actuator patterns, health indication, and acknowledgement input.
- Receiver ACK extension to CueLoop Protocol v1 and matching strict Python/C++ validation.
- Fault-contained Linux Bridge adapter with diagnostics and MCU-restart cue resynchronization.
- Official App Lab package structure, pinned Python/sketch dependencies, checksum-enforced source/model synchronizer, commit-bound clean-tree release archives, and package integrity tests.
- Clean-intermediate, fixed-epoch, checkout-path-normalized firmware builder with byte-identical cross-checkout XIAO images and canonical/App-profile UNO Q containers.
- Objective CuePod per-frame RMS, peak, and cumulative clipping diagnostics for physical microphone bring-up.
- Complete minimum/optional/V2 BOM, machine-readable netlist, accessible SVG schematic, wiring/pin tables, power and bandwidth analysis, and battery-safe assembly guide.
- Windows App Lab/XIAO deployment instructions and a predeclared physical validation matrix with evidence gates.
- Deterministic App Lab ZIP packager that verifies model/source drift and rejects private/runtime artifacts.
- Complete App Lab submission copy: metadata, full project article, source/reproduction map, troubleshooting, primary and short video scripts, photo plan, evidence table, attribution ledger, final checklist, and rubric review.
- Deterministic exact-commit source ZIP packager with per-file checksums and guards against secrets, raw audio, downloaded models, databases, and build artifacts.
- Automated release tests for required submission material, video disclosure/timeline, and repeatable sanitized source archives.
- Automated native Fusion/source-provenance/reference-solid/output and Autodesk-application completeness checks, plus one deadline-ordered physical/account handoff sheet.
- Authoritative root `HARDWARE_TESTS.md` combining Windows deployment, battery-safe bring-up, quantitative physical gates, expected observations, and append-only records.
- Evaluation result schema v2 with explicit confusion matrices/support, condition slices, event-interval decision latency, and temporal-versus-single-window comparison.
- Deterministic 60-trial simulated transport fault benchmark, curated evidence summary, and claim-boundary tests.
- Predeclared experiment registry/schema and complete Autodesk final-package structure for V2 development, DFM, evidence, article, and submission review.
- Requirement-by-requirement `PROJECT_PROMPT` completion audit and automated structural/safety checks.
- Release-grade fresh-checkout verifier covering the pinned model, tests, minimum-Python static analysis, all Arduino builds, and deterministic App/source archives.
- Hash-locked CPython 3.13/Linux ARM64 inference dependency audit with exact wheel sizes/digests, LiteRT metadata/license/dependency checks, AArch64 ELF validation, synchronized App evidence, and target runtime identity logging.

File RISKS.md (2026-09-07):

# Risk register

| ID | Risk | Likelihood / impact | Early signal | Mitigation and fallback | Status |
|---|---|---|---|---|---|
| R-001 | Hardware arrives too late for full validation. | High / critical | No delivery or inventory by Sept. 5. | Finish all simulator/software/docs first; prepare exact bring-up checklists; use recorded replay only as a clearly labeled fallback. | Open |
| R-002 | Broad pretrained audio model performs poorly on selected real events. | High / high | Weak precision/recall or calibration in licensed desktop evaluation. | Limit vocabulary, tune class mappings/thresholds, temporal confirmation, and demonstrate one excellent repeatable scenario. | Open |
| R-003 | TCP retransmission, reconnects, or Wi-Fi contention create audio gaps or high latency. | Medium / high | Sequence gaps, connection churn, underflows, or p95 latency above target. | 20 ms framed packets, bounded connection/write timeouts, reconnect backoff, sequence-gap handling, health metrics; consider compression only after measurements. | Open |
| R-004 | XIAO microphone or ESP32 core API differs from documentation. | Medium / high | Constant samples, compile failure, or distorted capture. | Pin Arduino-ESP32 3.x, use `ESP_I2S` PDM pins GPIO42/GPIO41, retain official 2.x alternative notes, and run mic smoke test first. | Open |
| R-005 | Battery pigtail polarity is reversed relative to board/cell expectations. | Medium / critical | Red/black or connector polarity mismatch. | Never connect by color alone; require disconnected continuity/polarity checks with multimeter; no battery during soldering. | Open |
| R-006 | 500 mAh runtime is inadequate under continuous Wi-Fi/audio. | Medium / medium | Measured current implies short demo runtime or voltage sag. | USB development mode, duty-cycle experiments, lower Wi-Fi power only after reliability; V2 battery redesign. | Open |
| R-007 | App Lab/Bridge versions change or are unstable. | Medium / high | Official examples or app manifest fail on installed version. | Pin/document tested versions, keep standalone core, use thin App Lab adapter, preserve Arduino CLI MCU build path. | Open |
| R-008 | Autodesk rules page placeholders cause ambiguous eligibility. | High / medium | Official rules retain generic template fields. | Follow specific overview and organizer guide; save checked URLs/dates; include UNO Q, Fusion `.f3d`, BOM, PCBWay plan, project story, and all application questions. | Mitigated |
| R-009 | Two contest entries appear identical or reuse a winning entry. | Medium / critical | Shared story/CAD/interactions dominate V2. | Separate names, stories, CAD, interactions, portability, manufacturing, testing, and shared-work ledger; never submit an already-winning identical entry. | Open |
| R-010 | Private/copyrighted audio or third-party assets enter the submission. | Medium / critical | Missing provenance or accidental recording in Git. | Ignore recordings/datasets; use manifests and owned/compatible assets; deterministic package guards; per-file manifests; owned/compatible media ledger and final inspection. | Mitigated digitally; final media audit pending |
| R-011 | Dashboard looks polished but is not immediately legible on video. | Medium / medium | Small text, poor contrast, unclear active event. | High-contrast accessible tokens, dominant cue card, responsive layout, mock video capture review. | Open |
| R-012 | CAD dimensions do not match shipped parts. | High / high | Enclosure interference on first fit. | Central parameter table, conservative clearance, serviceable fasteners, and physical dimension validation before manufacturing. | Open |
| R-013 | Product is mistaken for a certified smoke/baby/security monitor. | Medium / critical | Copy implies guaranteed detection. | Persistent awareness-aid limitation in UI, docs, narration, and submissions; test but do not guarantee safety classes. | Mitigated |
| R-014 | Private GitHub link is inaccessible to judges. | Medium / high | Hackster preview logged out cannot open source. | Attach the deterministic sanitized source archive and optionally publish a release repository; verify every link/download from a logged-out browser. | Mitigated digitally; account check pending |
| R-015 | XIAO battery telemetry or charge assumptions are wrong for the received revision. | Medium / high | Reported voltage is absent, meter disagrees, or official charge-current table does not map cleanly to the revision. | Default `BATTERY_VALID` off; publish no charge-time claim; enable an ignored local hardware override only after schematic/revision and multi-point meter validation. | Mitigated in firmware/docs; physical validation pending |
| R-016 | Trusted-LAN TCP/dashboard traffic is observed or modified by another LAN client. | Medium / high | Deployment requires guest/public Wi-Fi or an untrusted shared network. | No cloud, explicit limitation, isolated/trusted demo LAN, no credentials in packets; V2 must add authenticated/encrypted transport before hostile-network use. | Open; accepted V1 limitation |
| R-017 | Clip-level evaluation or synthetic loss is mistaken for event-stream, RF, or end-to-end physical performance. | Medium / high | A metric is quoted without interval method, condition slice, injector/receiver distinction, or evidence tier. | Evaluation schema v2 separates inference/audio-decision latency and single/temporal policy; benchmark claim boundary is explicit; full target/network/cue methods remain H-100–H-302 in `HARDWARE_TESTS.md`. | Mitigated digitally; physical evidence pending |
| R-018 | The statically reviewed Fusion API generator exposes a current-runtime or kernel-specific failure on Windows Fusion. | Medium / high | Script traceback, failed join/cut/export, count below contract, invalid body, or visual/interference defect during C-100. | Current Autodesk APIs only; no retired extent/import path; preflight parameter math; independently generated/reopened OpenCascade solids; exact source snapshots/hashes; fail-closed count/output checks; preserve the failure and revise source rather than hand-editing the result. | Mitigated digitally; Windows Fusion execution pending |
| R-019 | Firmware hashes appear to drift across clean checkouts even when source and tool versions match. | Medium / medium | XIAO image differs only in compile-time strings, embedded ELF digest, or final image digest. | Use `scripts/build_firmware.sh`: clean intermediates, fixed project epoch, root prefix maps, identical relative paths, and canonical/App-profile comparisons; treat ad-hoc compile hashes as non-release evidence. | Mitigated and reproduced across two local checkouts |
| R-020 | The received UNO Q App Lab image cannot resolve or dynamically load the pinned LiteRT runtime despite compatible published ARM64 wheels. | Medium / high | Resolver failure, runtime identity outside the audited Python 3.13/Linux ARM64 tuple, native import traceback, or model startup failure. | Exact-version/hash-lock all eight target wheels; verify metadata/archive/native AArch64 ELF identity on Ubuntu; print Python/machine/libc/package identity before model load; preserve W-104–W-106 logs and make any runtime change an evidence-backed decision. | Distribution risk mitigated; target loader/inference pending |

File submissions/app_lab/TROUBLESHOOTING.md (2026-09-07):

# CueLoop troubleshooting

Diagnose from the outside inward: power/USB, board baseline, App Lab, model, Bridge, LAN, CuePod transport, microphone, then policy. Preserve error text and counters before erasing or reflashing anything. Never paste passwords into a bug report.

## UNO Q is absent from App Lab

1. Confirm Windows 10/11 64-bit and current official App Lab.
2. Confirm the cable carries data and the board is powered using the mode documented for the actual Arduino-order USB-C path/hub.
3. Run the built-in Blink baseline before CueLoop.
4. For network mode, put Windows and UNO Q on the same client-visible LAN, disable VPN temporarily if policy permits, and allow private-network mDNS/UDP 5353 when Windows prompts for `mdns-discovery.exe`.
5. Guest/corporate/IoT Wi-Fi may isolate clients even when browser/SSH access works. Move to a private test LAN rather than weakening a public firewall.
6. Use official App Lab Settings/connection diagnostics. Reflash the Linux OS only for a diagnosed corrupt/unresponsive image, with a backup/erase decision recorded.

## App Lab import rejects the archive

- Verify ZIP SHA-256 against its `.sha256` sidecar.
- Confirm the archive has one top-level `CueLoop/` folder containing `app.yaml`, `python/main.py`, and `sketch/sketch.ino` plus `sketch/sketch.yaml`.
- If the installed App Lab Import dialog requests a folder rather than ZIP, extract once and select the top-level `CueLoop` folder.
- Rebuild with `python3 scripts/package_app_lab.py --version 0.1.0`; do not hand-edit the vendor copy.
- Record App Lab version and full message. App format changes are a versioned packaging issue, not a reason to remove mandatory files.

## Python requirement or model startup fails

| Message/symptom | Meaning | Correct action |
|---|---|---|
| model not found | `.tflite` absent from App `models/` | rebuild transfer archive with `--include-model` |
| SHA-256 mismatch | model modified, truncated, or wrong release | remove only that known artifact, re-fetch through the verifier, rebuild archive |
| unexpected input/output tensor | incompatible model/runtime | retain error; compare pinned model/runtime; do not bypass validation |
| cannot install `ai-edge-litert==2.2.0` | target Python/aarch64 resolver mismatch or unavailable network | record Python/OS/architecture/resolver output; evaluate a supported pinned runtime as a material decision |
| `CueLoop runtime` differs from Python 3.13, ARM64/AArch64, or LiteRT 2.2.0 | received App Lab image differs from the audited distribution tuple | retain the full identity line and App Lab/image versions; do not force-install or relabel the audit as a target pass |
| package installs but native import fails | libc/libstdc++/loader or image mismatch not covered by wheel-tag inspection | retain traceback and identity line; diagnose against the exact image before changing pins |
| process exits instead of showing synthetic events | expected fail-closed behavior | fix the physical model path; never enable a synthetic fallback for a physical claim |

## Dashboard does not load

- Confirm App console printed the port 8080 startup line and did not exit on model/database/socket error.
- Use `http://<UNO-Q-IP>:8080/`, not localhost on the Windows laptop.
- Confirm `app.yaml` declares port 8080 and the LAN/firewall permits local TCP 8080.
- Try the status endpoint directly: `http://<UNO-Q-IP>:8080/api/status`.
- Port conflict: stop the other user app or change CueLoop's descriptor and constant together; do not expose the port through a public router.

## LED4 remains blinking red

This means Bridge is unavailable or the Linux heartbeat is stale.

1. Check App Lab monitor for sketch compilation/flash success and Python Bridge registration/call errors.
2. Confirm the imported sketch is the synchronized CueLoop sketch and `Arduino_RouterBridge` versions match `sketch.yaml`.
3. Wait one heartbeat period, then inspect `/api/status` → `cue_output` calls/failures/last error.
4. Restart the CueLoop App once, not unrelated processes. Run official Blink again if the MCU baseline is uncertain.
5. Record MCU/App restarts and status. Do not hide the red fault state in firmware.

## CuePod has no COM port or upload fails

- Use a data-capable USB-C cable and compare Device Manager before/after reconnecting.
- Keep LiPo detached during flashing.
- Select `XIAO_ESP32S3` with Espressif core 3.3.11.
- Enter Seeed's documented bootloader mode: hold BOOT while connecting USB and release after connection; or hold BOOT and tap RESET.
- Try a known Blink example. If Blink fails, CueLoop is not yet the problem.
- Do not flash the application `.bin` at a guessed address. Compile/upload from source or use an exact complete artifact directory/tool invocation.

## CuePod reports `WIFI_NOT_CONFIGURED` or never connects

- `SET_WIFI` arguments require actual Tab characters and LF. SSID is limited to 32 bytes and password to 64.
- XIAO supports 2.4 GHz Wi-Fi; ensure the SSID makes 2.4 GHz available.
- Re-enter the credential through serial; the password is never printed. Do not add it to a header.
- `wifi_attempts` should rise with bounded backoff. If it does, check SSID/security/signal without logging the password.
- `ERASE` deletes all CuePod NVS configuration and reboots. Use it only when intentionally reprovisioning, then enter every setting again.

## Wi-Fi connects, but `reachable=no`

1. Verify UNO Q's current IPv4 address and send `SET_RECEIVER<TAB>address<TAB>57321`.
2. Confirm CueLoop App is running and `app.yaml` declares TCP 57321 as well as 8080.
3. Confirm client isolation/firewall policy permits client-to-client TCP 57321. Internet access alone does not prove local reachability.
4. Inspect `receiver_connect_attempts`, `receiver_reconnects`, `sent`, `send_failures`, `valid_acks`, `bad_acks`, `receiver_timeouts`, and RSSI.
5. A valid ACK must return on the configured receiver connection with matching pod ID and CRC. Do not accept arbitrary data to make the indicator green.

## Dashboard says disconnected while valid ACKs rise

- The ACK says the receiver socket is alive; dashboard connection requires recently accepted audio frames.
- Confirm `STREAM ON`, sample/frame format, destination port, and increasing frames-received.
- A packet can pass CRC but still be rejected for unsupported sample/frame size; compare Protocol v1 constants.
- Check dashboard diagnostics for bad packets, format mismatches, gaps, and last error.

## Microphone values are zero, constant, or clipped

1. Switch `TEST ON`. Expected RMS/peak ≈8192 and clipping zero. If that fails, diagnose firmware timing/build first.
2. Switch `TEST OFF`. Quiet-room RMS/peak should vary; exact values require the received hardware and room. Rising `capture_errors` suggests I2S/expansion trouble.
3. Confirm Sense expansion seating and exact board revision. Firmware uses Seeed's current `ESP_I2S` PDM RX path with clock GPIO42 and data GPIO41.
4. Do not tap/strike the MEMS microphone or use a loud alarm to force movement. Stop and record persistent near-32768 peaks/clipping.
5. Variable samples prove capture activity, not class accuracy. Use the licensed held-out evaluation path.

## Packets arrive but no event alerts

- Check input-mode labeling. Test tone was designed for transport and the synthetic classifier, not for YAMNet accuracy.
- Confirm class is enabled, scores cross observe/alert thresholds, at least two evidence windows occur inside the confirmation interval, mute is expired, and cooldown has ended.
- Inspect background/unknown and model identity. Do not lower thresholds based on one anecdote or test split.
- Evaluate real licensed/self-recorded clips on calibration/validation splits, then publish held-out results. Drop unreliable classes.

## Too many false alerts

- Record the environment, class, score, temporal evidence, and event action without saving private audio by default.
- Confirm generic speech is not mapped to attention call.
- Reproduce with consented/provenance-complete audio. Tune on calibration only, validate once, keep test held out.
- Increase class threshold/hits, shorten evidence lifetime, lengthen cooldown, disable the class, or narrow mapping. Report the changed policy and comparison.
- Never market a false-alert reduction from simulator signatures as physical performance.

## Battery/charge behavior is unexpected

Disconnect power and stop for heat, odor, swelling, puncture, reverse polarity, damaged insulation, resets, or unstable voltage. Do not troubleshoot a cell with soldering, loose probes, or an ammeter across it. Return to `hardware/ASSEMBLY.md`; record PCB/cell markings and measured connector orientation. The default firmware intentionally reports battery voltage unavailable because no verified divider is assigned.

## Database/history issue

The App stores at most 500 event rows plus linked feedback and no audio. Use the dashboard's confirmed clear action for normal reset. If the database is corrupt, stop the App, preserve a copy only if it contains no sensitive metadata you cannot retain, then remove the specifically identified App `data/cueloop.sqlite3` through App Lab/file management. Do not delete broad directories. Restart and confirm schema recreation.

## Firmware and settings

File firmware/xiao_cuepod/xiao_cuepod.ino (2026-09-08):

// CueLoop CuePod firmware for Seeed Studio XIAO ESP32S3 Sense.
// Raw microphone samples are packetized in RAM and never written to storage.

#include <Arduino.h>
#include <errno.h>
#include <ESP_I2S.h>
#include <Preferences.h>
#include <WiFi.h>
#include <lwip/sockets.h>

#include "cuepod_hardware.h"
#include "cuepod_protocol.h"

namespace {

constexpr uint16_t kDefaultReceiverPort = 57321;
constexpr uint32_t kFrameDurationUs = 20000;
constexpr uint32_t kReceiverTimeoutMs = 5000;
constexpr uint32_t kDiagnosticsIntervalMs = 5000;
constexpr uint32_t kMinimumWifiRetryMs = 1000;
constexpr uint32_t kMaximumWifiRetryMs = 30000;
constexpr uint32_t kMinimumReceiverRetryMs = 500;
constexpr uint32_t kMaximumReceiverRetryMs = 5000;
constexpr int32_t kReceiverConnectTimeoutMs = 250;
constexpr uint32_t kTcpWriteTimeoutMs = 250;
constexpr size_t kStreamPrefixBytes = 2;
constexpr size_t kAckFrameBytes = kStreamPrefixBytes + cueloop::kAckBytes;
constexpr size_t kMaximumSerialCommand = 196;
constexpr int32_t kMicrophoneGain = 4;

struct Counters {
  uint32_t captured_frames = 0;
  uint32_t sent_frames = 0;
  uint32_t send_failures = 0;
  uint32_t capture_errors = 0;
  uint32_t wifi_attempts = 0;
  uint32_t wifi_reconnects = 0;
  uint32_t receiver_connect_attempts = 0;
  uint32_t receiver_reconnects = 0;
  uint32_t valid_acks = 0;
  uint32_t bad_acks = 0;
  uint32_t receiver_timeouts = 0;
  uint32_t clipped_samples = 0;
};

Preferences preferences;
I2SClass i2s;
WiFiClient receiver_client;
Counters counters;
String wifi_ssid;
String wifi_password;
IPAddress receiver_ip(192, 168, 1, 2);
uint16_t receiver_port = kDefaultReceiverPort;
uint32_t pod_id = 1;
bool usb_powered_mode = true;
bool streaming_enabled = true;
bool test_tone_enabled = false;
bool microphone_ready = false;
bool receiver_connection_active = false;
bool had_receiver_connection = false;
bool receiver_reachable = false;
bool receiver_timeout_reported = false;
bool was_wifi_connected = false;
uint8_t restart_frames_remaining = 3;
uint32_t sequence_number = 0;
uint64_t sample_clock = 0;
uint32_t last_wifi_attempt_ms = 0;
uint32_t wifi_retry_ms = kMinimumWifiRetryMs;
uint32_t last_receiver_attempt_ms = 0;
uint32_t receiver_retry_ms = kMinimumReceiverRetryMs;
uint32_t last_ack_ms = 0;
uint32_t last_diagnostics_ms = 0;
uint32_t next_test_frame_us = 0;
uint16_t last_audio_rms = 0;
uint16_t last_audio_peak = 0;
String serial_line;
int16_t samples[cueloop::kSamplesPerFrame];
uint8_t datagram[cueloop::kDatagramBytes];
uint8_t ack_frame[kAckFrameBytes];
size_t ack_frame_used = 0;

uint32_t defaultPodId() {
  const uint64_t efuse = ESP.getEfuseMac();
  uint32_t folded = static_cast<uint32_t>(efuse) ^ static_cast<uint32_t>(efuse >> 32);
  folded ^= 0xC0E10000u;
  return folded == 0 ? 1 : folded;
}

void beginNewStream() {
  sequence_number = 0;
  sample_clock = 0;
  restart_frames_remaining = 3;
}

void closeReceiverConnection(bool announce) {
  if (receiver_connection_active && announce) {
    Serial.println("RECEIVER_DISCONNECTED");
  }
  receiver_client.stop();
  receiver_connection_active = false;
  receiver_reachable = false;
  ack_frame_used = 0;
  beginNewStream();
}

void loadConfiguration() {
  preferences.begin("cueloop", false);
  wifi_ssid = preferences.getString("ssid", "");
  wifi_password = preferences.getString("password", "");
  String ip_text = preferences.getString("receiver_ip", "192.168.1.2");
  if (!receiver_ip.fromString(ip_text)) {
    receiver_ip.fromString("192.168.1.2");
  }
  receiver_port = preferences.getUShort("receiver_port", kDefaultReceiverPort);
  if (receiver_port == 0) {
    receiver_port = kDefaultReceiverPort;
  }
  pod_id = preferences.getULong("pod_id", defaultPodId());
  if (pod_id == 0) {
    pod_id = defaultPodId();
  }
  usb_powered_mode = preferences.getBool("usb_mode", true);
  streaming_enabled = preferences.getBool("streaming", true);
  test_tone_enabled = preferences.getBool("test_tone", false);
}

void startWifiAttempt() {
  if (wifi_ssid.isEmpty()) {
    return;
  }
  closeReceiverConnection(false);
  WiFi.disconnect();
  WiFi.mode(WIFI_STA);
  WiFi.setSleep(false);
  WiFi.begin(wifi_ssid.c_str(), wifi_password.c_str());
  last_wifi_attempt_ms = millis();
  counters.wifi_attempts++;
}

void onWifiConnected() {
  wifi_retry_ms = kMinimumWifiRetryMs;
  receiver_retry_ms = kMinimumReceiverRetryMs;
  last_receiver_attempt_ms = millis() - receiver_retry_ms;
  last_ack_ms = millis();
  receiver_reachable = false;
  receiver_timeout_reported = false;
  beginNewStream();
  if (was_wifi_connected) {
    counters.wifi_reconnects++;
  }
  was_wifi_connected = true;
  Serial.print("WIFI_CONNECTED ip=");
  Serial.println(WiFi.localIP());
}

void maintainWifi() {
  static wl_status_t previous_status = WL_NO_SHIELD;
  const wl_status_t status = WiFi.status();
  if (status == WL_CONNECTED) {
    if (previous_status != WL_CONNECTED) {
      onWifiConnected();
    }
  } else {
    if (previous_status == WL_CONNECTED) {
      closeReceiverConnection(false);
      Serial.println("WIFI_DISCONNECTED");
    }
    const uint32_t now = millis();
    if (!wifi_ssid.isEmpty() && now - last_wifi_attempt_ms >= wifi_retry_ms) {
      startWifiAttempt();
      wifi_retry_ms = min(kMaximumWifiRetryMs, wifi_retry_ms * 2u);
    }
  }
  previous_status = status;
}

void maintainReceiverConnection() {
  if (!streaming_enabled || WiFi.status() != WL_CONNECTED) {
    return;
  }
  if (receiver_connection_active && receiver_client.connected()) {
    return;
  }
  if (receiver_connection_active) {
    closeReceiverConnection(true);
  }
  const uint32_t now = millis();
  if (now - last_receiver_attempt_ms < receiver_retry_ms) {
    return;
  }
  last_receiver_attempt_ms = now;
  counters.receiver_connect_attempts++;
  receiver_client.stop();
  if (receiver_client.connect(
          receiver_ip, receiver_port, kReceiverConnectTimeoutMs) == 1) {
    receiver_client.setNoDelay(true);
    receiver_connection_active = true;
    receiver_reachable = false;
    receiver_timeout_reported = false;
    ack_frame_used = 0;
    last_ack_ms = now;
    receiver_retry_ms = kMinimumReceiverRetryMs;
    beginNewStream();
    if (had_receiver_connection) {
      counters.receiver_reconnects++;
    }
    had_receiver_connection = true;
    Serial.println("RECEIVER_CONNECTED transport=tcp");
  } else {
    receiver_retry_ms = min(kMaximumReceiverRetryMs, receiver_retry_ms * 2u);
  }
}

uint16_t readBatteryMillivolts() {
#if CUELOOP_BATTERY_ADC_PIN >= 0
  uint32_t sum_mv = 0;
  for (uint8_t index = 0; index < 8; ++index) {
    sum_mv += analogReadMilliVolts(CUELOOP_BATTERY_ADC_PIN);
    delay(2);
  }
  const uint32_t pin_mv = sum_mv / 8;
  const uint32_t battery_mv =
      pin_mv * CUELOOP_BATTERY_SCALE_NUMERATOR / CUELOOP_BATTERY_SCALE_DENOMINATOR;
  return static_cast<uint16_t>(min<uint32_t>(battery_mv, 65535));
#else
  return 0;
#endif
}

void fillTestTone() {
  // 1 kHz transport tone. It validates capture framing/transport only and is
  // not designed to imitate any real CueLoop event class.
  for (uint16_t index = 0; index < cueloop::kSamplesPerFrame; ++index) {
    const uint64_t absolute_sample = sample_clock + index;
    const uint16_t phase = absolute_sample % 16;
    samples[index] = phase < 8 ? 8192 : -8192;
  }
}

void updateAudioDiagnostics() {
  uint64_t sum_squares = 0;
  uint32_t peak = 0;
  for (uint16_t index = 0; index < cueloop::kSamplesPerFrame; ++index) {
    const int32_t value = samples[index];
    const uint32_t magnitude = static_cast<uint32_t>(value < 0 ? -value : value);
    peak = max(peak, magnitude);
    sum_squares += static_cast<uint64_t>(magnitude) * magnitude;
    if (magnitude >= 32760) {
      counters.clipped_samples++;
    }
  }
  last_audio_peak = static_cast<uint16_t>(min<uint32_t>(peak, 32768));
  last_audio_rms = static_cast<uint16_t>(sqrt(
      static_cast<double>(sum_squares) / cueloop::kSamplesPerFrame));
}

void applyMicrophoneGain() {
  // The Sense PDM microphone has modest raw output. Apply fixed gain before
  // transport while saturating cleanly instead of allowing signed wraparound.
  for (uint16_t index = 0; index < cueloop::kSamplesPerFrame; ++index) {
    int32_t amplified = static_cast<int32_t>(samples[index]) * kMicrophoneGain;
    if (amplified > 32767) {
      amplified = 32767;
    } else if (amplified < -32768) {
      amplified = -32768;
    }
    samples[index] = static_cast<int16_t>(amplified);
  }
}

bool captureFrame() {
  if (test_tone_enabled) {
    const uint32_t now_us = micros();
    if (static_cast<int32_t>(now_us - next_test_frame_us) < 0) {
      return false;
    }
    if (now_us - next_test_frame_us > kFrameDurationUs * 4u) {
      next_test_frame_us = now_us;
    }
    next_test_frame_us += kFrameDurationUs;
    fillTestTone();
    updateAudioDiagnostics();
    counters.captured_frames++;
    return true;
  }
  if (!microphone_ready) {
    delay(10);
    return false;
  }
  const size_t bytes_read =
      i2s.readBytes(reinterpret_cast<char*>(samples), sizeof(samples));
  if (bytes_read != sizeof(samples)) {
    counters.capture_errors++;
    return false;
  }
  applyMicrophoneGain();
  updateAudioDiagnostics();
  counters.captured_frames++;
  return true;
}

uint16_t packetFlags(uint16_t battery_mv) {
  uint16_t flags = 0;
  if (test_tone_enabled) {
    flags |= cueloop::kFlagTestTone;
  }
  if (usb_powered_mode) {
    flags |= cueloop::kFlagUsbPowered;
  }
  if (battery_mv > 0) {
    flags |= cueloop::kFlagBatteryValid;
  }
  if (restart_frames_remaining > 0) {
    flags |= cueloop::kFlagStreamRestart;
  }
  return flags;
}

void buildDatagram(uint16_t battery_mv) {
  memcpy(datagram, cueloop::kMagic, sizeof(cueloop::kMagic));
  datagram[4] = cueloop::kVersion;
  datagram[5] = cueloop::kAudioPcm16;
  cueloop::putBe16(datagram + 6, packetFlags(battery_mv));
  cueloop::putBe32(datagram + 8, pod_id);
  cueloop::putBe32(datagram + 12, sequence_number);
  cueloop::putBe64(datagram + 16, sample_clock);
  cueloop::putBe32(datagram + 24, millis());
  cueloop::putBe16(datagram + 28, cueloop::kSampleRateHz);
  cueloop::putBe16(datagram + 30, cueloop::kSamplesPerFrame);
  cueloop::putBe16(datagram + 32, battery_mv);
  const int rssi = WiFi.status() == WL_CONNECTED ? WiFi.RSSI() : 0;
  datagram[34] = static_cast<uint8_t>(constrain(rssi, -128, 127));
  datagram[35] = 0;
  for (uint16_t index = 0; index < cueloop::kSamplesPerFrame; ++index) {
    const uint16_t encoded = static_cast<uint16_t>(samples[index]);
    datagram[cueloop::kHeaderBytes + index * 2] = static_cast<uint8_t>(encoded);
    datagram[cueloop::kHeaderBytes + index * 2 + 1] =
        static_cast<uint8_t>(encoded >> 8);
  }
  cueloop::putBe32(
      datagram + 36,
      cueloop::crc32(datagram + cueloop::kHeaderBytes, cueloop::kPayloadBytes));
  cueloop::putBe32(datagram + 40, cueloop::crc32(datagram, 40));
}

bool writeAll(const uint8_t* data, size_t length) {
  size_t offset = 0;
  const uint32_t started_ms = millis();
  const int socket_fd = receiver_client.fd();
  if (socket_fd < 0) {
    return false;
  }
  while (offset < length && receiver_client.connected()) {
    const int written = send(
        socket_fd,
        data + offset,
        length - offset,
        MSG_DONTWAIT);
    if (written > 0) {
      offset += static_cast<size_t>(written);
      continue;
    }
    if (written < 0 && errno != EAGAIN && errno != EWOULDBLOCK) {
      break;
    }
    if (millis() - started_ms >= kTcpWriteTimeoutMs) {
      break;
    }
    delay(1);
  }
  return offset == length;
}

void sendFrame() {
  const uint16_t battery_mv = readBatteryMillivolts();
  buildDatagram(battery_mv);
  bool sent = false;
  if (streaming_enabled && receiver_connection_active &&
      receiver_client.connected() && WiFi.status() == WL_CONNECTED) {
    uint8_t prefix[kStreamPrefixBytes];
    cueloop::putBe16(prefix, static_cast<uint16_t>(sizeof(datagram)));
    sent = writeAll(prefix, sizeof(prefix)) &&
           writeAll(datagram, sizeof(datagram));
    if (sent) {
      counters.sent_frames++;
      if (restart_frames_remaining > 0) {
        restart_frames_remaining--;
      }
    } else {
      counters.send_failures++;
      closeReceiverConnection(true);
    }
  }
  sequence_number++;
  sample_clock += cueloop::kSamplesPerFrame;
}

bool validateAck(const uint8_t* ack, size_t length) {
  if (length != cueloop::kAckBytes || memcmp(ack, cueloop::kMagic, 4) != 0) {
    return false;
  }
  if (ack[4] != cueloop::kVersion || ack[5] != cueloop::kReceiverAck ||
      cueloop::getBe16(ack + 6) != 0 || cueloop::getBe32(ack + 8) != pod_id) {
    return false;
  }
  return cueloop::getBe32(ack + 20) == cueloop::crc32(ack, 20);
}

void pollAcknowledgements() {
  if (!receiver_connection_active || !receiver_client.connected()) {
    return;
  }
  while (receiver_client.available() > 0) {
    const int value = receiver_client.read();
    if (value < 0) {
      break;
    }
    if (ack_frame_used >= sizeof(ack_frame)) {
      counters.bad_acks++;
      closeReceiverConnection(true);
      return;
    }
    ack_frame[ack_frame_used++] = static_cast<uint8_t>(value);
    if (ack_frame_used == kStreamPrefixBytes &&
        cueloop::getBe16(ack_frame) != cueloop::kAckBytes) {
      counters.bad_acks++;
      closeReceiverConnection(true);
      return;
    }
    if (ack_frame_used == sizeof(ack_frame)) {
      if (validateAck(ack_frame + kStreamPrefixBytes, cueloop::kAckBytes)) {
        counters.valid_acks++;
        last_ack_ms = millis();
        receiver_reachable = true;
        receiver_timeout_reported = false;
      } else {
        counters.bad_acks++;
      }
      ack_frame_used = 0;
    }
  }

  if (streaming_enabled && millis() - last_ack_ms > kReceiverTimeoutMs) {
    receiver_reachable = false;
    if (!receiver_timeout_reported) {
      counters.receiver_timeouts++;
      receiver_timeout_reported = true;
      restart_frames_remaining = 3;
      Serial.println("RECEIVER_TIMEOUT");
      closeReceiverConnection(false);
    }
  }
}

void printStatus() {
  Serial.print("STATUS pod_id=0x");
  Serial.print(pod_id, HEX);
  Serial.print(" wifi_configured=");
  Serial.print(wifi_ssid.isEmpty() ? "no" : "yes");
  Serial.print(" wifi_connected=");
  Serial.print(WiFi.status() == WL_CONNECTED ? "yes" : "no");
  Serial.print(" receiver=");
  Serial.print(receiver_ip);
  Serial.print(':');
  Serial.print(receiver_port);
  Serial.print(" transport=tcp");
  Serial.print(" reachable=");
  Serial.print(receiver_reachable ? "yes" : "no");
  Serial.print(" source=");
  Serial.print(test_tone_enabled ? "test-tone" : "microphone");
  Serial.print(" power_mode=");
  Serial.print(usb_powered_mode ? "usb" : "battery");
  Serial.print(" stream=");
  Serial.println(streaming_enabled ? "on" : "off");
  Serial.print("COUNTERS captured=");
  Serial.print(counters.captured_frames);
  Serial.print(" sent=");
  Serial.print(counters.sent_frames);
  Serial.print(" send_failures=");
  Serial.print(counters.send_failures);
  Serial.print(" capture_errors=");
  Serial.print(counters.capture_errors);
  Serial.print(" wifi_attempts=");
  Serial.print(counters.wifi_attempts);
  Serial.print(" wifi_reconnects=");
  Serial.print(counters.wifi_reconnects);
  Serial.print(" receiver_connect_attempts=");
  Serial.print(counters.receiver_connect_attempts);
  Serial.print(" receiver_reconnects=");
  Serial.print(counters.receiver_reconnects);
  Serial.print(" valid_acks=");
  Serial.print(counters.valid_acks);
  Serial.print(" bad_acks=");
  Serial.print(counters.bad_acks);
  Serial.print(" receiver_timeouts=");
  Serial.print(counters.receiver_timeouts);
  Serial.print(" clipped_samples=");
  Serial.print(counters.clipped_samples);
  Serial.print(" audio_rms=");
  Serial.print(last_audio_rms);
  Serial.print(" audio_peak=");
  Serial.print(last_audio_peak);
  Serial.print(" rssi_dbm=");
  Serial.print(WiFi.status() == WL_CONNECTED ? WiFi.RSSI() : 0);
  Serial.print(" free_heap=");
  Serial.println(ESP.getFreeHeap());
}

bool parseOnOff(const String& value, bool& output) {
  if (value.equalsIgnoreCase("ON")) {
    output = true;
    return true;
  }
  if (value.equalsIgnoreCase("OFF")) {
    output = false;
    return true;
  }
  return false;
}

void handleCommand(const String& command) {
  if (command == "HELP") {
    Serial.println(
        "COMMANDS: STATUS | SET_WIFI<TAB>ssid<TAB>password | "
        "SET_RECEIVER<TAB>ipv4<TAB>port | SET_POD_ID<TAB>id | "
        "TEST<TAB>ON|OFF | STREAM<TAB>ON|OFF | POWER<TAB>USB|BATTERY | ERASE");
    return;
  }
  if (command == "STATUS") {
    printStatus();
    return;
  }
  if (command == "ERASE") {
    preferences.clear();
    Serial.println("CONFIG_ERASED restarting");
    delay(100);
    ESP.restart();
  }
  if (command.startsWith("SET_WIFI\t")) {
    const int separator = command.indexOf('\t', 9);
    if (separator < 0) {
      Serial.println("ERROR SET_WIFI requires SSID and password separated by tabs");
      return;
    }
    const String new_ssid = command.substring(9, separator);
    const String new_password = command.substring(separator + 1);
    if (new_ssid.isEmpty() || new_ssid.length() > 32 || new_password.length() > 64) {
      Serial.println("ERROR invalid SSID/password length");
      return;
    }
    preferences.putString("ssid", new_ssid);
    preferences.putString("password", new_password);
    wifi_ssid = new_ssid;
    wifi_password = new_password;
    wifi_retry_ms = kMinimumWifiRetryMs;
    last_wifi_attempt_ms = millis() - wifi_retry_ms;
    Serial.println("WIFI_SAVED password_not_echoed");
    return;
  }
  if (command.startsWith("SET_RECEIVER\t")) {
    const int separator = command.indexOf('\t', 13);
    if (separator < 0) {
      Serial.println("ERROR SET_RECEIVER requires IPv4 and port");
      return;
    }
    IPAddress candidate;
    const String ip_text = command.substring(13, separator);
    const long port = command.substring(separator + 1).toInt();
    if (!candidate.fromString(ip_text) || port < 1 || port > 65535) {
      Serial.println("ERROR invalid receiver IPv4/port");
      return;
    }
    receiver_ip = candidate;
    receiver_port = static_cast<uint16_t>(port);
    preferences.putString("receiver_ip", ip_text);
    preferences.putUShort("receiver_port", receiver_port);
    closeReceiverConnection(false);
    receiver_retry_ms = kMinimumReceiverRetryMs;
    last_receiver_attempt_ms = millis() - receiver_retry_ms;
    Serial.println("RECEIVER_SAVED");
    return;
  }
  if (command.startsWith("SET_POD_ID\t")) {
    char* end = nullptr;
    const uint32_t candidate = strtoul(command.substring(11).c_str(), &end, 0);
    if (candidate == 0 || end == nullptr || *end != '\0') {
      Serial.println("ERROR invalid pod ID");
      return;
    }
    pod_id = candidate;
    preferences.putULong("pod_id", pod_id);
    beginNewStream();
    Serial.println("POD_ID_SAVED");
    return;
  }
  if (command.startsWith("TEST\t")) {
    bool value = false;
    if (!parseOnOff(command.substring(5), value)) {
      Serial.println("ERROR TEST expects ON or OFF");
      return;
    }
    test_tone_enabled = value;
    preferences.putBool("test_tone", value);
    next_test_frame_us = micros();
    beginNewStream();
    Serial.println(value ? "TEST_TONE_ON" : "TEST_TONE_OFF");
    return;
  }
  if (command.startsWith("STREAM\t")) {
    bool value = false;
    if (!parseOnOff(command.substring(7), value)) {
      Serial.println("ERROR STREAM expects ON or OFF");
      return;
    }
    streaming_enabled = value;
    preferences.putBool("streaming", value);
    beginNewStream();
    if (value) {
      last_ack_ms = millis();
      receiver_timeout_reported = false;
      receiver_retry_ms = kMinimumReceiverRetryMs;
      last_receiver_attempt_ms = millis() - receiver_retry_ms;
    } else {
      closeReceiverConnection(false);
    }
    Serial.println(value ? "STREAM_ON" : "STREAM_OFF");
    return;
  }
  if (command.startsWith("POWER\t")) {
    const String value = command.substring(6);
    if (value.equalsIgnoreCase("USB")) {
      usb_powered_mode = true;
    } else if (value.equalsIgnoreCase("BATTERY")) {
      usb_powered_mode = false;
    } else {
      Serial.println("ERROR POWER expects USB or BATTERY");
      return;
    }
    preferences.putBool("usb_mode", usb_powered_mode);
    Serial.println(usb_powered_mode ? "POWER_MODE_USB" : "POWER_MODE_BATTERY");
    return;
  }
  Serial.println("ERROR unknown command; send HELP");
}

void pollSerial() {
  while (Serial.available()) {
    const char character = static_cast<char>(Serial.read());
    if (character == '\r') {
      continue;
    }
    if (character == '\n') {
      if (!serial_line.isEmpty()) {
        handleCommand(serial_line);
        serial_line = "";
      }
      continue;
    }
    if (serial_line.length() >= kMaximumSerialCommand) {
      serial_line = "";
      Serial.println("ERROR command too long");
      continue;
    }
    serial_line += character;
  }
}

}  // namespace
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
void loop() {
  pollSerial();
  maintainWifi();
  maintainReceiverConnection();
  pollAcknowledgements();

  if (captureFrame()) {
    if (streaming_enabled) {
      sendFrame();
    } else {
      sequence_number++;
      sample_clock += cueloop::kSamplesPerFrame;
    }
  }

  const uint32_t now = millis();
  if (now - last_diagnostics_ms >= kDiagnosticsIntervalMs) {
    last_diagnostics_ms = now;
    printStatus();
  }
}

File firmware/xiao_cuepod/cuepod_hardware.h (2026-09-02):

#pragma once

#if __has_include("cuepod_hardware.local.h")
#include "cuepod_hardware.local.h"
#endif

#ifndef CUELOOP_PDM_CLOCK_PIN
// Seeed Studio's Arduino-ESP32 3.x documentation for the XIAO ESP32S3 Sense
// expansion board specifies GPIO42 as PDM clock and GPIO41 as PDM data.
#define CUELOOP_PDM_CLOCK_PIN 42
#endif
#ifndef CUELOOP_PDM_DATA_PIN
#define CUELOOP_PDM_DATA_PIN 41
#endif

// The installed XIAO_ESP32S3 board variant does not expose a verified battery
// ADC definition. Leave telemetry invalid rather than invent a voltage. A
// physical revision with a measured divider may override all three values in
// a local ignored cuepod_hardware.local.h file.
#ifndef CUELOOP_BATTERY_ADC_PIN
#define CUELOOP_BATTERY_ADC_PIN -1
#endif
#ifndef CUELOOP_BATTERY_SCALE_NUMERATOR
#define CUELOOP_BATTERY_SCALE_NUMERATOR 1
#endif
#ifndef CUELOOP_BATTERY_SCALE_DENOMINATOR
#define CUELOOP_BATTERY_SCALE_DENOMINATOR 1
#endif

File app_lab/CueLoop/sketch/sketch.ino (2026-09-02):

// CueLoop deterministic physical-cue controller for the UNO Q STM32U585.

#include <Arduino.h>
#include <Arduino_RouterBridge.h>

#include "cue_controller_hardware.h"

namespace {

constexpr uint32_t kLinuxHeartbeatTimeoutMs = 6000;
constexpr uint32_t kStatusNotifyIntervalMs = 5000;
constexpr uint32_t kDebounceMs = 35;
constexpr size_t kMaximumEventIdLength = 64;

enum EventClass : int {
  kDoorKnock = 1,
  kAlarmBeep = 2,
  kDogBark = 3,
  kAttentionCall = 4,
};

struct CueState {
  String event_id;
  int class_code = 0;
  int priority = 0;
  int confidence_permille = 0;
  bool active = false;
  bool muted = false;
  uint32_t started_ms = 0;
};

CueState cue;
bool bridge_ready = false;
bool linux_healthy = false;
uint32_t last_linux_heartbeat_ms = 0;
uint32_t last_status_notify_ms = 0;
uint32_t accepted_cues = 0;
uint32_t rejected_cues = 0;
uint32_t button_acknowledgements = 0;
bool last_button_reading = HIGH;
bool stable_button_state = HIGH;
uint32_t last_button_change_ms = 0;

void setLed3(uint8_t red, uint8_t green, uint8_t blue) {
  // UNO Q LED3 PWM polarity is declared inverted by the official board core;
  // the documented API accepts 0=off, 255=full for each color.
  analogWrite(LED3_R, red);
  analogWrite(LED3_G, green);
  analogWrite(LED3_B, blue);
}

void setLed4(bool red, bool green, bool blue) {
  // LED4 is active low.
  digitalWrite(LED4_R, red ? LOW : HIGH);
  digitalWrite(LED4_G, green ? LOW : HIGH);
  digitalWrite(LED4_B, blue ? LOW : HIGH);
}

bool validClassCode(int class_code) {
  return class_code >= kDoorKnock && class_code <= kAttentionCall;
}

bool startCue(String event_id, int class_code, int priority, int confidence_permille) {
  if (event_id.isEmpty() || event_id.length() > kMaximumEventIdLength ||
      !validClassCode(class_code) || priority < 1 || priority > 3 ||
      confidence_permille < 0 || confidence_permille > 1000) {
    rejected_cues++;
    return false;
  }
  cue.event_id = event_id;
  cue.class_code = class_code;
  cue.priority = priority;
  cue.confidence_permille = confidence_permille;
  cue.active = true;
  cue.started_ms = millis();
  accepted_cues++;
  return true;
}

bool clearCue(String event_id) {
  if (!cue.active) {
    return true;
  }
  if (!event_id.isEmpty() && event_id != cue.event_id) {
    return false;
  }
  cue.active = false;
  cue.event_id = "";
  setLed3(0, 0, 0);
#if CUELOOP_HAPTIC_PIN >= 0
  digitalWrite(CUELOOP_HAPTIC_PIN, LOW);
#endif
#if CUELOOP_BUZZER_PIN >= 0
  noTone(CUELOOP_BUZZER_PIN);
#endif
  return true;
}

bool setMuted(bool muted) {
  cue.muted = muted;
  if (muted) {
    setLed3(0, 0, 0);
  }
  return cue.muted;
}

uint32_t linuxHeartbeat(uint32_t /* linux_uptime_ms */) {
  last_linux_heartbeat_ms = millis();
  linux_healthy = true;
  return millis();
}

String controllerStatus() {
  String result = "v1;bridge=";
  result += bridge_ready ? "ready" : "down";
  result += ";linux=";
  result += linux_healthy ? "healthy" : "timeout";
  result += ";active=";
  result += cue.active ? "yes" : "no";
  result += ";muted=";
  result += cue.muted ? "yes" : "no";
  result += ";accepted=";
  result += accepted_cues;
  result += ";rejected=";
  result += rejected_cues;
  result += ";button_acks=";
  result += button_acknowledgements;
  return result;
}

bool cuePulseOn(uint32_t elapsed_ms, int priority) {
  if (priority == 3) {
    const uint32_t phase = elapsed_ms % 1400;
    return phase < 180 || (phase >= 300 && phase < 480) ||
           (phase >= 600 && phase < 780);
  }
  if (priority == 2) {
    const uint32_t phase = elapsed_ms % 1800;
    return phase < 220 || (phase >= 420 && phase < 640);
  }
  return elapsed_ms % 2200 < 300;
}

void classColor(int class_code, uint8_t brightness, uint8_t& red, uint8_t& green,
                uint8_t& blue) {
  red = 0;
  green = 0;
  blue = 0;
  switch (class_code) {
    case kDoorKnock:
      green = static_cast<uint8_t>(brightness * 3 / 4);
      blue = brightness;
      break;
    case kAlarmBeep:
      red = brightness;
      break;
    case kDogBark:
      red = static_cast<uint8_t>(brightness / 4);
      green = static_cast<uint8_t>(brightness / 3);
      blue = brightness;
      break;
    case kAttentionCall:
      red = brightness;
      green = static_cast<uint8_t>(brightness / 2);
      break;
    default:
      red = brightness;
      green = brightness;
      blue = brightness;
      break;
  }
}

void updateCueOutputs() {
  if (!cue.active || cue.muted) {
    setLed3(0, 0, 0);
#if CUELOOP_HAPTIC_PIN >= 0
    digitalWrite(CUELOOP_HAPTIC_PIN, LOW);
#endif
#if CUELOOP_BUZZER_PIN >= 0
    noTone(CUELOOP_BUZZER_PIN);
#endif
    return;
  }
  const bool pulse_on = cuePulseOn(millis() - cue.started_ms, cue.priority);
  if (!pulse_on) {
    setLed3(0, 0, 0);
#if CUELOOP_HAPTIC_PIN >= 0
    digitalWrite(CUELOOP_HAPTIC_PIN, LOW);
#endif
#if CUELOOP_BUZZER_PIN >= 0
    noTone(CUELOOP_BUZZER_PIN);
#endif
    return;
  }
  const uint8_t brightness = static_cast<uint8_t>(
      64 + static_cast<uint32_t>(cue.confidence_permille) * 191 / 1000);
  uint8_t red = 0;
  uint8_t green = 0;
  uint8_t blue = 0;
  classColor(cue.class_code, brightness, red, green, blue);
  setLed3(red, green, blue);
#if CUELOOP_HAPTIC_PIN >= 0
  digitalWrite(CUELOOP_HAPTIC_PIN, HIGH);
#endif
#if CUELOOP_BUZZER_PIN >= 0
  tone(CUELOOP_BUZZER_PIN, cue.priority == 3 ? 1800 : 1200);
#endif
}

void updateHealthLed() {
  if (!bridge_ready || !linux_healthy) {
    const bool on = millis() % 1000 < 400;
    setLed4(on, false, false);
    return;
  }
  if (cue.muted) {
    setLed4(false, false, true);
    return;
  }
  setLed4(false, true, false);
}

void acknowledgeFromButton() {
  if (!cue.active) {
    return;
  }
  const String event_id = cue.event_id;
  clearCue(event_id);
  button_acknowledgements++;
  if (bridge_ready) {
    Bridge.notify("cueloop/ack", event_id);
  }
}

void pollButton() {
  const bool reading = digitalRead(CUELOOP_ACK_BUTTON_PIN);
  if (reading != last_button_reading) {
    last_button_change_ms = millis();
    last_button_reading = reading;
  }
  if (millis() - last_button_change_ms >= kDebounceMs &&
      reading != stable_button_state) {
    stable_button_state = reading;
    if (stable_button_state == LOW) {
      acknowledgeFromButton();
    }
  }
}

}  // namespace
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

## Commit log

2026-09-02 feat(cad): add native Fusion production pipeline
    [Alert_Diffuser.step, Alert_Diffuser.stl, CueLoop_Reference.FCStd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]
2026-09-05 fix(cad): tolerate immutable Fusion root names
2026-09-05 fix(cad): accept Windows source line endings
2026-09-06 docs(cad): record Fusion execution evidence
2026-09-08 fix(audio): calibrate physical alarm detection
    [xiao_cuepod.ino]
